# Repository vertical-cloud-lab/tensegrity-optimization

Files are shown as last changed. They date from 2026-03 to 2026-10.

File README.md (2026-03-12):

# BYU Mentored Research Grant Proposal: Multi-Material 3D-Printed Tensegrity Structures

**Bayesian Optimization of Multi-Material 3D-Printed Tensegrity Structures for Energy Absorption**

BYU Ira A. Fulton College of Engineering — Mentored Research Grant Proposal

## Overview

- **PI:** Jeffrey R. Hill, Mechanical Engineering
- **Co-PI:** Sterling G. Baird, Mechanical Engineering
- **Duration:** 2 years
- **Budget:** $25,000
- **Students:** 2–3 undergraduates + 1 graduate co-mentor
- **Focus:** Undergraduate mentored research

This proposal develops a multifidelity Bayesian optimization framework to design multi-material 3D-printed tensegrity structures (PLA struts + TPU tension elements) optimized for energy absorption. Undergraduate students fabricate and experimentally validate optimized designs through compaction tests, drop tests, and wave propagation measurements.

## Repository Structure

```
├── proposal.tex              # Main LaTeX document
├── references.bib            # BibTeX bibliography
├── sections/
│   ├── coverpage.tex         # MRG cover page (abstract, budget table, external funding)
│   ├── budget.tex            # Budget table and justification
│   └── biosketch.tex         # PI and Co-PI biographical sketches
├── Makefile                  # Build commands
├── .gitignore
└── README.md
```

## Building the Proposal

Requires a LaTeX distribution (e.g., TeX Live, MiKTeX) with `pdflatex` and `bibtex`.

```bash
# Using Make
make

# Or manually
pdflatex proposal
bibtex proposal
pdflatex proposal
pdflatex proposal
```

## Proposal Structure (≤5 pages + cover page, references, bio sketches)

- **Cover Page** — Title, PI/Co-PI, abstract, student counts, budget summary, relationship to external funding
- **Research Motivation & Overview** — Multi-material 3D-printed tensegrity + multifidelity BO
- **Background** — Tensegrity structures, Bayesian optimization, Mo et al. (2023) multifidelity framework
- **Student Research Project 1** — Simulation & Bayesian optimization
- **Student Research Project 2** — Fabrication, CAD, & experimental testing
- **Mentoring Environment** — Weekly meetings, graduate co-mentor, peer mentoring, progressive responsibility
- **Expected Research Outcomes** — UCUR, ASME IDETC, journal submission, NSF proposal
- **Potential Impact** — Protective equipment, packaging, aerospace applications
- **Timeline** — 4-semester project plan
- **Budget** — $25k (undergraduate wages, graduate wages, supplies, travel, other)
- **References** — (does not count toward page limit)
- **Bio Sketches** — Hill & Baird (does not count toward page limit)

## TODO

- [ ] Add figures (tensegrity schematic, BO loop diagram, test setup)
- [ ] Finalize PI/Co-PI bio sketch details (specific publications, appointments)
- [ ] Get feedback from co-PI / collaborators

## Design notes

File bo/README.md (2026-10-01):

# T-3_01 Sobol batch: print key, slicer files, and BO campaign script

This directory holds the key linking each printed T3-prism specimen ID to its
Sobol design parameters, for use when parsing drop data during the testing
campaign (issue [#98](https://github.com/vertical-cloud-lab/tensegrity-optimization/issues/98)),
plus the Bayesian-optimization script that ingests the campaign results and
suggests the next print batch.

## BO campaign files

- `t3_prism_bo_campaign.py`: Honegumi-templated Ax script (multi-objective,
  fully Bayesian SAASBO, batch, existing data, visualization). Ingests the
  measured drop results, attaches them as completed Ax trials, attaches
  printed-but-untested specs as pending trials, and records the next
  suggested batch. The rebound objective is the absolute energy returned to
  the payload per drop (`e_reb_mJ = e_rebound * m_printed * g * h`), computed
  from each article's own weighed mass, and its noise folds in the
  print-to-print mass scatter measured from the spec-08 triplicate. See the
  docstring for the objective rationale (why `t180` stays a ratio) and the
  seven documented deviations from the rendered template. From round 3 the
  search space also carries six print-process parameters, with the four
  filament-level ones taking one Sobol-drawn value for the whole batch; see
  the print-process section below. Run from the repo
  root: `python bo/t3_prism_bo_campaign.py --round 3`.
- `t3_prism_mass_model.py`: the as-printed mass model, and the
  constant-printed-mass projection built on it. **What round 1 actually held
  constant was solid mass, not volume and not printed grams**: PR #35's
  Route A uniformly re-scales each design until
  `rho_PLA * V_PLA + rho_TPU * V_TPU = 30.95 g` (the solid mass of the S0
  reference STLs), converged to 0.15 g on rendered STL volumes. All 9
  articles sit at that solid mass and still weigh 18.50 to 22.29 g, because
  PLA prints sparse while thin TPU cables print near solid and the PLA/TPU
  split swings from 20.0/10.9 g to 27.3/3.6 g across the batch. This module
  calibrates the gap in two stages (analytic volumes against the 9 rendered
  designs, then rendered solid grams against the 12 weighed articles using a
  wall-plus-infill term in the as-printed strut diameter) and inverts it, so
  a design can be projected onto a constant *printed* mass with a closed
  bisection and no slicer in the loop. Since 2026-08-26 the two infill
  percentages are inputs to that solve rather than fitted constants, because
  a sparser article has to be larger to weigh the same. Residual sd 0.378 g, at or below the
  0.457 g print-to-print scatter, versus 0.927 g for a flat pair of density
  factors. `python bo/t3_prism_mass_model.py` prints the calibration report
  and re-projects the 9 round-1 articles.

- `t3_prism_printed_mass_plate.py`: renders the actual print files (per-trial
  STL pairs, plate previews and the Bambu H2D multi-material project) for a
  solved constant-printed-mass suggestions CSV, at the CSV's own solved scale
  with no mass re-solve. See "Round-3 print files" below for what it produced
  and how the output was verified. `python bo/t3_prism_printed_mass_plate.py`
  (needs `openscad` and `xvfb`; about 25 minutes, mostly OpenSCAD).

- `t3_prism_slicer_settings.py`: reads the print-process settings back out of
  a Bambu Studio `.3mf` project (process profile, layer height, line width,
  sparse infill, wall loops, and per-filament nozzle temperature and max
  volumetric speed, plus any per-object or per-part overrides). It is what
  makes `AS_PRINTED_PROCESS` in the campaign script auditable rather than a
  hard-coded constant, and it is what round 4 should run on the round-3 plates
  to record what they were actually sliced at rather than what they were asked
  for. `python bo/t3_prism_slicer_settings.py bo/slices/*.3mf [--csv out.csv]
  [--raw]`.

- `t3-prism-bo-batch-drop-results.csv`: snapshot of the BO-ready
  `campaign_summary.csv` produced on PR #86 (branch
  `copilot/add-drop-test-protocol-again`, commit `642b8c0`, path
  `data/drop-tests/sobol-campaign/figures/campaign_summary.csv`): one row
  per tested specimen with objectives (mean and sd) and joined as-printed
  geometry. 8 of 9 specimens as of 2026-08-21; `amdjwm` has no known spec
  mapping and is skipped by the script until identified. The `ajhby6` row
  (spec 07, the specimen missing from the PR #86 snapshot) was appended on
  2026-08-24 from its Box upload, computed with the same PR #86 analysis
  script; see the round-2 section below for the fetch provenance.
- `t3-prism-bo-suggestions-round1.csv`: the recorded round-1 output of the
  script. Per suggested design: the base (shape) coordinates, the constant
  `mass_printed_g` target, posterior-mean predictions for both objectives,
  the implied rebound fraction at that mass (`pred_e_rebound_approx`, for
  comparison with the raw `e_rebound` column of the results CSV), and the
  as-printed geometry the constant-printed-mass projection produces
  (`scale`, `*_print_mm`, `solid_mass_g`) with PR #35's two printability
  checks evaluated on it (`envelope_ok` for the 250 cm^3 cylinder,
  `cable_bridge_ok` for the 3.0 mm TPU self-bridging floor). Violations are
  flagged, not dropped, exactly as in round 1.
- `t3-prism-bo-ax-client-round1.json`: full AxClient state (experiment,
  data, generation strategy) for reproducibility and warm-starting round 2.
- `figures/t3-prism-bo-round1-pareto.png`: objective-space view (tested
  articles labeled by print ID, the Pareto front through the non-dominated
  articles, and the suggested round-2 candidates at their predicted means),
  styled for slides. The parameter-space parallel-coordinates panel that the
  Honegumi template pairs with it was dropped on review (PR #102). The front
  drawn is the non-dominated set of the observed points, which for round 1 is
  the same three articles (`6lhxfy`, `6nheas`, `bpx68c`) that Ax's
  model-predicted Pareto set picks out. Redraw it without refitting the model
  (pandas + matplotlib only, no Ax install needed) with
  `python bo/t3_prism_bo_campaign.py --plot-only`. Styling follows the
  hand-made reference on PR #102: no legend box (series are named by
  leader-line callouts in the plot area), detached left and bottom spines,
  no gridlines, gray print IDs, horizontal y-axis label above the axis. Both
  axis labels mark the good direction with a down-arrow glyph rather than the
  words "lower is better" (PR #102 review); it is set as `ARROW_DOWN` in the
  script, and matplotlib falls through the sans-serif list per character if a
  machine's chosen face lacks U+2193. **Every figure written by either script
  is 300 dpi** (`FIGURE_DPI` in `t3_prism_bo_campaign.py`, imported by the
  diagnostics), so they hold up on a projector and in a printed deck. Print
  IDs are placed by a search that dodges the markers, the other IDs, the
  callout text, the callout leaders and the front line, weighted so that a
  label would rather cross a hairline than sit on top of words; nothing here
  is hand-positioned, because the point cloud moves every round.
- **Prototype, synthetic data.** Four stills and an animation showing the
  layout the campaign will want once round 2 comes back, written by one run of
  `python bo/t3_prism_bo_campaign.py --prototype-next-round`. No round-2
  article has been printed or dropped, so the outcomes are drawn from the
  model's own predictive distribution at 0.3 sd (a full draw scatters the
  batch off the panel) and recorded to
  `t3-prism-bo-round2-outcomes-PROTOTYPE-dummy.csv`. Replace
  `synthesize_round2_outcomes` with the measured campaign summary to turn this
  into the real figure.

  The four stills are the four points at which the figure is at rest, in
  slide order:

  1. `figures/t3-prism-bo-round2-start-PROTOTYPE.png`: the round-1 figure. Its
     front, its print IDs, and the orange suggested points.
  2. `figures/t3-prism-bo-round2-uncertainty-PROTOTYPE.png`: the predicted
     uncertainties at the suggested points, frozen before anything moves
     (PR #102 review): a horizontal and a vertical bar spanning plus or minus
     1 sd per objective, and a shaded oval through the same contour, both in
     faded shades of the suggestion orange. The sd is **1 posterior standard
     deviation of the model's noise-free objective prediction** (the square
     root of the diagonal of the covariance `TorchModelBridge.predict`
     returned when the batch was generated, averaged over the SAAS MCMC
     draws). It is epistemic model uncertainty, not a standard error of any
     sample of drops. Only the per-objective marginals were recorded to the
     suggestions CSV, so the oval is axis-aligned; the cross-objective
     covariance `predict` also returns was not saved. Several rebound-energy
     sds are taller than the panel and simply crop at the axes, which is the
     honest picture: the LOOCV diagnostic found no out-of-sample skill on
     that objective, and these ovals are the same fact drawn in objective
     space.
  3. `figures/t3-prism-bo-round2-predicted-vs-actual-PROTOTYPE.png`: each
     orange diamond (predicted) joined by a straight path to the open black
     circle where that article actually landed. No front and no print IDs. The
     round-1 front has been retired and the round-2 front has not been computed
     yet; the IDs are retired with it, because seventeen of them over the
     travel paths is the crowding the beat list exists to avoid (PR #102
     review). The uncertainty layer stays anchored at the predictions at ghost
     opacity, so predicted-band-versus-landing is readable. Identity comes
     back on still 4.
  4. `figures/t3-prism-bo-round2-front-final-PROTOTYPE.png`: the prediction
     layer gone, the print IDs back, and the front recomputed over both rounds.
     The frame to use when the point is the new front rather than how the model
     did.

  All four are **frames of one figure** rather than four separate drawings,
  exported at 300 dpi (3300 x 2100 px, with that dpi written into the PNG so
  PowerPoint places them at 11 x 7 in) and with no tight bounding box. That
  makes them the same pixel size and puts every element that survives a beat
  (the axes, the ticks, the axis labels, and each print ID) at the same pixel
  in all four, so
  they can go on four consecutive slides and be cross-faded or morphed without
  anything sliding. Drawing them independently could not guarantee that, since
  each panel would solve its own label placement; labels are laid out once,
  against the final frame, for the whole set.
- `figures/t3-prism-bo-round2-predicted-vs-actual-PROTOTYPE.gif` and
  `.mp4`: the same four stills played out in time, which is how it is meant to
  be shown. Choreographed one idea per beat, after the PR #102 review found
  the first cut had too much moving and too much text on screen at once:
  hold on the round-1 figure (1.3 s, still 1), retire the round-1 front, its
  callouts and every print ID with nothing else moving (0.9 s), grow the
  plus-or-minus-1-sd bars and ovals in and freeze so they can be read
  (0.7 s + 1.4 s, still 2), travel the
  diamonds to their measurements while the uncertainty layer fades to ghost
  opacity at the predictions (2.6 s), hold on
  predicted versus measured (1.7 s, still 3), clear the prediction layer and
  its uncertainties
  (0.9 s), redraw the new front as its own step, wiping in along the polyline
  and filling each article as it reaches it (1.3 s), bring every ID back at
  once now that nothing is moving, and rest (2.4 s, still 4). About 13 s. At
  most one callout is ever lit while anything is in motion, and nothing is
  labeled while anything is moving (eight IDs is fine on the round-1 slide,
  but carrying them through the travel while nine more arrive is not). The
  MP4 is 3300 x 2100 at 25 fps (h.264, yuv420p, so it plays in PowerPoint and
  Keynote as well as a browser), pixel-for-pixel the same canvas as the
  stills. Add `--no-animation` to write only the stills. The MP4 needs
  `ffmpeg` on PATH (`apt-get install ffmpeg`); without it the script falls
  back to a Pillow-written GIF and skips the MP4. The GIF is built from the
  MP4 with an ffmpeg palette pass (12 fps, 1280 px wide) and is for threads
  and this README, not for slides; use the MP4 there.

### Constant printed mass, and the `fit_out_of_design` kwarg it needs

The search space is 6-dimensional. The first five are PR #35's base Sobol
coordinates with the joint diameter frozen at 7 mm; since the projection
re-scales every dimension including the joint, those five fix the article's
*shape*. The sixth, `mass_printed_g`, fixes its *size*: the projection solves
for the uniform scale that hits that printed mass. Shape and mass together
determine the article exactly, which is what makes "hold the mass constant"
expressible at all.

That splits the space in two. The **fit space** carries `mass_printed_g` over
18.0 to 23.0 g, covering every weighed round-1 article. The **generation
space** pins it to the target (default 20.23 g, the weighed mass of the S0
reference `bpx68c`; `--target-mass-g` overrides). Round-1 data therefore sits
outside the generation space along the mass axis, so:

- the experiment is created on the fit space and the trials attached there,
  because `attach_trial` validates search-space membership and would raise
  long before any model exists;
- the search space is then narrowed, which needs
  `immutable_search_space_and_opt_config=False`;
- the SAASBO step gets
  `model_kwargs={"fit_out_of_design": True, "expand_model_space": True}`, so
  those out-of-design observations are still used to fit while `gen` stays
  inside the narrowed space (facebook/Ax#768). `fit_out_of_design` is
  deprecated after Ax 1.1.2, where `expand_model_space` alone is the live
  mechanism, so this pairing is correct for the pinned 0.5.0 and needs
  revisiting if the pin moves.

The generation slab is +/- 0.01 g rather than a `FixedParameter` or the
+/- 0.457 g print tolerance, for two separate reasons. A `FixedParameter`
would be stripped by Ax's `RemoveFixed` transform, taking the mass dimension
out of the model entirely, and the model needs it: attributing part of the
round-1 objective spread to mass rather than to shape is the whole point. And
a slab as wide as the print tolerance has an exploitable gradient, since
rebound energy scales with mass; with +/- 0.457 g, qNEHVI put all 9
suggestions on the light edge, choosing shapes at 19.77 g and then reporting
them at 20.23 g. The printer's tolerance is not a design variable.

One limitation this does not fix. Round-1 articles were built under the old
projection, so the same coordinates map to slightly different physical
articles now (re-projected scales move by up to 3.5 percent). Carrying
measured mass as the sixth parameter lets the model account for that instead
of silently averaging over it, but it is not the same as re-fitting on
as-printed geometry (facebook/Ax#3577, planned-vs-executed parameters, still
unimplemented upstream).

Resolved 2026-08-31: `bo/t3_prism_printed_mass_plate.py` takes exactly that
shorter path (this paragraph used to be the standing "re-point Route A at
printed grams" blocker). It renders each design's SCAD at its own base
coordinates and the CSV's solved `scale`, so the constant-printed-mass
projection the campaign computed is honored as-is and nothing re-solves onto
solid mass at render time. From round 3 the scale also depends on the
article's strut infill, which is why the CSV's solved value, not the shape,
is the input of record. See "Round-3 print files" below.

### Print-process parameters, and why the filament settings are one value per batch

Six slicer settings became design variables on 2026-08-26 (PR #102). They had
been stock defaults nobody chose: both tested plates were sliced from Bambu's
`0.30mm Standard @BBL H2D 0.6 nozzle` process at 15 percent grid sparse infill,
2 wall loops, 0.30 mm layers and 0.62 mm line width, with PLA Basic at 220 C
and 30 mm^3/s and TPU 85A at 240 C and 2.5 mm^3/s. Those numbers are read
straight out of `Metadata/project_settings.config` in the two committed slicer
projects, and they are identical in both, so **all 17 tested articles sit at
one point of this six-dimensional space** and the round-3 batch is its
initialization rather than an optimization of it.

The bounds were tightened on 2026-08-31 (PR #102 review): the first draw of
the batch-wide filament settings landed at 247 C TPU at the high-flow
hotend's full 4.8 mm^3/s rating, which risked the #96 carbonization failure
and the untested flow ceiling in the same print. Every range now brackets
the proven operating point instead of reaching for the preset or hardware
limits. The original ranges (infill 10 to 60 %, PLA 200 to 235 C and 15 to
30 mm^3/s, TPU 230 to 250 C and 2.0 to 4.8 mm^3/s) are recorded here and in
the `PROCESS_SPECS` block so a later round can widen deliberately once one
round of process data exists.

| Parameter | Bounds | Set at | Slicer field | Why these bounds |
|---|---|---|---|---|
| `strut_infill_pct` | 12 to 35 % | 15 | sparse infill density, `-struts` part | brackets the stock 15; 35 keeps the printed-mass model near its one calibration point (its infill term is unvalidated differential physics) and keeps the constant-mass projection from shrinking dense articles onto the fixed-size sensor housings |
| `tpu_infill_pct` | 12 to 35 % | 15 | sparse infill density, `-cables` part | same range; still spans a soft to a firm captive core (the hollow lock ball photographed on issue #85) without leaving the mass model's comfort zone |
| `pla_nozzle_temp_C` | 212 to 228 C | 220 | PLA filament nozzle temperature | plus or minus 8 around the proven 220 (Bambu PLA Basic's own preset window is 190 to 240); cold plus fast risks underextrusion through the 0.6 nozzle, hot strings across the tendons, and neither failure needs to be found in a batch of test articles |
| `pla_flow_mm3_s` | 20 to 30 mm^3/s | 30 | PLA filament max volumetric speed | 30 is the vendor value both plates ran at and stays the ceiling; the floor is two thirds of it rather than the old half, so the batch cannot pair its coldest nozzle with a flow far from anything ever printed here |
| `tpu_nozzle_temp_C` | 235 to 245 C | 240 | TPU filament nozzle temperature | plus or minus 5 around the 240 both plates ran at (the generic Bambu TPU 85A @BBL H2D preset allows 200 to 250); the old 250 top was backed off because of the #96 hotend-carbonization history |
| `tpu_flow_mm3_s` | 2.2 to 3.6 mm^3/s | 2.5 | TPU filament max volumetric speed | 2.2 sits just below the 2.5 both plates ran at; 3.6 is 75 percent of the high-flow hotend's 4.8 mm^3/s rating (issue #96), so the round probes the new hotend's headroom without spending all of it in one go at an untested temperature |

Where those "set at" numbers come from, so they can be checked rather than
believed: `python bo/t3_prism_slicer_settings.py bo/slices/*.3mf` reads them
back out of the two committed slicer projects and writes
`t3-prism-slicer-process-settings.csv`. Both projects report the same process
profile and the same values on the two slots any object prints with (PLA on
extruder 1 at 220 C and 30 mm^3/s, TPU on extruder 2 at 240 C and
2.5 mm^3/s), and neither carries a single per-object or per-part override.
`slices/t3-prism-bo-round1.H2D-MM-PLAstruts-TPUcables_manual-supports.3mf` is
the r2d2c plate, posted to issue #98 on 2026-08-24 and byte-identical
(sha256 `4a7bc1a0…`) to the copy committed at `8809b25` on the
`copilot/get-bambu-sliced-print-t3-prism` branch; it is copied here so this
branch can be checked without fetching that one.

Two things the extractor turns up that are worth acting on independently of
the BO. The TPU slot still uses the `Bambu TPU 85A @BBL H2D 0.4 nozzle`
preset, left over from before the high-flow hotend went in on 2026-08-17, and
that preset caps the temperature window at 240 C; the generic
`@BBL H2D` preset allows 200 to 250, so the round-3 batch, which asks for
244 C, needs the preset swapped, not just the number typed. And the TPU had
been running at 2.5 mm^3/s on a hotend rated for 4.8, the headroom
@me-madsen noted on 2026-08-18; the round-3 draw lands on 3.6, so this batch
spends most of that headroom (75 percent of the rating) while holding some
back for a round that has seen 3.6 work.

Watch the top of the TPU temperature range in particular. Issue #96 traced a
multi-week printer outage to processing lubricant carbonizing in the hotend on
long hot TPU prints; that history is why the range now tops out at 245 C
rather than the preset's 250, and a plate near that top is still the one to
check mid-print for a flow taper.

**Speed is parameterized as max volumetric speed, not mm/s, because that is
the setting that binds.** The process profile asks for 200 mm/s on the outer
wall and 350 mm/s on sparse infill, which at 0.62 x 0.30 mm of extrusion is 37
and 65 mm^3/s: both materials already run flow-capped everywhere, so the mm/s
fields do nothing. Bambu Studio also has no per-material mm/s at all (speeds
belong to the process and are shared by both filaments), while the volumetric
cap is per filament. Every table reports the equivalent mm/s next to it
(`pla_speed_mm_s`, `tpu_speed_mm_s`), which is `flow / (0.62 * 0.30)`.

#### One filament setting for the whole batch

Two of the six can vary between articles on one plate and four cannot.

- **Article-level.** Sparse infill density is a per-object and per-part
  setting. Each specimen is one Bambu object holding a `<spec>-struts.stl`
  part on extruder 1 and a `<spec>-cables.stl` part on extruder 2 (confirmed
  in `Metadata/model_settings.config` of the committed project), so a per-part
  override addresses PLA and TPU separately. Without the override both parts
  inherit one global value, which is why neither had ever been chosen.
- **Filament-level.** Nozzle temperature and max volumetric speed are filament
  settings, and every object on a plate is built layer by layer through the
  same two nozzles. One print job carries one value of each.

The first version of this batch (commit `265bfe5`) bought within-round
variation on the four filament axes by splitting the batch across three
plates sliced at three different settings. On review (PR #102, 2026-08-31)
that split plot was replaced with the simpler design the batch now uses:
**one value of each filament setting for the whole batch.** Formally they are
the optimal predicted print parameters of the batch's best-predicted
specimen, applied everywhere; because all 17 tested articles sit at a single
point of the process space, an "optimal predicted" setting does not exist yet
and the values are drawn by Sobol sampling within the bounds instead (next
section). The best-predicted specimen is the candidate whose predicted means
add the most dominated hypervolume to the measured front at the reference
point (1.35, 15 mJ) used for the round-2 front-expansion numbers; when no
candidate's predicted means improve the front, which is the humble-model
case, the tie-break is the lowest predicted `t180`, the campaign's primary
endpoint per the Edison round-2 review. The `best_predicted` column in the
suggestions CSV and the recipe name it.

What this trades away, knowingly: the round learns nothing about the four
filament axes (one level of each), where the split-plot version bought three
confounded-with-plate levels. What it buys: one print job instead of three,
no plate-level confound inside the round, and a batch whose nine articles are
strictly comparable on shape and infill. Variation on the filament axes now
accrues across rounds instead of within one, which is why the draw comes from
a sequence (below) rather than an independent random point each time.

Plates are now nothing but floor space. Articles go onto as few plates as
they pack onto, chunked largest-first (with identical settings everywhere
there is no confound left for the deal to protect); the nine round-3 articles
fit one plate at about 218 x 218 mm of the usable 290 x 310 mm, so the batch
is one print job. A plate that does not fit is called out to be split rather
than quietly repacked. `--freeze-process` still pins all six parameters at
the as-printed point and gives back the shape-plus-mass batch of rounds 1
and 2.

#### Why Sobol and a Latin hypercube instead of the acquisition function

qNEHVI also returns values for these six parameters, and they are worth
nothing. With every observation at one process point the posterior is flat
along those axes, so the acquisition surface is flat too and whatever the
optimizer returns there is an artifact of its starting points. The run prints
the spread it produced before replacing it.

The replacement differs by level. The four filament settings are one point
drawn from a seeded scrambled Sobol sequence over their bounds: for a single
point that is a uniform random draw with a reproducible seed, which is all
"chosen" can honestly mean with no data to prefer one setting over another,
and Sobol rather than a plain RNG so that a later batch still lacking process
data continues the same sequence (batch N takes point N minus 3), keeping the
accumulated batch-level points spread out instead of clumping the way
independent draws can. The two infill densities are a centered Latin
hypercube across the nine articles, stratifying each axis into nine bins.
Every coordinate is rounded onto the slicer field's own resolution (1 C, 1
percent, 0.1 mm^3/s) so the number in the table is the number typed into
Bambu Studio, with no planned-versus-executed gap.

The run then re-queries the model at the delivered points and prints how much
the substitution moved its predictions, against the model's own posterior sd,
so the cost is measured rather than assumed. A GP cannot learn a response
from an input that never varied, so what is left along those six axes is the
SAAS prior's residual sensitivity, not evidence, and the substitution trades
a fraction of one posterior sd of prior noise for process coordinates the lab
can actually type. If a later round prints this number and it has grown a
lot, that is the signal that the model has begun to learn the process axes
from data, and the substitution should be dropped in favor of letting the
acquisition choose.

#### Infill feeds back into the printed-mass projection

Strut infill is not only a material property, it is a size lever. At a fixed
printed mass a sparser article has to be larger, so the projection in
`t3_prism_mass_model.py` now solves the scale given the infill: over the
tightened round-3 bounds (12 to 35 percent) the strut density moves the
solved scale by about -5 to +1 percent and the TPU density by under
1 percent (run `python bo/t3_prism_mass_model.py` for the sweep). Both terms
are differentials around
the 15 percent nominal, so at that setting the calibrated model is reproduced
exactly and every number it produced before is unchanged. Neither term has
been validated: no article has ever been printed at any other infill. **The
round-3 weighings are the first data that can check them, and they should be
fed back into the calibration before round 4.**

### Round-3 batch (the first with print-process parameters)

This is run 3 of the script, and it supersedes run 2. Both ingest exactly the
same 17 tested articles; run 2 produced a candidate batch on the six-parameter
space that was never printed, and run 3 produces the batch that is, on the
twelve-parameter space. That is why the physical batch number and the run
number are the same here and `--batch-number` exists: it names the batch in
the figure callout and the recipe title, and defaults to `--round` plus one,
which is only right when every previous run's batch went to a printer.

```bash
python bo/t3_prism_bo_campaign.py --round 3 --batch-number 3
python bo/t3_prism_bo_campaign.py --round 3 --batch-number 3 --plot-only \
    # redraws the Pareto panel, the process-space panel and the recipe from
    # the recorded CSV, no Ax install and no refit
```

The one option worth knowing about: `--freeze-process` gives back the
shape-plus-mass batch of rounds 1 and 2. The earlier `--plates` and
`--control-plate` options went away with the split plot (they set how many
filament levels the round bought, and there is now exactly one). One thing
that leaves uncovered, worth saying out loud: with a single filament level, a
round-level batch effect and the filament-setting effect are fully confounded
in this round's data. The control that remains is the one the Edison round-2
review recommended anyway, bracketing the drop sessions with a re-tested
reference article, which is independent of how the batch is sliced.

- `t3-prism-bo-suggestions-round3.csv`: the batch to print. One row per
  article: plate (floor space only), a `best_predicted` flag naming the
  specimen the batch-wide filament settings formally belong to, base shape
  coordinates, the constant `mass_printed_g` target, the six process
  coordinates (four of them identical on every row by construction) plus the
  two derived mm/s speeds, posterior-mean predictions for both objectives,
  and the as-printed geometry the constant-printed-mass projection produces
  at that article's own infill (`scale`, `*_print_mm`, `footprint_d_mm`,
  `solid_mass_g`) with PR #35's two printability checks evaluated on it.
  Violations are flagged, not dropped, the same as in rounds 1 and 2.
- `t3-prism-bo-round3-plate-recipe.md`: the same batch written as a print
  recipe. The filament settings stated once for the whole batch, per-part
  infill overrides and as-printed geometry per article, and a packing check
  per plate. This is the file to work from at the slicer.
- `t3-prism-bo-ax-client-round3.json`: full AxClient state. The nine delivered
  articles are attached as pending trials, so round 4 warm-starts from the
  batch that is actually going to the printer rather than from the raw
  acquisition output.
- `figures/t3-prism-bo-round3-pareto.png`: the objective-space view in the
  usual grammar, 17 tested articles and the 9 suggestions at their predicted
  means.
- `figures/t3-prism-bo-round3-process-space.png`: one strip per process
  parameter, showing the single black circle where all 17 tested articles
  sit, nine orange diamonds on each infill axis, and a single orange diamond
  on each filament axis (one value for the batch).

### Round-3 print files (STLs and the H2D project)

Generated 2026-08-31 by `t3_prism_printed_mass_plate.py` from
`t3-prism-bo-suggestions-round3.csv`. The script renders each article from
the canonical `cad/t3-prism/t3-prism.scad` at its base coordinates and the
CSV's solved constant-printed-mass scale, so these files are the suggestions
CSV made physical: no Route A re-solve onto solid mass happens anywhere,
which is the mechanism that made round 2's printed masses spread 17.3 to
22.5 g predicted while the model thought mass was held. The SCAD is a
byte-identical copy of `copilot/get-bambu-sliced-print-t3-prism` commit
`dbb5011`, verified unchanged since the commit that rendered the printed
round-1 BO plate, so the geometry conventions match both tested plates and
the mass calibration. The STL helpers, plate layout and 3mf assembly are
adapted from PR #35's `t3_prism_sobol_batch.py` on that branch;
`cad/t3-prism/flatten_bambu_profile.py` and `patch_mm_extruder.py` are
byte-identical copies of its helpers.

The files:

- `per-specimen-stls/t3-prism-bo-round3-tNN-{struts,cables}.stl`: 18
  plate-positioned STLs, one PLA/TPU pair per article, named by Ax trial
  number (t28 to t36) rather than plate position so no raster-order
  inference is ever needed to map an article back to its design (the
  round-2 print key needed a photo shoot to settle exactly that).
- `slices/t3-prism-bo-round3.H2D-MM-PLAstruts-TPUcables.3mf`: the Bambu
  Studio project, one object per trial (named "Trial 28" ... "Trial 36" in
  the object list), struts part on extruder 1 and cables part on extruder 2.
  Profiles are the ones the lab actually prints with (H2D 0.6 nozzle
  machine, `0.30mm Standard @BBL H2D 0.6 nozzle` process, PLA Basic 0.6
  nozzle filament), and the TPU filament is already the recipe's required
  `Bambu TPU 85A @BBL H2D` preset (not the 0.4 nozzle variant), so no
  preset swap is needed when opening this file. The batch filament settings
  are baked into the project (PLA 217 C at 20.5 mm^3/s, TPU 244 C at
  3.6 mm^3/s, initial-layer temperatures set to the same values) and every
  part carries its article's sparse infill density as a per-part override.
  Two things still to do in Bambu Studio: **verify the overrides survived
  the import** (select a part; its settings list should show "Sparse infill
  density" with the per-article value; if not, set the 18 values by hand
  per the plate recipe) and **paint the supports on manually** (supports
  are off in the project, as in every round).
- `t3-prism-bo-round3-designs.csv`: the manifest. One row per article with
  the design coordinates, solved scale, as-printed geometry, rendered solid
  grams per material, the printed-mass verification below, measured
  footprint and plate position, and the STL file names.
- `t3-prism-bo-round3-plate.json`, `t3-prism-bo-round3.scad`,
  `t3-prism-bo-round3-{plate,iso}.png`: layout metadata, the preview
  wrapper, and the two preview renders.

Verification, from rendered STL volumes pushed back through the calibrated
printed-mass model at each article's own infill: predicted printed mass runs
19.89 to 20.50 g against the 20.23 g target, worst deviation 0.34 g, inside
the model's own 0.38 g calibration residual and the 0.457 g print-to-print
scatter. That is the accuracy limit of the mass model, not of the render.
The rendered-volume check also cross-checks stage 1 of the calibration:
rendered solid masses agree with the analytic model to within 0.5 g on all
nine articles. The infill terms of the model remain unvalidated until this
batch is weighed; feed the weighings back into the calibration before round
4 (the manifest's `printed_g_est` column is the prediction to score them
against). Measured footprints (69 to 88 mm, key-seat overhang included) pack
as a 3x3 grid of 254.5 x 263.5 mm inside the 290 x 310 mm usable area, so
the plate is one print job as intended.

## Round-3 drop data (the drran prints, sessions 2026-09-02/03)

The round-3 plate was printed twice by Jinkwan (ctrhjk): print 1 is the
nine `drran1`-`drran9` articles (print log with masses, RH and photos on
issue #98, 2026-09-02), print 2 is `2dran1`-`2dran9` (same log format,
2026-09-05). The drop sessions for print 1 are on Box under
`Drop Test Data/9-03-2026 - drran` (20 drops per article, 60 in,
arrangement B); print 2 has no sessions yet. The per-drop numbers here are
a snapshot of the PR #86 branch's `data/drop-tests/drran-checkin/` output
(commit `308554e`, the standing campaign pipeline: validity filter, 2-drop
warm-up discard, T-drift watch), not a re-analysis.

Files:

- `t3-prism-bo-round3-drop-results.csv`: campaign summary, one row per
  drran article, plus as-printed geometry, weighed mass, specimen index and
  trial. Same schema as the round-2 results file with a trailing `trial`
  column.
- `t3-prism-bo-round3-per-drop-metrics.csv`: stabilized per-drop t180 and
  e_rebound (18 rows per article: 20 valid captures minus the 2-drop
  warm-up).
- `t3-prism-bo-round3-print-key.csv`: all three prints, 27 articles, with
  masses, plate positions, defects and the trial mapping. The third print
  is `dran31`-`dran39` (print log with masses and photos on issue #98,
  2026-09-29; no drop sessions yet). Its print files first named those
  articles `3dran1`-`3dran9`, which is not what the lab put on them, so
  `3dranN` in anything written before 2026-10-01 means `dran3N`.
- `t3-prism-bo-round3-predictions.csv`: byte copy of the suggestions CSV
  the plate was rendered from (commit `d119a54`), so predicted-vs-measured
  is always drawn against what the model claimed at generation time.
- `t3-prism-bo-round3-reprint-drop-results.csv` and
  `t3-prism-bo-round3-reprint-per-drop-metrics.csv`: the same two files
  for the 2dran reprint sessions (next subsection).
- `t3-prism-bo-round3-repeatability.csv`: the nine drran/2dran design
  pairs side by side (masses, t180, rebound energy, input dv, health and
  drift flags per print).

The ID-to-trial mapping is photo-confirmed. The plate's designs are
visually distinct (trial 35 is the only high-twist article, 29 the
tallest, 32 the widest, 31 narrow-tall, 34 short with thick cables, 36
thin-cabled, and 28/30/33 a deliberately identical thin-strut/fat-cable
trio differing only in infill), and the #98 print-log photos match every
cell under the same back-left-to-front-right raster the r2d2c batch used.
The trio's internal order rests on the raster plus the trial-28 mass match
(19.88 g weighed vs 19.89 predicted); their shapes are identical, so a
within-trio swap would only relabel infill values.

What the weighings say about the mass model (its first data at non-15%
infill and off-nominal filament settings): the constant-printed-mass
projection collapsed the batch's mass spread to CV 1.7 percent (19.24 to
20.06 g), against 5.9 percent in round 1 and 8.6 percent predicted for the
round-2 plate, with a systematic -0.52 g bias against the 20.23 g target
(print 2 ran +0.27 g heavier, mean 19.86 g, same 1.8 percent CV). The
residual sd around the bias is 0.25 g, inside the model's 0.38 g
calibration residual, so the shape of the model held and the offset is a
flow-rate effect of the new filament point (PLA 217 C at 20.5 mm3/s vs the
220 C / 30 mm3/s calibration plates) plus infill-term error.

Splitting those two candidates with both prints' weighings (2026-09-07,
round-4 run): regressing the print-averaged residual on the two slicer
infill settings gives slopes of -2.1 +/- 1.6 g (struts) and -1.5 +/- 1.6 g
(TPU) per 100 percentage points, |t| < 1.4, so over the actual 13 to 34
percent spread there is no detectable residual-vs-infill trend and the
model's differential infill terms pass their first test. The level offset
is therefore a print-session effect, and it wobbles between sessions:
-0.52 g (drran) vs -0.25 g (2dran) at byte-identical settings, a 0.27 g
swing between two prints of the same plate. The round-4 projection keeps
the round-1/2 calibration unchanged (its job is within-batch consistency,
which held at CV 1.7 to 1.8 percent); a recalibration that absorbs the
level needs a per-session or per-filament-point term, not a re-fit of the
infill/wall parameters the new data just validated, and is carried to
before batch 5.

Two measurement caveats carried from the drran check-in (PR #86 comment,
2026-09-05): `drran8` is T-drift flagged (+0.092 percent per drop, a mat
warm-up signature, not the r2d2c2 mount signature; its 0.980 mean is
provisional and its e_rebound mixes a double bounce at +39 and +70 ms),
and `drran7` shows no clear ballistic landing, so its e_rebound is an
envelope reading rather than hop physics. Both enter the ingestion as
recorded, with the inflated sds; the loader prints the drift warning.

Figure set (same registered four-still grammar as the round-2 delivery,
plus GIF/MP4; predictions from the frozen table, landings from the
measured summary, existing layer = all 17 round-1/2 articles):

```bash
python bo/t3_prism_bo_campaign.py --measured-round3             # absolute mJ
python bo/t3_prism_bo_campaign.py --measured-round3 --per-gram  # mJ/g display
```

Front over all 26 tested articles: `6lhxfy`, `r2d2c7`, `drran8`,
`r2d2c1`, `drran5`, `drran3`, `r2d2c6` (per gram, `bpx68c` and `ajhby6`
rejoin and `drran3` displaces `r2d2c6`). Round 3 added three front
members and knocked the drift-contaminated `r2d2c2` off. Note that
`--plot-only --round 3` now draws the round-3 measured articles among the
observed points as well as the batch's orange diamonds, so the committed
pre-measurement `t3-prism-bo-round3-pareto.png` is a generation-time
artifact; the measured story is this figure set.

### Round-3 reprint drop data (the 2dran prints, sessions 2026-09-05/09)

The round-3 plate was printed twice. The second print's nine articles
(`2dran1`-`2dran9`, print log 2026-09-05 on issue #98) were drop-tested
on 2026-09-05/08/09, 20 drops each, same rig and protocol, so `2dranN`
is a second physical article of `drranN`'s design (same plate cell,
same trial, its own weighed mass; the round-3 print key covers both
prints). Snapshot from the PR #86 branch's `2dran-checkin` record
(commit a10d890): `t3-prism-bo-round3-reprint-drop-results.csv` (batch
summary with T-drift columns; `2dran6` is drift-flagged) and
`t3-prism-bo-round3-reprint-per-drop-metrics.csv` (162 stabilized rows
after the standard validity filter and 2-drop warmup discard).

These are the campaign's first design-level replicates, and they are
ingested as nine separate Ax trials rather than pooled with `drran`:
feeding the raw repeats is what lets the model infer the noise floor
that the per-drop SEM understates (repeated inputs are the standard Ax
mechanism for that). Pair statistics, tabulated in
`t3-prism-bo-round3-repeatability.csv`:

- **t180**: reprints read +0.028 +/- 0.019 higher than the first print
  (eight of nine pairs; the 2dran sessions ran on a settled mat at
  lower input dv, so session state and print variation are
  confounded). After that shift the per-article between-print sd is
  roughly 0.013, against a within-session SEM of about 0.001, so the
  SEM the fit used to carry understated the repeat noise by an order
  of magnitude. Neither round-3 extreme replicates: `drran7`'s 1.251
  amplification reads 1.029 on the reprint and `drran8`'s 0.980
  attenuation reads 1.011, matching the seat-artifact reading in the
  PR #86 record.
- **Rebound energy**: pair ratios span 0.38x to 2.9x (between-print sd
  roughly 4.5 mJ), and the within-batch rebound ranking does not
  survive the reprint (rank correlation -0.18 across the nine pairs).
  At this batch's design spread, rebound is dominated by
  print/seat/session noise.

Display convention on the Pareto panels: a repeated design plots once,
at the mean of its prints, labeled `drranN x2` with a figure footnote,
and the measured front used to rank suggestions is taken over those
design-level means. The fit, the committed CSVs and the measured-round
figure sets stay per-session.

## Round-4 batch (first refit on all 26 articles, 2026-09-07)

Generated with `python bo/t3_prism_bo_campaign.py --round 4
--batch-number 4`: SAASBO refit on all 26 tested articles (8 round-1 +
9 r2d2c + 9 drran; `amdjwm` still unmapped, specs 03/06 attached as
pending), qNEHVI batch of 9, every article projected onto 20.23 g
printed. Files: `t3-prism-bo-suggestions-round4.csv` (the batch),
`t3-prism-bo-round4-plate-recipe.md` (slicer walkthrough),
`t3-prism-bo-ax-client-round4.json` (snapshot carrying the delivered
batch as pending trials), figures
`t3-prism-bo-round4-{pareto,process-space}.png`. The print files
(18 per-trial STLs and the H2D project) were rendered 2026-09-08 the
same way round 3's were; see "Round-4 print files" below.

Two process-handling changes relative to round 3, both in the campaign
script:

- **Infill is now acquisition-chosen per article** (rounded to the
  slicer's 1 percent grid), because round 3 gave the model its first
  real variation on both infill axes (13 to 34 percent, including the
  t28/t30/t33 clone trio). The Latin-hypercube fallback remains for any
  future axis with no training variation.
- **The filament point is Sobol point 1 of the same seeded sequence**
  (batch N takes point N-3): PLA 226 C at 29.5 mm3/s, TPU 236 C at
  2.6 mm3/s. Roughly the opposite corner from round 3 (PLA hotter and
  near the proven flow, TPU cooler and slower), which is what a
  low-discrepancy sequence is for. The two batch-level filament points
  measured so far moved together and with everything else that changed
  between rounds, so they stay confounded and the model is still not
  asked to rank them; replacing the acquisition's filament coordinates
  moved its predictions by at most 21 percent (t180) and 9 percent
  (rebound) of one posterior sd, printed by the run.

The batch itself splits into two families. Trials 37, 39, 41, 43 are
wide, high-twist, thin-cable attackers (R 40, twist 79 to 80 degrees,
base cable 3.0 mm, predicted t180 0.93 to 0.95): the model chasing the
`6lhxfy` corner, now backed by `drran8` (the round-3 twist article and
its only attenuator). Trials 38, 40, 42, 44, 45 are tall, low-twist,
thick-cable rebound designs (R 25, H 110, cable 5.5 mm, predicted
rebound 6.4 to 7.6 mJ). Trials 40 and 44 differ by one percentage point
of strut infill and are otherwise the same article, i.e. the
acquisition spent a slot on a deliberate replicate, and 38/42 differ
mainly in strut diameter. Best-predicted is trial 37, and for the first
time in the campaign the best candidate's predicted means improve the
measured front (predicted hypervolume gain +0.232 at the (1.35, 15 mJ)
reference); every earlier round's batch was generated under a model
that predicted no front improvement at all.

Printability flags, carried not dropped as always: 4 of 9 under the
3.0 mm cable self-bridging floor (37, 39, 41, 43, printed cables 2.51
to 2.78 mm; round 1's two sub-floor articles both showed tendon string
defects, so expect the same), 2 over the 250 cm3 envelope (39, 43), and
3 end caps below the 20.1 mm smallest-printed floor (38, 42, 45; check
the sensor housings fit in the slicer). The whole batch packs one plate
(263 x 263 mm of 290 x 310 usable).

One number worth keeping: across all 26 tested articles corr(mass,
t180) is now 0.07, against 0.83 over round 1 alone. The constant-mass
rounds did their job; printed mass no longer explains transmissibility,
shape and process do.

### Round-4 print files (STLs and the H2D project)

Generated 2026-09-08 by `t3_prism_printed_mass_plate.py --designs-csv
t3-prism-bo-suggestions-round4.csv --out-prefix t3-prism-bo-round4`,
the same path that produced the round-3 print files (see that section
for the provenance of the SCAD, the projection, and the 3mf assembly;
nothing about the mechanism changed). The files:

- `per-specimen-stls/t3-prism-bo-round4-tNN-{struts,cables}.stl`: 18
  plate-positioned STLs, one PLA/TPU pair per article, named by Ax
  trial (t37 to t45).
- `slices/t3-prism-bo-round4.H2D-MM-PLAstruts-TPUcables.3mf`: the
  Bambu Studio project, one object per trial ("Trial 37" ...
  "Trial 45"), struts on extruder 1 and cables on extruder 2, with the
  round-4 filament settings baked in (PLA 226 C at 29.5 mm^3/s, TPU
  236 C at 2.6 mm^3/s, initial layers the same) and all 18 per-part
  sparse-infill overrides (verified by unzipping the committed file).
  This batch's TPU temperature is inside the old 0.4-nozzle preset's
  window, so no preset swap is strictly needed, but the project
  carries `Bambu TPU 85A @BBL H2D` anyway for consistency with round
  3. Same two manual steps as always: verify the overrides survived
  the import, and paint the supports on (supports are off in the
  project).
- `t3-prism-bo-round4-designs.csv` (manifest),
  `t3-prism-bo-round4-plate.json`, `t3-prism-bo-round4.scad`, and the
  `-{plate,iso}.png` previews.

Verification, rendered STL volumes pushed back through the calibrated
printed-mass model at each article's own infill: printed_g_est runs
19.92 to 20.64 g against the 20.23 g target, worst deviation +0.41 g
(trial 45), marginally above the model's 0.38 g calibration residual
and below the 0.457 g print-to-print scatter. Note the calibration is
still the round-1 weighings by construction (`calibrate()` reads the
round-1 print key only), which is the same model that solved the
suggestions CSV; the drran/2dran session offsets (-0.52 and -0.25 g
per article at byte-identical settings) sit on top of these estimates,
so expect the actual weighings to come in a few tenths of a gram below
printed_g_est if that flow effect persists at the round-4 filament
point. Feeding all three rounds' weighings into a session-aware
recalibration is still the standing to-do before round 5.

The plate packs by measured per-axis mesh extents (a change made this
round; square bounding-circle cells wasted ~20 mm of x): a 3x3 grid of
255.4 x 275.9 mm inside the 290 x 310 mm usable area, the whole grid
kept inside both nozzles' reach (the H2D's right/TPU nozzle cannot
print left of x = 25 and the left/PLA nozzle cannot print right of
x = 325, per the machine profile's `extruder_printable_area`), and the
wipe tower pinned at (287, 110), width 10 mm, in the strip right of
the grid. The printability warnings from the batch section stand: end
caps below 20.1 mm on trials 38/42/45, cables below the 3.0 mm TPU
bridging floor on 37/39/41/43.

New verification this round: the committed project slices headlessly
to completion with the lab's own slicer version (Bambu Studio
v02.07.01.62 CLI, the setup validated on the issue #108 batching
branch): exit 0, one plate, estimated 16 h 57 m, 168.9 g PLA + 73.6 g
TPU including tower, purge and brims
(`t3-prism-bo-round4-slice-check.json` is the record). That is the
gcode-level check flagged as "worth doing" since round 3, and it
caught four real problems on the way in, each now fixed in the
generator: the assembler's auto-arrange had rotated the whole plate
~90 degrees so every article sat outside the frame the layout was
computed in (fixed by forcing the identity build-item transform); 1.4
mm of the leftmost article's TPU was beyond the right nozzle's reach
(fixed by the measured reach shift); the wipe tower defaulted to
x = 15, deep inside the TPU-unreachable zone (fixed by the explicit
tower placement, sized so the ~19 mm toolchange wipe pad right of the
tower body also stays inside the left nozzle's reach); and the
assembled project carried single-extruder flush metadata plus a
Manual filament-to-nozzle map that the H2D CLI rejects (fixed by
`_patch_h2d_state`, which writes the dual-nozzle machine state and the
`Auto For Flush` grouping every file the lab has actually printed
uses). Two caveats: the lab's production gcode will differ because
supports still get painted on (re-slicing in the GUI as always), and
the committed round-3 project predates these fixes, so it would fail
the same headless check even though it printed fine twice through the
GUI; it stays byte-stable as the record of what was printed.

## Round-4 drop data (the corny prints, sessions 2026-09-12/14)

The round-4 plate (trials 37-45, printed as `corny1`-`corny9`) was drop
tested by @ctrhjk on 2026-09-12 (corny1-3) and 2026-09-14 (corny4-9): 20
valid captures per session, 60 in onto the 0.5 in mat, all 180 captures
clean. Raw data lives in the Box `Drop Test Data` folder; the per-drop
numbers here are snapshotted from the PR #86 branch's corny check-in
analysis (`data/drop-tests/corny-checkin/` at commit `741d3c3`), which
runs the standing campaign pipeline (validity filter, 2-drop warmup
discard, T-drift watch) unchanged. Files, same schema as rounds 2-3:

- `t3-prism-bo-round4-drop-results.csv`: the nine-session campaign
  summary joined to the as-printed geometry and weighed masses,
  ingestion-ready (the loader computes `e_reb_mJ` from each article's
  own weighed mass).
- `t3-prism-bo-round4-per-drop-metrics.csv`: stabilized per-drop t180
  and e_rebound, 162 rows (18 per specimen: drops 3-20).
- `t3-prism-bo-round4-print-key.csv`: the corny -> trial mapping with
  masses, RH, defects and the full mapping basis per row.
- `t3-prism-bo-round4-predictions.csv`: the suggestions CSV frozen at
  the state the plate was generated from (commit `535e7f3`; the printed
  STL geometry is `f2d82c8`, repositioned at `9fba359`), so
  predicted-vs-measured is drawn against what the model actually
  claimed.

The mapping is CONFIRMED by the lab's own key: me-madsen posted the
round-4 plate preview with each article's corny number handwritten on
it (PR #86 comment 5673269973, 2026-09-15). Read against the committed
plate coordinates: right plate column top-to-bottom = corny1/2/3,
center column = corny4/5/6, left column = corny7/8/9, i.e. raster 1..9
with the plate viewed right-edge-up, and it is the unique raster
orientation consistent with the physical evidence. Every independent
check agrees: the weighed masses split 20.15-20.58 g (corny1-5) vs
19.45-19.64 g (corny6-9) exactly along the manifest's per-family
printed_g_est clusters, all four attenuating sessions are corny6-9
(the wide high-twist family), and the ctrhjk print-log photos show the
same family split. Note for the git history: the first ingestion
commit (`c3aa44f`, made before this key existed) had the identical
family split but broke the within-family ties by plate raster in the
wrong orientation; the key corrects five of the nine assignments, and
every file from this commit on carries the confirmed mapping.

Results, sorted by t180 (predictions are the frozen `535e7f3` columns).
The headline pairing the key settles: the program-record attenuator
corny7 is **trial 37, the batch's best-predicted specimen**, the first
candidate in the campaign whose predicted means improved the measured
front when it was generated.

| ID | Trial | Mass g | t180 meas | t180 pred | e_reb meas mJ | e_reb pred | Note |
|---|---|---|---|---|---|---|---|
| corny7 | 37 | 19.62 | 0.803 | 0.93 +/- 0.13 | 9.37 | 8.5 +/- 5.9 | program record; best-predicted trial of the batch |
| corny9 | 43 | 19.46 | 0.877 | 0.94 +/- 0.15 | 18.10 | 9.6 +/- 5.7 | hop near detector cap |
| corny6 | 41 | 19.45 | 0.911 | 0.94 +/- 0.13 | 5.73 | 9.0 +/- 6.2 | erratic (CV 1.99 pct), low-confidence but attenuates under any reading |
| corny8 | 39 | 19.64 | 0.954 | 0.95 +/- 0.15 | 17.55 | 8.4 +/- 6.0 | rings at 764 Hz (all prior articles 300-420); e_rebound is a lower bound (hop at cap) |
| corny1 | 42 | 20.20 | 1.046 | 1.01 +/- 0.15 | 8.67 | 6.7 +/- 5.7 | seat gauge 1.24 advisory |
| corny4 | 44 | 20.56 | 1.047 | 1.01 +/- 0.14 | 4.31 | 6.5 +/- 5.7 | small-hop censored (<= 15 ms) |
| corny3 | 45 | 20.15 | 1.070 | 1.00 +/- 0.15 | 8.76 | 7.6 +/- 5.8 | seat gauge 1.17 advisory |
| corny2 | 38 | 20.21 | 1.085 | 1.01 +/- 0.15 | 9.24 | 6.5 +/- 5.6 | |
| corny5 | 40 | 20.58 | 1.088 | 1.01 +/- 0.14 | 8.48 | 6.4 +/- 5.5 | T-DRIFT flagged (output-side decline, -1.9 pct end to end); mean provisional |

Calibration read: unlike round 2's nine-of-nine optimism, the t180
misses are modest and structured. The wide family landed at -0.13 to
+0.00 of prediction (corny7 beat its band by 1.0 sd in the good
direction), the tall family at +0.04 to +0.08 (0.3 to 0.6 sd). The
posterior-mean regression the round-4 LOOCV warned about is visible
(every prediction sat near 1.0; the batch spread 0.80 to 1.09), but the
wide bands covered every outcome. Rebound: the two long-hop wide
articles (corny8/9, 17.6 and 18.1 mJ) landed 1.5 sd above prediction;
the rest inside 1 sd.

Masses: batch range 19.45-20.58 g measured (CV 2.1 percent), offset
-0.26 g +/- 0.24 vs the manifest's per-article `printed_g_est`, milder
than drran's -0.52 g at the round-3 filament point (round 4 ran PLA
226 C / 29.5 mm3/s, closer to the calibration's 220 C / 30). The
largest single residual is corny3/t45 at -0.49 g. The session-aware
mass-model recalibration remains the standing to-do before batch 6
solves its projection.

Standing caveats carried from the PR #86 check-in: every corny number is
single-seating (the between-seat rule wants a re-seat confirmation
before an attenuation record is treated as settled; corny7 first, then
corny9), corny5's mean is drift-provisional, and corny6 is erratic
without tripping the watch. corny8's e_rebound (and corny9's, at 66 ms
mean hop against the ~70 ms cap) are lower-bound-flavored: both enter
the fit as recorded, same convention as r2d2c8 in round 2.

Figure sets, same registered grammar as rounds 2-3 (four stills at
3300 x 2100 / 300 dpi plus GIF + MP4, absolute and per-gram):

```bash
python bo/t3_prism_bo_campaign.py --measured-round4              # absolute
python bo/t3_prism_bo_campaign.py --measured-round4 --per-gram   # intensive
```

writes `figures/t3-prism-bo-round4-{start,uncertainty,predicted-vs-actual,front-final}[-per-gram].png`
plus the matching `.gif`/`.mp4`. The measured front over all 35
articles is `corny7, corny6, drran5, drran3, r2d2c6` (per-gram:
`corny4` replaces `r2d2c6` at the low end); `corny7` dominates
`6lhxfy`, the best attenuator since round 1, on both objectives, and
`6lhxfy`, `r2d2c1`, `r2d2c7` and the drift-flagged `drran8` all leave
the front.

## Pareto-front evolution per batch

`t3_prism_front_evolution.py` recomputes the cumulative front and its
dominated hypervolume (reference t180 = 1.35, rebound = 15 mJ, the
reference every HV number on PR #102 uses) after each measured batch,
from the committed CSVs only:

| after batch | n | HV | gain | best t180 | min rebound | entered / left |
|---|---|---|---|---|---|---|
| 1 Sobol | 8 | 3.155 | baseline | 0.893 | 6.10 mJ | 6lhxfy 6nheas bpx68c ajhby6 |
| 2 r2d2c | 17 | 3.969 | +25.8 pct | 0.893 | 4.07 mJ | + r2d2c1/2/6/7, - 6nheas bpx68c ajhby6 |
| 3 drran | 26 | 4.007 | +0.9 pct | 0.893 | 4.07 mJ | + drran3/5/8, - r2d2c2 |
| 4 corny | 35 | 5.195 | +29.7 pct | 0.803 | 4.07 mJ | + corny6/7, - 6lhxfy r2d2c1 r2d2c7 drran8 |

Outputs `t3-prism-bo-front-evolution.csv` and
`figures/t3-prism-bo-front-evolution.png` (all 35 articles in gray, the
four cumulative fronts in deepening blue). The read: batch 2 grew the
front almost entirely on the rebound axis (r2d2c6's 4.07 mJ record,
still unbeaten), batch 3 only filled the knee (+0.9 percent; best t180
stuck at 6lhxfy's 0.893 for three batches), and batch 4 finally cracked
the t180 axis, the wide high-twist thin-cable family the acquisition
had been pushing toward since round 2. Every current front member is a
BO-chosen article: the last round-1 Sobol article left the front when
batch 4 landed.

Caveat added with the 2dran ingestion: this table predates the repeat
data and the design-mean display convention, so it scores batch 3 by
its first prints. Under design-level means the drran3/5/8 front claims
do not survive their reprints (see the repeatability section), so read
batch 3's "+0.9 percent" as an upper bound on a gain that was partly
print luck; the current front is the design-mean one quoted in the
round-5 section.

## Round-5 batch (refit on all 44 articles incl. the 2dran repeats, 2026-09-15)

Generated by `python bo/t3_prism_bo_campaign.py --round 5 --batch-number 5`
after the 2dran reprint ingestion: 44 completed trials (rounds 1-4 plus
the nine 2dran repeat sessions) + 2 pending, constant 20.23 g printed,
one plate (249 x 249 mm of the usable area). Files:
`t3-prism-bo-suggestions-round5.csv` (trials 55-63),
`t3-prism-bo-round5-plate-recipe.md`, `t3-prism-bo-ax-client-round5.json`,
`figures/t3-prism-bo-round5-{pareto,process-space}.png`.

**This batch supersedes the same-day 35-article batch (trials 46-54,
commit 829cf0a) generated before the reprint data was in the fit**; that
batch's print files (STLs, 3mf, slice check, commits 7ab85d9/e25ebf5)
were retired from the branch head so nobody prints them by accident,
and remain readable at their pinned commits. Nothing from trials 46-54
was ever printed. The trial numbering gap (46-54 abandoned in the Ax
ledger) is deliberate.

What the repeat data did to the acquisition is the story of the batch.
The nine drran/2dran pairs taught the model a between-print/session
noise far above the per-drop SEMs it had been fed (see the repeatability
section above), and the posterior flattened accordingly: predicted t180
spans just 1.018-1.030 +/- 0.11 across the nine candidates and predicted
rebound collapses to 8.73 +/- 4.10 mJ for every one of them (the rebound
model now claims nothing beyond the pooled mean, which is exactly what
pair ratios of 0.38x-2.9x support). Instead of going all-in on the
corny7 corner as the superseded batch did, the acquisition split:

- **Six tall low-twist thick-cable designs** (t55, t57, t58, t60, t61,
  t62: R 25, H 103-110 mm, twist 40-44 deg, strut 6.0 mm, cable
  5.3-5.5 mm), near-clones of one another and of corny4's corner (the
  measured low-rebound front anchor at 4.3 mJ), separated mainly by
  their infill pairs (strut 22-32, TPU 13-24 percent). With a noise
  floor this high, buying near-replicates in the best low-rebound
  region is rational acquisition behavior, and it doubles as the
  design-level replication Edison kept asking for.
- **Three wide high-twist thin-cable attenuators** (t56, t59, t63:
  R 39-40, twist 78-80 deg, strut 10.1-10.8 mm, base cable at the
  3.0 mm bound), keeping a foot in the corny6/7 record corner. These
  three project to 2.52-2.67 mm cables as printed (below the 3.0 mm
  TPU self-bridging floor, flagged not dropped, the same trade the
  corny attenuators made); the tall family is entirely clean, so the
  batch has 3 sub-floor articles instead of the superseded batch's 9,
  and zero envelope violations.

Best-predicted specimen: trial 55 (predicted t180 1.018 +/- 0.111), by
lowest predicted t180; no candidate's predicted means improve the
measured design-mean front, and the humility is the point: after the
repeats, the model no longer promises sub-0.95 t180 anywhere. Filament
settings are unchanged from the superseded batch (point 2 of the seeded
Sobol sequence, PLA 223 C / 24.7 mm3/s, TPU 240 C / 3.0 mm3/s, no
preset swap needed); the prediction shift from overriding the
acquisition's filament coordinates fell from 86 to 31 percent of one
posterior t180 sd, consistent with a flatter posterior leaning less on
the unidentified filament axes.

The measured front quoted by this run is the design-mean front (repeat
pairs collapse to their means): corny7 (0.803, 9.4 mJ), corny6 (0.911,
5.7), r2d2c2 (1.041, 5.6), corny4 (1.047, 4.3), r2d2c6 (1.055, 4.1).
The reprint means pushed drran3/drran5/drran8 off the front that their
first prints had claimed, and that re-admits r2d2c2, which still
carries its round-2 T-drift flag: treat its membership as provisional,
same as always.

Print files for trials 55-63 rendered 2026-09-16 (OpenSCAD 2021.01,
same toolchain as rounds 3-4):
`per-specimen-stls/t3-prism-bo-round5-tNN-{struts,cables}.stl` (18
plate-positioned solids named by trial),
`slices/t3-prism-bo-round5.H2D-MM-PLAstruts-TPUcables.3mf` (objects
"Trial 55" to "Trial 63", struts on extruder 1 / cables on extruder 2,
the batch filament settings and all 18 per-part sparse-infill overrides
baked in and verified by unzip), `t3-prism-bo-round5-designs.csv` (the
manifest), plus plate/iso preview PNGs. Rendered-mass verification:
`printed_g_est` 19.90 to 20.50 g against the 20.23 g target, worst
deviation 0.33 g, inside the mass model's 0.38 g analytic-to-rendered
residual. Unlike the one-sided rounds 3-4 pattern, the deltas split
cleanly by family (the six tall thick-cable articles estimate +0.18 to
+0.27 g, the three wide thin-cable ones -0.30 to -0.33 g), so the
residual is geometry-correlated rather than a level offset; worth
scoring against the weighings before round 6. Layout is comfortable
this round: no reach shift needed (all TPU already right of x = 30),
and grid PLA ends at 267.0 mm against the wipe tower at (287, 110),
20 mm of clearance where the superseded wide batch had under 5. The
headless slice check on the exact committed bytes (BambuStudio
v02.07.01.62 CLI, the lab's version, same recipe as round 4) is
recorded in `t3-prism-bo-round5-slice-check.json`: exit 0, one plate,
all 9 objects sliced, 376 layers, zero conflict/outside/nozzle lines,
model time 17h 7m, 159.9 g PLA + 83.6 g TPU including tower, purge and
brims (supports still get painted in the GUI, so production gcode runs
longer). Against the superseded batch's check that is +3.7 h and +33 g
of TPU: the six thick near-solid TPU cables print at the 3.0 mm3/s
flow ceiling and are the slow feature of the batch. Regenerate with:

```bash
python3 bo/t3_prism_printed_mass_plate.py \
    --designs-csv bo/t3-prism-bo-suggestions-round5.csv \
    --out-prefix t3-prism-bo-round5
```

(needs `openscad xvfb libfuse2` plus `numpy scipy pandas`, ~20 min;
writes the 18 per-trial STLs, the manifest with the rendered-mass
verification, and the H2D MM 3mf with the filament settings and all 18
per-part infill overrides baked; follow with the headless BambuStudio
slice check per the round-4 section).

## Replicate study (3 designs x 9 articles, proposed 2026-09-23, print files 2026-09-28)

The lab plans a repeatability study (PR #102, 2026-09-23): three
characteristic designs, one on the Pareto front, one further away, one
furthest away, three copies per plate, three identical plates, 27
articles. Plan, proposed picks (corny7 / corny8 / corny2, all round 4 so
one filament point reproduces the originals), pre-registered reference
values for the rank check, power analysis from the drran/2dran pair
noise, protocol, and the campaign decision rules live in
`t3-prism-replicate-study-plan.md`. Supporting script:
`t3_prism_replicate_study_power.py` (deterministic, reads only committed
data), outputs `t3-prism-replicate-study-{picks,power}.csv` and
`figures/t3-prism-replicate-study-power.png`. The lab accepted the
picks on 2026-09-28 (PR #102, @me-madsen).

Print files (2026-09-28): [`replicate-study/`](replicate-study/), with its
own [README](replicate-study/README.md) written as the print sheet. Three
plate projects, one per print job, each holding three copies of corny7
(trial 37), corny8 (trial 39) and corny2 (trial 38) with objects named
`[plate]sne[design digit][copy]` (for example `2sne73` = plate 2, corny7,
copy 3); the copy digit is the row (1 = back), and each plate is a Latin
square cycled across the plates, so every design sits in every one of the
nine positions exactly once over the study. Also there: the `dran3`
project for the third print of the round-3 plate (the committed round-3
project with only its object names changed, `dran3N` = the design of
`drranN` and `2dranN`; first committed as `3dranN` and renamed on
2026-10-01 to the labels the lab put on the printed articles), labeled
plate maps, the print key CSV for all 36
articles, byte copies of the STLs named by article, and a rebound-energy
vs t180 figure of the three picks alone. Built by
`t3_prism_replicate_plates.py` straight from the committed round-4 and
round-3 projects (no re-render, no mass re-solve; the script checks the
project meshes against the committed STLs and manifests first), at the
round-4 filament point (PLA 226 C / 29.5 mm3/s, TPU 236 C / 2.6 mm3/s).
Headless slice check with BambuStudio v02.07.01.62: all three plates exit
0 with all nine named objects sliced and only the usual pre-support
cantilever warning, about 14 h 55 min and 175 g PLA + 60 g TPU per plate
including tower, flushing and brims; a control slice with the per-part
infill overrides deleted used 6.7 g less PLA, so the overrides are live.
The dran3 project, like the round-3 original, stops at the CLI's nozzle
check (it predates `_patch_h2d_state`) and is left unpatched on purpose.
Record: `replicate-study/t3-prism-replicate-slice-check.json`.

## Model interpretability (diagnostics)

- `t3_prism_bo_diagnostics.py`: refits the round-1 SAASBO model from the
  committed AxClient snapshot and writes three interpretability figures plus
  the tables behind them. Nothing here comes from the Honegumi template
  (its `visualize=True` block is the Pareto scatter and nothing else); the
  first two are Ax 0.5.0's own diagnostic API and the third is built on top
  of the model's posterior. Run from the repo root:
  `python bo/t3_prism_bo_diagnostics.py` (about 6 min: one full NUTS fit for
  the importances and effects, a second reduced fit plus 7 refits for the
  leave-one-out folds). `--skip-cv` drops the expensive part, and
  `--plot-only` redraws all three figures from the recorded CSVs in about a
  second with only pandas and matplotlib.
- `figures/t3-prism-bo-round1-feature-importance.png` (+
  `t3-prism-bo-round1-feature-importance.csv`): SAAS inverse lengthscales
  per metric, via `TorchModelBridge.feature_importances`, which takes the
  median lengthscale over the MCMC draws, inverts it, and normalizes the
  six parameters to sum to 1. Ax's `MBM_X_trans` maps the search space onto
  the unit cube before fitting, so those numbers are comparable across
  parameters and read as "share of the model's sensitivity". The whiskers
  are the interquartile range across the individual MCMC draws, which the
  single-number Ax API discards; they are what tells you how firmly the
  ranking is held.
- `figures/t3-prism-bo-round1-loocv.png` (+ `t3-prism-bo-round1-loocv.csv`,
  `t3-prism-bo-round1-loocv-diagnostics.json`): leave-one-out via
  `ax.modelbridge.cross_validation.cross_validate(model, folds=-1)`, scored
  by `compute_diagnostics`. One gotcha worth knowing: `BoTorchModel` takes
  `refit_on_cv=False` by default in Ax 0.5.0, so an out-of-the-box
  cross-validation reconditions on the held-out training set while keeping
  hyperparameters fitted on all of the data, which leaks the held-out point
  and flatters the result. The diagnostics fit passes `refit_on_cv=True` and
  pays for the NUTS rerun per fold; that is the whole of the runtime.
- `figures/t3-prism-bo-round1-parameter-effects.png` and
  `figures/t3-prism-bo-round1-parameter-net-effects.png` (+
  `t3-prism-bo-round1-partial-dependence.csv`,
  `t3-prism-bo-round1-parameter-net-effects.csv`): the signed
  "does raising this parameter raise or lower this metric" view. Ax 0.5.0
  has no plot for this on a continuous space (`ax.plot.marginal_effects` is
  for factorial designs, and `plot_slice` fixes the other five parameters at
  one arbitrary point), so the script computes model-based partial
  dependence: sweep one parameter across its range while averaging the
  posterior mean over quasi-random draws of the other five. The first figure
  is the swept curves with a +/- 1 posterior sd band, the second is the net
  change from the low bound to the high bound as a signed tornado. Read them
  together: the tornado compresses each curve to one number, so a parameter
  that turns mid-range is marked with an asterisk and only the curve shows
  what it does. Partial dependence assumes the swept parameter is roughly
  independent of the others (true here, the search space is a plain box) and
  it does not show interactions.

`mass_printed_g` appears on the parameter axis of all three figures rather
than as a metric: under a constant-printed-mass projection the mass is chosen,
not observed, so predicting it would be predicting an input. It is worth
looking at, since it carries 20 percent of the model's t180 sensitivity and
16 percent of its rebound sensitivity, more than either strut or cable
diameter.

Two cautions that apply to all three, since n = 7 tested articles in a 6-D
space is a small sample: the importances sit close to the 1/6 equal-share
line with overlapping MCMC bands, and most of the partial-dependence curves
move by less than their own posterior sd. Read the direction and the
ranking, not the decimals. The mass curves need one more caution of their
own: printed mass and geometry are confounded by construction in round 1
(the light articles *are* the PLA-heavy thick-strut corner), so the sign of
the mass effect is the least trustworthy number on either figure.

### Round-4 LOOCV (all 26 articles, the 12-parameter model)

```bash
python bo/t3_prism_bo_diagnostics.py --snapshot bo/t3-prism-bo-ax-client-round4.json \
    --round 4 --cv-only          # ~25 min: 26 held-out NUTS refits
python bo/t3_prism_bo_diagnostics.py --round 4 --cv-only --plot-only  # redraw
```

Files: `figures/t3-prism-bo-round4-loocv.png` (two parity panels, one per
objective, +/-1 sd bars), `t3-prism-bo-round4-loocv.csv`,
`t3-prism-bo-round4-loocv-diagnostics.json`. `--cv-only` exists because
the importance/PDP renderers still assume the six-parameter shape+mass
space; the LOOCV machinery itself is generic, and the script now widens
a 12-parameter snapshot to the matching fit space and labels round-3
arms.

Held-out skill across the campaign's three states (each state is the
model the campaign actually used then, so the first two are 6-parameter
fits and this one is 12-parameter; a controlled same-space comparison
would re-run the earlier pools in the 12-parameter space):

| state | n | t180 MAPE / rank corr | rebound MAPE / rank corr |
|---|--:|---|---|
| initialization only | 8 | 2.9 % / +0.76 | 29.3 % / +0.24 |
| + round 2 | 17 | 5.4 % / +0.60 | 23.6 % / +0.70 |
| + round 3, process axes in | 26 | 6.2 % / +0.19 | 32.2 % / +0.30 |

The drop is real and worth stating plainly: with six process axes added
(four of them carrying only two batch-confounded values) and round 3
contributing the campaign's extremes (`drran7` at t180 1.251, `drran1`
at 18.1 mJ), the held-out posterior shrinks toward the pooled mean and
misses exactly the articles that define the front and its failures.
Fisher's exact test keeps rebound marginal (p = 0.058) and t180 at
chance (p = 0.5). Consistent with that humility, the round-4 batch is
best read as exploration with a defensible best guess (trial 37), not
as a model that can call its shots; the round-3 within-batch
calibration told the same story from the other side (8 of 9 t180
misses within 0.3 sd because the bands were wide, not because the
means were sharp).

The same diagnostics re-run on the 17-article two-round fit (the
`t3-prism-bo-ax-client-round2.json` snapshot; `amdjwm` is still unmapped and
stays out):

    python bo/t3_prism_bo_diagnostics.py \
        --snapshot bo/t3-prism-bo-ax-client-round2.json --round 2 --cv-animation

writes the `*-round2-*` versions of every figure and table above, plus a
LOOCV figure set and animation in the same registered-still grammar as the
measured round-2 predicted-vs-actual set (`--cv-animation`; add
`--no-animation` for the stills alone, or re-render from the committed CSV
with `--plot-only --cv-animation --round 2`):

- `figures/t3-prism-bo-round2-loocv-start.png`,
  `-uncertainty.png`, `-predicted-vs-actual.png`, `-front-final.png`: four
  3300 x 2100 stills at 300 dpi, frames of one figure, so they register
  pixel-for-pixel on consecutive slides. Each article's held-out prediction
  (a model refit without that article) opens as an orange diamond, grows its
  +/- 1 sd bars and axis-aligned oval, freezes, then travels to the measured
  outcome and lands as the standard open black circle; the measured Pareto
  front then wipes in and the print IDs return. There is no prior-round
  layer (the predictions are the tested articles themselves), so the
  round-2 set's retire beat drops out.
- `figures/t3-prism-bo-round2-loocv-predicted-vs-actual.mp4` (+ `.gif`): the
  animated version, same beats. The uncertainty here is the same quantity as
  in the measured set (1 posterior sd of the noise-free objective), but from
  the held-out refit, so it is an honest out-of-sample bar rather than a
  training-point one.

Headline movement against the round-1 diagnostics: with 17 articles the
LOOCV rank correlation on rebound energy went from -0.14 (no skill) to 0.70,
and t180 sits at 0.60 with MAPE 5.4 percent, so the model now has genuine
out-of-sample ordering skill on both objectives. The round-2 batch that
landed systematically right of its t180 predictions is in the fit now, and
it shows: r2d2c3, which the pre-round-2 model missed by 5.8 sd, is a 2.7-sd
held-out miss for a refit that has seen the other round-2 articles, still
the worst t180 residual but no longer in a class of its own (the two
largest, r2d2c3 high and r2d2c6 low, are the two stiffest short-prism
designs, so that corner of the space is where the surrogate remains
weakest).

### Round-5 LOGO-CV (leave-one-design-out, all 44 articles)

`python bo/t3_prism_bo_diagnostics.py --snapshot
bo/t3-prism-bo-ax-client-round5.json --round 5 --cv-only --group-cv`
writes `t3-prism-bo-round5-logocv.{csv,png}` +
`-logocv-diagnostics.json`. With the 2dran repeats in the fit, plain
LOO would leak: hold out 2dran3 and its twin drran3 stays in training
at nearly the same coordinates, so the fold tests interpolation, not
prediction. `--group-cv` holds a reprint pair out together (35 design
folds over 44 articles; every unrepeated article is its own fold),
NUTS refit per fold like the LOO path. This run used 64 NUTS samples /
128 warmup to fit the session; re-run without the two `--cv-*` flags
for the 128/256 settings the earlier LOOCVs used (about twice as
long); the numbers below are direction-stable against that choice.

| metric | MAPE | r | rank corr | round-4 LOOCV (26 articles, naive LOO) |
|---|---|---|---|---|
| t180 | 5.0 % | +0.22 | +0.08 | 6.2 % / +0.19 |
| e_reb_mJ | 39.4 % | -0.38 | -0.38 | 32.2 % / +0.30 |

The read: held-out design-level skill on t180 is essentially gone
(the surrogate predicts near the pooled mean; only the corny7/corny6
corner and the r2d2c3/drran7 amplifiers stretch the axis), and the
rebound ordering is now anti-correlated: what looked like weak
positive rebound skill in the round-4 LOOCV was partly the model
predicting print luck, which the repeats expose (the repeatability
section's pair ratios of 0.38x-2.9x are the same fact seen from the
data side). Comparison caveats: the two rows differ in n (44 vs 26
articles), in folds (design vs article) and in the repeat data itself,
so this is the campaign's honest current state, not a controlled
ablation of the grouping alone.

### Parity evolution (predictions before vs after the round-2 data)

The corrected form of the cross-validation figure request on PR #102: two
parity panels, one per objective, predicted on the vertical axis against
measured on the horizontal, showing where every tested article's prediction
stood before the round-2 sessions and where the refit trained on all
collected data puts it. Measured values never move, so all motion in the
animation is the model changing its mind.

    python bo/t3_prism_bo_diagnostics.py --parity-evolution              # ~4 min, 2 refits
    python bo/t3_prism_bo_diagnostics.py --parity-evolution --plot-only  # redraw from the CSV

Provenance of the two prediction sets, per article:

- **Before** is the model state that actually chose the printed plate:
  commit `7a048ee`'s AxClient (5 shape parameters, 7 articles in the fit),
  restored from git history as `t3-prism-bo-ax-client-plate-7a048ee.json`
  (`git show 7a048ee:bo/t3-prism-bo-ax-client-round1.json`). For the nine
  r2d2c articles the before values are `t3-prism-bo-round1-predictions.csv`
  verbatim, the frozen numbers the plate was generated from and the numbers
  every table on the PR #102 thread quotes. For the round-1 articles they
  come from a seeded refit of that snapshot, in sample for the seven
  articles that model had seen and out of sample for `ajhby6` (spec 07 was
  still a pending trial then). A fidelity check predicts the nine plate
  designs with the refit and compares against the frozen CSV; the run that
  produced the committed table agreed to within 0.024 on t180 and 1.4 mJ on
  rebound energy, 0.3 of the frozen sd on both, so the reconstructed and
  frozen numbers describe the same model.
- **After** is the round-2 snapshot's refit (6 parameters, 17 articles)
  predicting in sample at each article's own coordinates and weighed mass.
  In-sample parity is the point of this figure (the request was the refit
  trained on all collected data); the honest out-of-sample companion is the
  LOOCV set above, which shares the grammar.

Uncertainties, stated on the figure: vertical bars are 1 posterior sd of
the noise-free objective from whichever model owns the frame (before or
after), horizontal gray bars are the measured value's 1 SEM as ingested
(for rebound energy that includes the 0.457 g print-to-print mass scatter
in quadrature, which is why those are visible while the t180 SEMs are not).

Files, same registered-still grammar as every other figure set here (all
3300 x 2100 at 300 dpi, frames of one figure, no tight bounding box):

- `figures/t3-prism-bo-round2-parity-start.png`: the before state. Round-1
  articles are open black circles hugging the diagonal (in sample); the
  nine forecasts are orange diamonds, all below the diagonal on t180
  (measured landed 0.04 to 0.42 above forecast, the systematic optimism)
  and all above it on rebound energy (measured landed 0.9 to 5.8 mJ below).
- `figures/t3-prism-bo-round2-parity-shift.png`: every prediction has
  traveled vertically to the refit's value, ghost diamonds and dashed
  risers marking where each forecast stood; one before/after pair is named.
- `figures/t3-prism-bo-round2-parity-final.png`: the ghosts cleaned up,
  print IDs in. The refit describes all 17 articles to within 0.0002 on
  t180 and 0.03 mJ on rebound (in sample, as expected for a GP with
  per-drop SEMs this small; r2d2c3's forecast 0.910 +/- 0.073 now sits at
  1.333 against its measured 1.334).
- `figures/t3-prism-bo-round2-parity.mp4` (+ `.gif`): the animated version.
  Beats: hold on the before state, staggered vertical travel with the
  diamonds handing off to open circles, a named before/after hold, clean,
  rest with IDs.
- `t3-prism-bo-round2-parity-evolution.csv`: the full table (measured,
  before, after, 1 sd each, provenance flags per article and objective).

### LOOCV evolution (held-out skill, initialization data vs all data)

The corrected form of the parity-evolution request (sgbaird, PR #102): both
states are leave-one-out predictions, so the pair of plots is an
out-of-sample report card before and after the round-2 data rather than an
in-sample refit. The start state runs LOOCV over the initialization dataset
alone: the eight tested round-1 articles (seven mapped Sobol specs plus the
S0 reference `bpx68c`; `amdjwm` stays out, unmapped), each predicted by a
model refit without it on the other seven. The end state is LOOCV over all
collected data: 17 articles, each predicted by a model refit on the other
16. The model class, 6-parameter space, per-fold NUTS refit
(`refit_on_cv=True`) and MCMC settings are identical in the two states, so
a change in held-out skill is attributable to the added data.

    python bo/t3_prism_bo_diagnostics.py --loocv-evolution              # 8 init folds, ~5 min
    python bo/t3_prism_bo_diagnostics.py --loocv-evolution --plot-only  # redraw from the CSV

Two provenance rules keep the comparison clean:

- The end state is reused verbatim from the committed 17-fold LOOCV
  (`t3-prism-bo-round2-loocv.csv`, commit `83e137a`), so this figure and
  the LOOCV animation set quote identical numbers. Re-run
  `t3_prism_bo_diagnostics.py --round 2` first if the ingested data ever
  changes; the compute step raises if the two states' observed values
  disagree.
- The start state is not the old committed round-1 LOOCV
  (`t3-prism-bo-round1-loocv.csv`): that run predates `ajhby6` and used
  the 5-D space with mass as a tracking metric. Holding the model class
  fixed matters more here than matching the historical artifact, so the
  start state refits the current 6-D formulation on the eight round-1
  articles.

What the committed run says, per objective (LOOCV rank correlation and
MAPE; the left side of each arrow is the initialization state, n = 8, the
right side is all data, n = 17):

- **Rebound energy: the model learned.** Rank corr +0.24 to +0.70, MAPE
  29.3% to 23.6%. The improvement is not just the wider round-2 spread
  being easier to rank: restricted to the same eight round-1 articles, the
  all-data folds cut the median held-out residual from 2.37 to 1.78 mJ and
  raise the within-round-1 rank corr from +0.24 to +0.55.
- **t180: the added batch did not transfer.** Rank corr +0.76 to +0.60
  over the growing pool, and on the same eight round-1 articles the
  held-out median residual worsens from 0.015 to 0.036 while their
  internal ranking collapses (+0.76 to -0.10; seven of the eight measured
  values sit within 0.07 of one another, so that ordering is fragile).
  This is the base-coordinate representation shift the Edison round-2
  review flagged: the r2d2c batch measured systematically stiffer at
  comparable coordinates, so folds that include it pull the round-1
  backfits upward. Rank correlations at n = 8 swing by several tenths
  between NUTS realizations, so read directions, not decimals.

Files (registered stills, 3300 x 2100 at 300 dpi, frames of one figure, no
tight bounding box):

- `figures/t3-prism-bo-loocv-evolution-start.png`: the initialization-only
  LOOCV parity, the eight articles as orange diamonds with +/- 1 sd bars.
- `figures/t3-prism-bo-loocv-evolution-shift.png`: the same eight articles
  re-predicted under the all-data folds, ghost diamonds and dashed risers
  marking the initialization values; the round-2 articles are not on the
  panel yet.
- `figures/t3-prism-bo-loocv-evolution-final.png`: the all-data LOOCV
  parity, all 17 articles as open circles, print IDs in.
- `figures/t3-prism-bo-loocv-evolution.mp4` (+ `.gif`): the animated
  version. Beats: hold on the initialization LOOCV, staggered vertical
  travel with diamond-to-circle handoff, the nine round-2 articles fading
  in as their own beat, hold, clean, rest with IDs.
- `t3-prism-bo-loocv-evolution.csv`: the merged table (measured +/- SEM,
  initialization prediction +/- 1 sd where that state exists, all-data
  prediction +/- 1 sd, per article and objective).
- `t3-prism-bo-loocv-evolution-init.csv` + `-diagnostics.json`: the raw
  initialization-only folds, and both states' Ax cross-validation
  diagnostics.

Per-gram companion (`--per-gram`, display only, use with `--plot-only`):
the same set with every rebound-energy quantity (measured value and SEM,
both states' held-out prediction means and sds) divided by the article's
weighed mass, written as `-per-gram` tagged files next to the absolute
ones. As with the campaign figures, the measured quotient is exactly
e_rebound * g * h, the intensive form from the PR #33 notes, so no article
scores well by printing light; predictions divide by the same weighed mass
they were conditioned on. MAPE is invariant under the per-article division
(each article's relative error is unchanged), but the ranking is not, so
the rebound skill numbers on the panels are recomputed from the
transformed values with the same definitions as the committed absolute
diagnostics (verified to reproduce them exactly before transforming):
rank corr +0.02 (initialization only) to +0.68 (all data), against +0.24
to +0.70 in absolute mJ. The learning verdict is the same in both forms;
the initialization state merely starts even closer to no skill once the
printed-mass dividend is stripped out. The committed CSVs stay in absolute
mJ; the transform lives in `loocv_evolution_per_gram` and runs at render
time.

    python bo/t3_prism_bo_diagnostics.py --loocv-evolution --plot-only --per-gram

## Drop-count sensitivity (shorter round-2 sessions)

Round 1 ran ~101 drops per specimen. When session time is short, fewer drops
per specimen is an option, and this analysis quantifies the cost by replaying
round 1 as if each session had stopped after the first N drops.

- `t3-prism-per-drop-metrics.csv`: per-drop t180 and e_rebound for all 893
  valid round-1 drops (9 specimens). The first 8 specimens are extracted from
  `campaign_metrics.json` on the PR #86 branch
  `copilot/add-drop-test-protocol-again` (commit-level provenance in that
  branch's `data/drop-tests/sobol-campaign/`); the `ajhby6` rows (99 drops,
  tested 2026-08-21, uploaded to Box 2026-08-24) were computed on 2026-08-24
  by running that branch's `drop_test_campaign_analysis.py` unchanged on the
  Box upload. The 2 warmup drops per specimen are discarded in both cases.
- `t3_prism_drop_count_sensitivity.py`: builds the table and figure below,
  and `--emit-truncated N` writes
  `t3-prism-bo-batch-drop-results-firstN.csv`, a campaign summary with
  round-1 statistics recomputed over the first N drops in the exact schema
  `t3_prism_bo_campaign.py --results` expects.
- `t3-prism-drop-count-sensitivity.csv` and
  `figures/t3-prism-drop-count-sensitivity.png`: the replay results.

Where the "2 warmup drops" come from, since the phrase has caused confusion:
it is an analysis-time convention, not a step performed at the drop tower.
`scripts/analysis/drop_test_campaign_analysis.py` on the PR #86 branch sets
`WARMUP_DROPS = 2` and computes every stabilized statistic over
`valid[2:]`, so the first two trigger-valid captures of each session are
recorded but excluded from the means (which is why `n_valid` reads 101
while this per-drop file holds 99 rows per specimen). The number 2 comes
from the burn-in section of `docs/drop-test-sample-size-analysis.md` on
that branch: hot-glue mounts drift for 5 to 10 drops, the wax key-seat
mount settles within about 2. The lab-floor practice (one test drop at the
start of a specimen, kept unless anomalous, per Marcus Madsen on PR #102,
2026-08-24) is a separate check and is unaffected: if that test drop is
captured and healthy it simply becomes the first of the two
analysis-discarded drops. For a short round-2 session, record 2 extra
drops (22 for a 20-drop target) so the stabilized window matches round 1,
or pass a matching `--warmup` to the analysis.

What the replay shows. The t180 ranking of all 8 tested specimens is
identical at N = 20, N = 50 and the full session; the worst first-20 t180
deviation is +0.008 (bag26v, which softens over its session) against
design-to-design gaps of 0.007 to 0.087, and the per-drop SEM at N = 20 is
still an order of magnitude below those gaps. The e_rebound fraction is the
fragile one: 7 of 8 specimens sit within 2.5 percent of their full-session
value at N = 20, but amdjwm lands 21 percent low because a burst of harder
rebounds arrives around drops 26 to 40, and the mid-pack e_rebound ordering
(four specimens within 0.003 of each other) shuffles under truncation.

How a short round 2 is accounted for in the pipeline. The BO ingestion
already computes noise as sd/sqrt(n_valid) from the results CSV, so a
20-drop session simply enters the model with about 2.2x the standard error
and the GP downweights it accordingly; nothing needs changing there. The one
thing that should change: because most specimens drift slightly over a
session, ingest round 1 through the matching `-firstN` truncated summary so
both rounds average the same early-session window and estimate the same
quantity:

```bash
python bo/t3_prism_drop_count_sensitivity.py --emit-truncated 20
python bo/t3_prism_bo_campaign.py --results bo/t3-prism-bo-batch-drop-results-first20.csv ...
```

### Window extrapolation (round 2 projected to a full session)

The replay above asks what round 1 would have looked like short; this
analysis asks the reverse as well: what the round-2 short sessions (19 to 20
scored drops) would likely read at round-1 length, and whether any headline
claim depends on the choice of window. `t3_prism_drop_window_extrapolation.py`
computes, from the committed per-drop files only:

- `t3-prism-drop-window-ratios.csv`: per round-1 specimen, the ratio of the
  full-session mean to the first-19 mean, per objective ingredient. Pooled:
  t180 ratio 0.9985 (sd 0.0033, range -0.7 to +0.4 percent), e_rebound
  ratio 1.041 (sd 0.086), where the rebound spread is dominated by amdjwm's
  late burst (+26.7 percent; without it, 1.013 with sd 0.015). The round-1
  t180 ranking at 19 drops is preserved (Spearman +0.98; the one swap is
  ajhby6 vs bpx68c, first-19 means 0.00003 apart).
- `t3-prism-drop-window-extrapolation.csv`: each round-2 article's measured
  window mean times the pooled ratio, with a 1 sd band (ratio spread
  combined with the article's own SEM) and a min/max envelope. This is an
  estimate that assumes round-2 articles drift like round-1 articles did;
  it is analysis, not measurement, so it is not an ingestion file.
- `t3-prism-drop-window-front-robustness.csv`: Pareto membership for the 17
  mapped articles under three conventions: mixed (as committed), matched
  first-19 in both rounds, and full-equivalent (round 2 extrapolated). The
  round-2 core of the front (6lhxfy, r2d2c7, r2d2c1, r2d2c2, r2d2c6) is
  identical under all three; the window choice only decides whether the
  low-rebound round-1 anchors also sit on it (ajhby6 joins under matched
  first-19; ajhby6 and bpx68c both join under full-equivalent).
- `t3-prism-bo-batch-drop-results-first19.csv`: the matched-window round-1
  summary in the ingestion schema (19 is the modal scored count of the
  round-2 sessions; the guidance above used 20 before the sessions ran).
  This, not the extrapolation, is the file to feed a refit.
- `figures/t3-prism-drop-window-extrapolation.png`: both halves on one
  canvas.

Two conclusions worth carrying. The round-2 calibration verdicts do not
depend on the window: extrapolated to a full session, all nine articles
stay above their frozen t180 predictions and below their frozen rebound
predictions (6 of 9 stay below even at the +27 percent worst-case burst
envelope). And one claim does need a qualifier: "r2d2c1 strictly dominates
bpx68c" holds as committed and under matched windows, but r2d2c1's
extrapolated full-session rebound (6.21 mJ, sd 0.51) edges 0.03 mJ above
bpx68c's measured 6.18, so state that dominance as a short-window result.

```bash
python bo/t3_prism_drop_window_extrapolation.py            # all outputs
python bo/t3_prism_drop_window_extrapolation.py --no-figure
```

## Round-2 drop data (the r2d2c prints, first sessions 2026-08-24)

Raw campaign data is uploaded manually to the shared Box folder
[`tensegrity-optimization`](https://byu.box.com/s/kkhmvnj9ni19b57dryk3gdroqrp5uf0b)
(public view/download link created by @sgbaird on PR #86, 2026-07-21),
subfolder `Drop Test Data`, one folder per session. Fetch a session with the
script copied from the PR #86 branch:

```bash
python scripts/fetch_box_shared_folder.py kkhmvnj9ni19b57dryk3gdroqrp5uf0b DEST
```

That downloads the entire share (videos included). To pull one session
folder, resolve its folder id from the share listing first; the ids used on
2026-08-24 were 411619211572 (`r2d2c1`), 411623696481 (`r2d2c2`),
411630638267 (`r2d2c3`), 411633263159 (`r2d2c4`), 411638730821 (`r2d2c5`),
411638799623 (`r2d2c6`), 411634427962 (`r2d2c7`), 411654362191 (`r2d2c8`),
411659610187 (`r2d2c9`), and 410920465434 (`ajhby6`).

Upload quirk worth knowing before re-analyzing: the `r2d2c8` session was
exported under a name ending in `_Signal9`, so on Box its TP4 series table
is `..._Signal9.csv` (which parses as a capture and crashes the pipeline)
and its 22 real captures are `..._Signal9_SignalN.csv` (which the pipeline
skips). Rename the table to something without `Signal` and strip the first
`_Signal9` from the capture names before running the analysis.

The BO round-1 plate (the second tested batch, designs `t3-prism-bo-round1.csv`
on the PR #35 branch) was removed and labeled `r2d2c1` through `r2d2c9` on
2026-08-24; masses with label were posted in issue #98 the same day. Files:

- `t3-prism-bo-round1-print-key.csv`: print ID to specimen/trial mapping for
  all nine articles, plus RH% and defect notes from the issue #98 print log
  as they are posted. The mapping is CONFIRMED as of 2026-08-24: @sgbaird
  posted photos of the removed prints on a numbered tabletop grid
  (positions 1 to 9 = `r2d2c1` to `r2d2c9`, laid out in the plate
  arrangement) together with a Bambu Studio screenshot anchoring the
  back-left plate object as Specimen 03, which pins the raster direction.
  That is the same back-left to front-right mapping the mass fit had
  inferred (residual sd about 0.5 g, uniform +0.3 g label offset, center
  cell `r2d2c5` = Specimen 08 unambiguous), so the photographic and
  mass-model evidence agree independently.
- `t3-prism-bo-round1-drop-results.csv`: campaign summary for all nine
  sessions (r2d2c1 to r2d2c9, uploaded 2026-08-24; 21 valid captures each,
  22 for r2d2c8; 19 to 20 scored after the 2-drop warmup discard), produced
  by the PR #86 branch `drop_test_campaign_analysis.py` unchanged. Same
  schema as `t3-prism-bo-batch-drop-results.csv` plus the three T-drift
  watch columns that script now emits (`t_drift_flag`,
  `t180_slope_pct_per_drop`, `t180_e2e_pct`). The `mass_g` column is the
  posted mass with label. The geometry columns (`R_mm`, `H_mm`,
  `twist_deg`, `strut_d_mm`, `cable_d_mm`) are **as-printed** dimensions,
  matching the `*_print_*` columns of `t3-prism-bo-round1-designs.csv` for
  the specimen's spec, not the Ax base coordinates. Reading them as base
  coordinates makes the spec mapping look wrong (one downstream analysis
  did exactly that); the print key is the authoritative specimen-to-spec
  map.
- `t3-prism-bo-round1-per-drop-metrics.csv`: the stabilized per-drop rows
  for those sessions (172 rows), same schema as
  `t3-prism-per-drop-metrics.csv`.
- `t3-prism-bo-round1-designs.csv`: the plate that was actually printed
  (`bo/t3-prism-bo-round1.csv` on the PR #35 branch, commit 8809b25).
  `R_mm`..`cable_d_mm` are the base coordinates of Ax trials 10 to 18; the
  `*_print_*` columns are the constant-solid-mass projection that went to
  the printer.
- `t3-prism-bo-round1-predictions.csv`: the suggestions CSV as it stood
  when that plate was generated (commit `7a048ee`), kept frozen so
  predicted-vs-measured is drawn against what the model actually claimed.

Session notes from the 2026-08-24 uploads: all captures in all nine
sessions are trigger-valid, no pauses, input Δv 5.29 to 5.41 m/s (healthy
band). One session, `r2d2c2`, breaks the historical within-session T-drift
envelope (+0.25 %/drop, +3.5 % end to end, output-side signature: mount or
coupling suspect); its t180 mean is drift-contaminated and its inflated sd
is what the BO ingestion sees. The `r2d2c1` folder name originally said
"23 drops" against 21 events in the TP4 series table and export; the folder
has since been renamed to "21 drops" on Box, so the name and contents now
agree. The session ID string inside every export still reads "101 drops"
(template reuse), which is cosmetic.

Print-log entries for all nine r2d2c articles were posted to issue #98 on
2026-08-24 (ronnie-guymon) and are folded into
`t3-prism-bo-round1-print-key.csv`: every article printed at ~11 % RH;
defects were limited to detached or "spaghetti" TPU tendon strings on
`r2d2c1` (two top tendons, plus an odd foot support), `r2d2c4` (one top
tendon, one piece about 1/4 detached), and `r2d2c8` (two bottom tendons,
full span); the other six printed clean.

### Round-2 outcomes and the round-3 batch

With all nine round-2 sessions in, the ingestion in
`t3_prism_bo_campaign.py` attaches both batches (18 tested articles: 9
round-1 including `bpx68c`, minus the unmapped `amdjwm`, plus 9 r2d2c) and
the two still-untested round-1 prints (specs 03 and 06) as pending. Run:

```bash
python bo/t3_prism_bo_campaign.py --round 2       # refit + round-3 batch
python bo/t3_prism_bo_campaign.py --measured-round2  # predicted-vs-measured
                                                     # figure set + animation
```

The first command writes `t3-prism-bo-suggestions-round2.csv` (the round-3
candidate batch at constant printed mass), the AxClient snapshot
`t3-prism-bo-ax-client-round2.json`, and
`figures/t3-prism-bo-round2-pareto.png`. The second renders the measured
predicted-vs-actual figure set (`figures/t3-prism-bo-round2-start.png`,
`-uncertainty.png`, `-predicted-vs-actual.png`, `-front-final.png`, plus
the MP4/GIF), the real-data version of the `-PROTOTYPE` set, which is kept
for provenance.
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

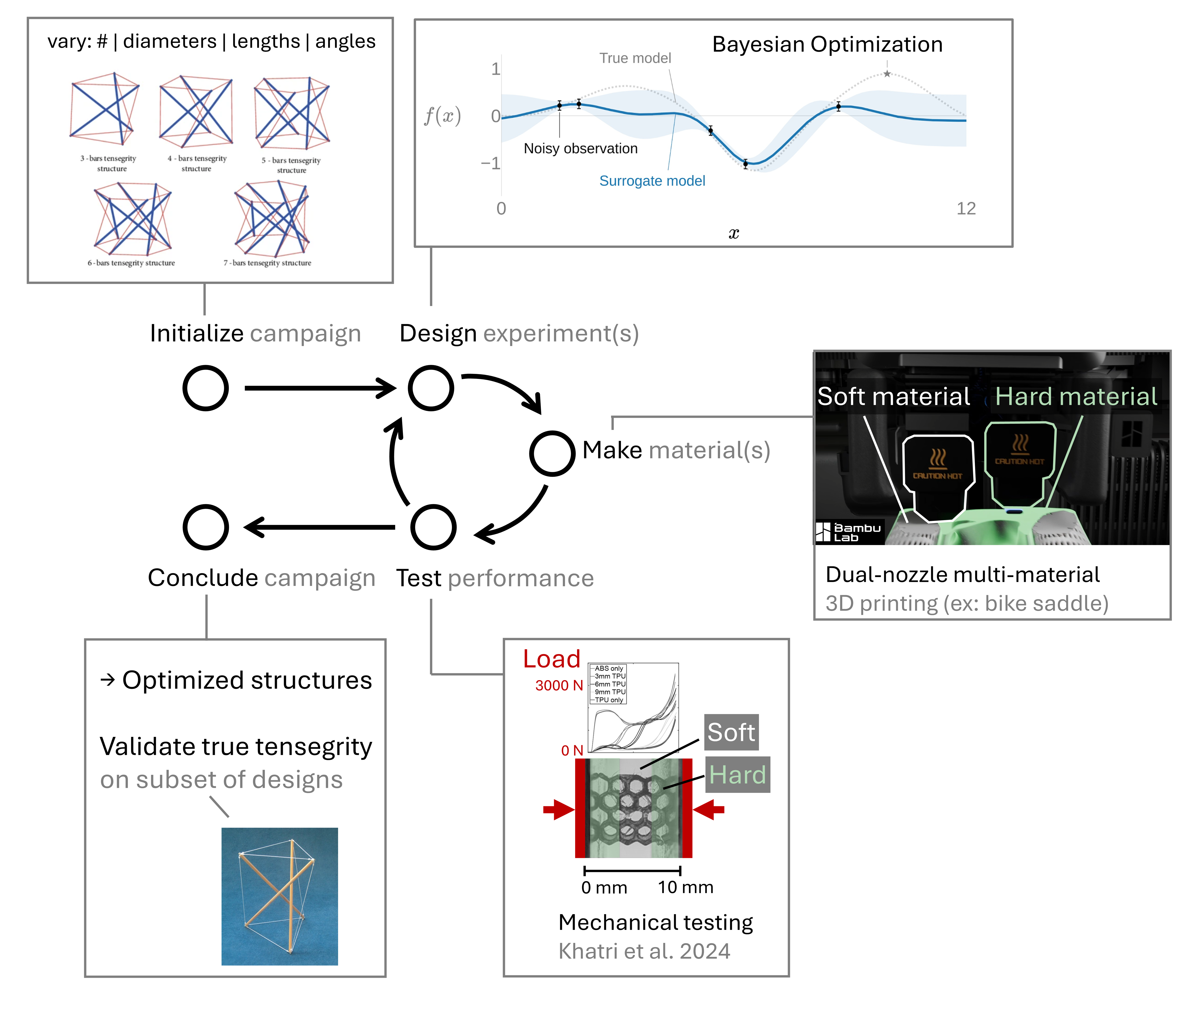
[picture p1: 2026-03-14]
figures/overview-updated.png

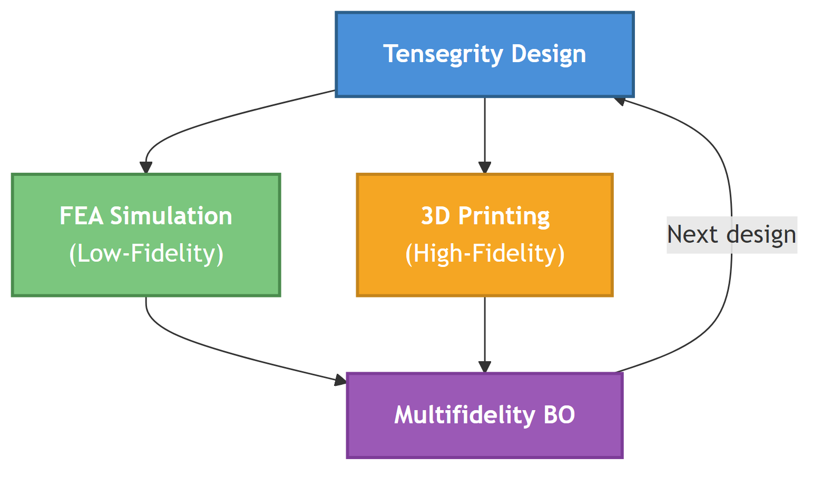
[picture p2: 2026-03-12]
figures/overview.png

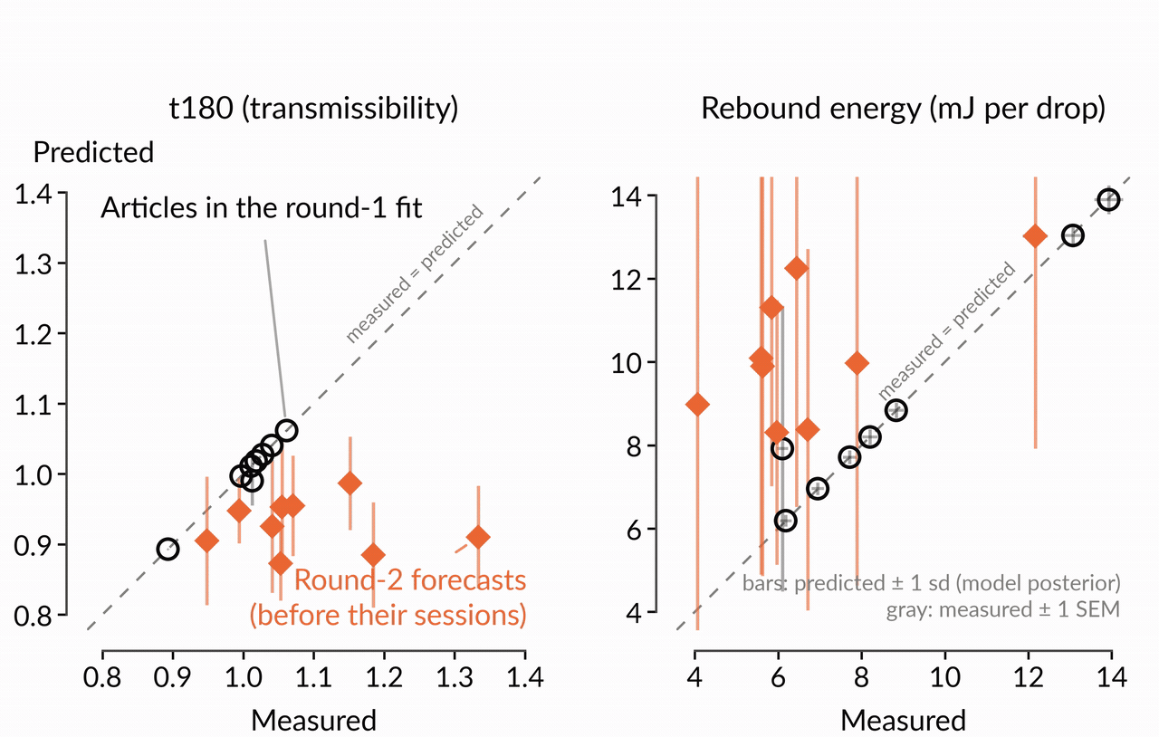
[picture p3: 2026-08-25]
bo/figures/t3-prism-bo-round2-parity.gif

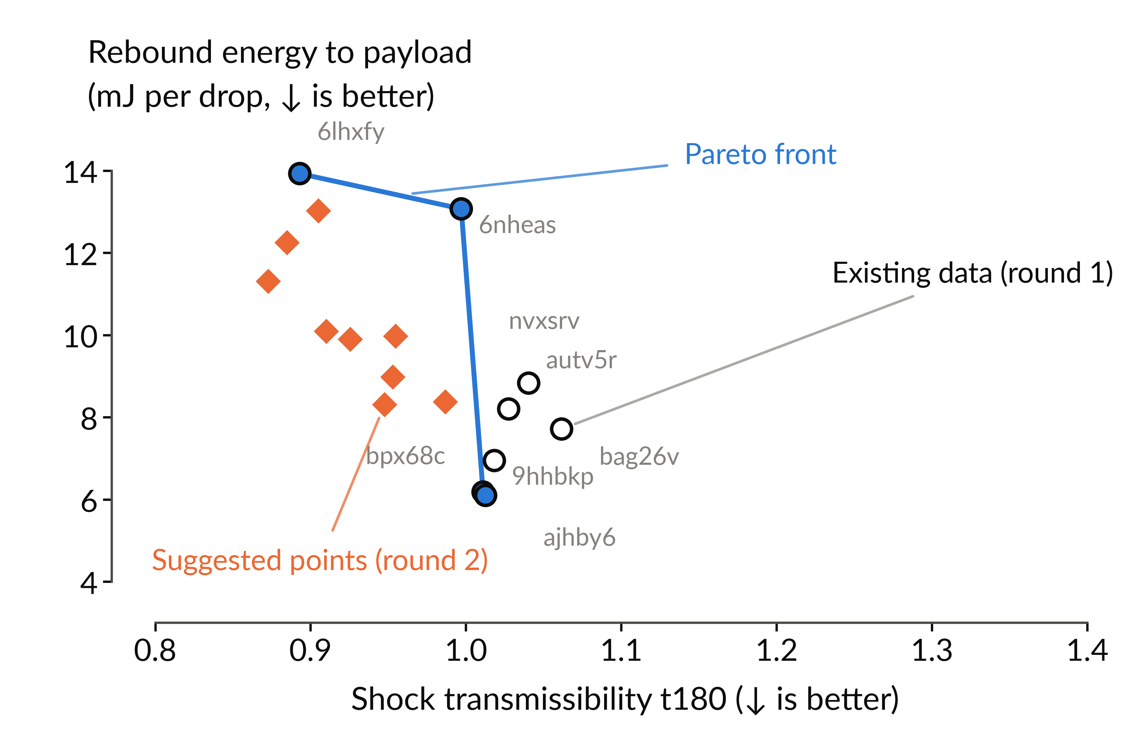
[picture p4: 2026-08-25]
bo/figures/t3-prism-bo-round2-start.png

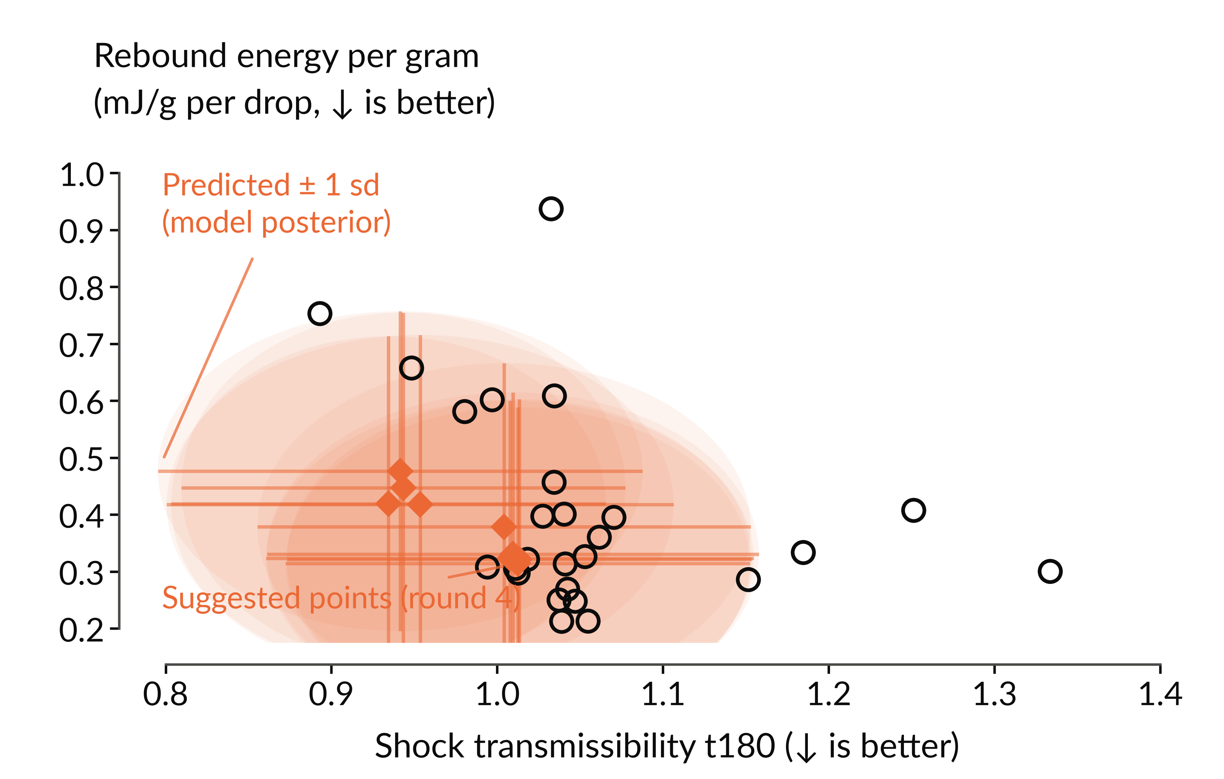
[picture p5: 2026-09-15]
bo/figures/t3-prism-bo-round4-uncertainty-per-gram.png

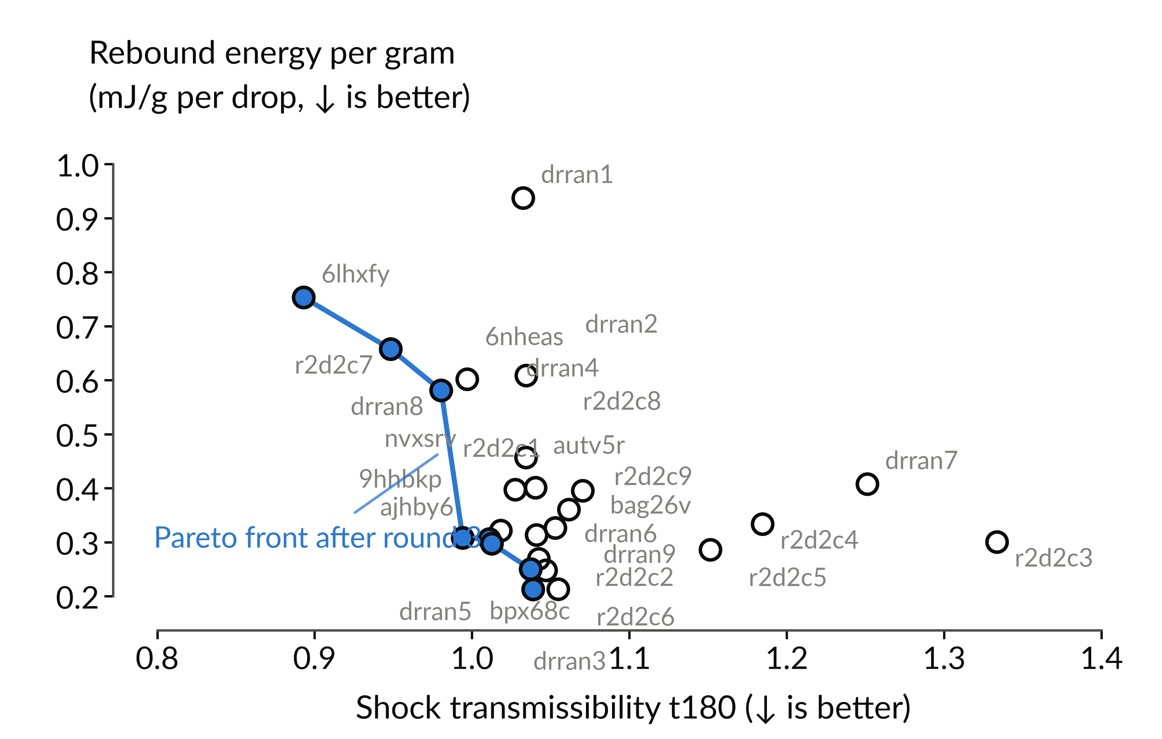
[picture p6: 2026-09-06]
bo/figures/t3-prism-bo-round3-front-final-per-gram.png

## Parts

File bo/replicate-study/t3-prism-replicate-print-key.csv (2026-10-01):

article_id | plate | design | trial | spec_digit | copy | plate_row | plate_slot | plate_x_mm | plate_y_mm | strut_infill_pct | tpu_infill_pct | pla_nozzle_temp_C | pla_flow_mm3_s | tpu_nozzle_temp_C | tpu_flow_mm3_s | printed_g_est | earlier_prints | earlier_masses_g | slicer_project | struts_stl | cables_stl
1sne71 | sne1 | corny7 | 37 | 7 | 1 | back | left | 66.9 | 254.5 | 22 | 21 | 226 | 29.5 | 236 | 2.6 | 19.92 | corny7 | 19.62 | t3-prism-replicate-sne-plate1.H2D-MM-PLAstruts-TPUcables.3mf | stls/corny7-t37-struts.stl | stls/corny7-t37-cables.stl
1sne81 | sne1 | corny8 | 39 | 8 | 1 | back | center | 162.3 | 254.5 | 21 | 34 | 226 | 29.5 | 236 | 2.6 | 19.95 | corny8 | 19.64 | t3-prism-replicate-sne-plate1.H2D-MM-PLAstruts-TPUcables.3mf | stls/corny8-t39-struts.stl | stls/corny8-t39-cables.stl
1sne21 | sne1 | corny2 | 38 | 2 | 1 | back | right | 244.1 | 254.5 | 18 | 34 | 226 | 29.5 | 236 | 2.6 | 20.52 | corny2 | 20.21 | t3-prism-replicate-sne-plate1.H2D-MM-PLAstruts-TPUcables.3mf | stls/corny2-t38-struts.stl | stls/corny2-t38-cables.stl
1sne82 | sne1 | corny8 | 39 | 8 | 2 | middle | left | 67.2 | 160.0 | 21 | 34 | 226 | 29.5 | 236 | 2.6 | 19.95 | corny8 | 19.64 | t3-prism-replicate-sne-plate1.H2D-MM-PLAstruts-TPUcables.3mf | stls/corny8-t39-struts.stl | stls/corny8-t39-cables.stl
1sne22 | sne1 | corny2 | 38 | 2 | 2 | middle | center | 149.0 | 160.0 | 18 | 34 | 226 | 29.5 | 236 | 2.6 | 20.52 | corny2 | 20.21 | t3-prism-replicate-sne-plate1.H2D-MM-PLAstruts-TPUcables.3mf | stls/corny2-t38-struts.stl | stls/corny2-t38-cables.stl
1sne72 | sne1 | corny7 | 37 | 7 | 2 | middle | right | 230.4 | 160.0 | 22 | 21 | 226 | 29.5 | 236 | 2.6 | 19.92 | corny7 | 19.62 | t3-prism-replicate-sne-plate1.H2D-MM-PLAstruts-TPUcables.3mf | stls/corny7-t37-struts.stl | stls/corny7-t37-cables.stl
1sne23 | sne1 | corny2 | 38 | 2 | 3 | front | left | 53.2 | 65.5 | 18 | 34 | 226 | 29.5 | 236 | 2.6 | 20.52 | corny2 | 20.21 | t3-prism-replicate-sne-plate1.H2D-MM-PLAstruts-TPUcables.3mf | stls/corny2-t38-struts.stl | stls/corny2-t38-cables.stl
1sne73 | sne1 | corny7 | 37 | 7 | 3 | front | center | 134.6 | 65.5 | 22 | 21 | 226 | 29.5 | 236 | 2.6 | 19.92 | corny7 | 19.62 | t3-prism-replicate-sne-plate1.H2D-MM-PLAstruts-TPUcables.3mf | stls/corny7-t37-struts.stl | stls/corny7-t37-cables.stl
1sne83 | sne1 | corny8 | 39 | 8 | 3 | front | right | 230.1 | 65.5 | 21 | 34 | 226 | 29.5 | 236 | 2.6 | 19.95 | corny8 | 19.64 | t3-prism-replicate-sne-plate1.H2D-MM-PLAstruts-TPUcables.3mf | stls/corny8-t39-struts.stl | stls/corny8-t39-cables.stl
2sne81 | sne2 | corny8 | 39 | 8 | 1 | back | left | 67.2 | 254.5 | 21 | 34 | 226 | 29.5 | 236 | 2.6 | 19.95 | corny8 | 19.64 | t3-prism-replicate-sne-plate2.H2D-MM-PLAstruts-TPUcables.3mf | stls/corny8-t39-struts.stl | stls/corny8-t39-cables.stl
2sne21 | sne2 | corny2 | 38 | 2 | 1 | back | center | 149.0 | 254.5 | 18 | 34 | 226 | 29.5 | 236 | 2.6 | 20.52 | corny2 | 20.21 | t3-prism-replicate-sne-plate2.H2D-MM-PLAstruts-TPUcables.3mf | stls/corny2-t38-struts.stl | stls/corny2-t38-cables.stl
2sne71 | sne2 | corny7 | 37 | 7 | 1 | back | right | 230.4 | 254.5 | 22 | 21 | 226 | 29.5 | 236 | 2.6 | 19.92 | corny7 | 19.62 | t3-prism-replicate-sne-plate2.H2D-MM-PLAstruts-TPUcables.3mf | stls/corny7-t37-struts.stl | stls/corny7-t37-cables.stl
2sne22 | sne2 | corny2 | 38 | 2 | 2 | middle | left | 53.2 | 160.0 | 18 | 34 | 226 | 29.5 | 236 | 2.6 | 20.52 | corny2 | 20.21 | t3-prism-replicate-sne-plate2.H2D-MM-PLAstruts-TPUcables.3mf | stls/corny2-t38-struts.stl | stls/corny2-t38-cables.stl
2sne72 | sne2 | corny7 | 37 | 7 | 2 | middle | center | 134.6 | 160.0 | 22 | 21 | 226 | 29.5 | 236 | 2.6 | 19.92 | corny7 | 19.62 | t3-prism-replicate-sne-plate2.H2D-MM-PLAstruts-TPUcables.3mf | stls/corny7-t37-struts.stl | stls/corny7-t37-cables.stl
2sne82 | sne2 | corny8 | 39 | 8 | 2 | middle | right | 230.1 | 160.0 | 21 | 34 | 226 | 29.5 | 236 | 2.6 | 19.95 | corny8 | 19.64 | t3-prism-replicate-sne-plate2.H2D-MM-PLAstruts-TPUcables.3mf | stls/corny8-t39-struts.stl | stls/corny8-t39-cables.stl
2sne73 | sne2 | corny7 | 37 | 7 | 3 | front | left | 66.9 | 65.5 | 22 | 21 | 226 | 29.5 | 236 | 2.6 | 19.92 | corny7 | 19.62 | t3-prism-replicate-sne-plate2.H2D-MM-PLAstruts-TPUcables.3mf | stls/corny7-t37-struts.stl | stls/corny7-t37-cables.stl
2sne83 | sne2 | corny8 | 39 | 8 | 3 | front | center | 162.3 | 65.5 | 21 | 34 | 226 | 29.5 | 236 | 2.6 | 19.95 | corny8 | 19.64 | t3-prism-replicate-sne-plate2.H2D-MM-PLAstruts-TPUcables.3mf | stls/corny8-t39-struts.stl | stls/corny8-t39-cables.stl
2sne23 | sne2 | corny2 | 38 | 2 | 3 | front | right | 244.1 | 65.5 | 18 | 34 | 226 | 29.5 | 236 | 2.6 | 20.52 | corny2 | 20.21 | t3-prism-replicate-sne-plate2.H2D-MM-PLAstruts-TPUcables.3mf | stls/corny2-t38-struts.stl | stls/corny2-t38-cables.stl
3sne21 | sne3 | corny2 | 38 | 2 | 1 | back | left | 53.2 | 254.5 | 18 | 34 | 226 | 29.5 | 236 | 2.6 | 20.52 | corny2 | 20.21 | t3-prism-replicate-sne-plate3.H2D-MM-PLAstruts-TPUcables.3mf | stls/corny2-t38-struts.stl | stls/corny2-t38-cables.stl
3sne71 | sne3 | corny7 | 37 | 7 | 1 | back | center | 134.6 | 254.5 | 22 | 21 | 226 | 29.5 | 236 | 2.6 | 19.92 | corny7 | 19.62 | t3-prism-replicate-sne-plate3.H2D-MM-PLAstruts-TPUcables.3mf | stls/corny7-t37-struts.stl | stls/corny7-t37-cables.stl
3sne81 | sne3 | corny8 | 39 | 8 | 1 | back | right | 230.1 | 254.5 | 21 | 34 | 226 | 29.5 | 236 | 2.6 | 19.95 | corny8 | 19.64 | t3-prism-replicate-sne-plate3.H2D-MM-PLAstruts-TPUcables.3mf | stls/corny8-t39-struts.stl | stls/corny8-t39-cables.stl
3sne72 | sne3 | corny7 | 37 | 7 | 2 | middle | left | 66.9 | 160.0 | 22 | 21 | 226 | 29.5 | 236 | 2.6 | 19.92 | corny7 | 19.62 | t3-prism-replicate-sne-plate3.H2D-MM-PLAstruts-TPUcables.3mf | stls/corny7-t37-struts.stl | stls/corny7-t37-cables.stl
3sne82 | sne3 | corny8 | 39 | 8 | 2 | middle | center | 162.3 | 160.0 | 21 | 34 | 226 | 29.5 | 236 | 2.6 | 19.95 | corny8 | 19.64 | t3-prism-replicate-sne-plate3.H2D-MM-PLAstruts-TPUcables.3mf | stls/corny8-t39-struts.stl | stls/corny8-t39-cables.stl
3sne22 | sne3 | corny2 | 38 | 2 | 2 | middle | right | 244.1 | 160.0 | 18 | 34 | 226 | 29.5 | 236 | 2.6 | 20.52 | corny2 | 20.21 | t3-prism-replicate-sne-plate3.H2D-MM-PLAstruts-TPUcables.3mf | stls/corny2-t38-struts.stl | stls/corny2-t38-cables.stl
3sne83 | sne3 | corny8 | 39 | 8 | 3 | front | left | 67.2 | 65.5 | 21 | 34 | 226 | 29.5 | 236 | 2.6 | 19.95 | corny8 | 19.64 | t3-prism-replicate-sne-plate3.H2D-MM-PLAstruts-TPUcables.3mf | stls/corny8-t39-struts.stl | stls/corny8-t39-cables.stl
3sne23 | sne3 | corny2 | 38 | 2 | 3 | front | center | 149.0 | 65.5 | 18 | 34 | 226 | 29.5 | 236 | 2.6 | 20.52 | corny2 | 20.21 | t3-prism-replicate-sne-plate3.H2D-MM-PLAstruts-TPUcables.3mf | stls/corny2-t38-struts.stl | stls/corny2-t38-cables.stl
3sne73 | sne3 | corny7 | 37 | 7 | 3 | front | right | 230.4 | 65.5 | 22 | 21 | 226 | 29.5 | 236 | 2.6 | 19.92 | corny7 | 19.62 | t3-prism-replicate-sne-plate3.H2D-MM-PLAstruts-TPUcables.3mf | stls/corny7-t37-struts.stl | stls/corny7-t37-cables.stl
dran31 | dran3 | round-3 trial 36 | 36 |  |  | back | left | 91.2 | 251.5 | 34 | 26 | 217 | 20.5 | 244 | 3.6 | 20.14 | drran1; 2dran1 | 19.31; 19.48 | t3-prism-dran3.H2D-MM-PLAstruts-TPUcables.3mf | stls/dran3/dran31-t36-struts.stl | stls/dran3/dran31-t36-cables.stl
dran32 | dran3 | round-3 trial 33 | 33 |  |  | back | center | 180.7 | 251.6 | 29 | 16 | 217 | 20.5 | 244 | 3.6 | 19.93 | drran2; 2dran2 | 19.33; 19.65 | t3-prism-dran3.H2D-MM-PLAstruts-TPUcables.3mf | stls/dran3/dran32-t33-struts.stl | stls/dran3/dran32-t33-cables.stl
dran33 | dran3 | round-3 trial 31 | 31 |  |  | back | right | 264.1 | 251.1 | 18 | 21 | 217 | 20.5 | 244 | 3.6 | 20.19 | drran3; 2dran3 | 19.92; 20.15 | t3-prism-dran3.H2D-MM-PLAstruts-TPUcables.3mf | stls/dran3/dran33-t31-struts.stl | stls/dran3/dran33-t31-cables.stl
dran34 | dran3 | round-3 trial 29 | 29 |  |  | middle | left | 91.2 | 163.3 | 13 | 31 | 217 | 20.5 | 244 | 3.6 | 20.50 | drran4; 2dran4 | 19.92; 20.19 | t3-prism-dran3.H2D-MM-PLAstruts-TPUcables.3mf | stls/dran3/dran34-t29-struts.stl | stls/dran3/dran34-t29-cables.stl
dran35 | dran3 | round-3 trial 28 | 28 |  |  | middle | center | 180.7 | 163.7 | 21 | 29 | 217 | 20.5 | 244 | 3.6 | 19.89 | drran5; 2dran5 | 19.88; 20.22 | t3-prism-dran3.H2D-MM-PLAstruts-TPUcables.3mf | stls/dran3/dran35-t28-struts.stl | stls/dran3/dran35-t28-cables.stl
dran36 | dran3 | round-3 trial 34 | 34 |  |  | middle | right | 264.1 | 163.5 | 16 | 34 | 217 | 20.5 | 244 | 3.6 | 19.98 | drran6; 2dran6 | 19.24; 19.54 | t3-prism-dran3.H2D-MM-PLAstruts-TPUcables.3mf | stls/dran3/dran36-t34-struts.stl | stls/dran3/dran36-t34-cables.stl
dran37 | dran3 | round-3 trial 32 | 32 |  |  | front | left | 91.2 | 72.1 | 24 | 13 | 217 | 20.5 | 244 | 3.6 | 20.48 | drran7; 2dran7 | 20.06; 20.32 | t3-prism-dran3.H2D-MM-PLAstruts-TPUcables.3mf | stls/dran3/dran37-t32-struts.stl | stls/dran3/dran37-t32-cables.stl
dran38 | dran3 | round-3 trial 35 | 35 |  |  | front | center | 180.7 | 71.6 | 26 | 24 | 217 | 20.5 | 244 | 3.6 | 19.93 | drran8; 2dran8 | 19.32; 19.51 | t3-prism-dran3.H2D-MM-PLAstruts-TPUcables.3mf | stls/dran3/dran38-t35-struts.stl | stls/dran3/dran38-t35-cables.stl
dran39 | dran3 | round-3 trial 30 | 30 |  |  | front | right | 264.1 | 72.3 | 31 | 18 | 217 | 20.5 | 244 | 3.6 | 19.94 | drran9; 2dran9 | 19.34; 19.65 | t3-prism-dran3.H2D-MM-PLAstruts-TPUcables.3mf | stls/dran3/dran39-t30-struts.stl | stls/dran3/dran39-t30-cables.stl

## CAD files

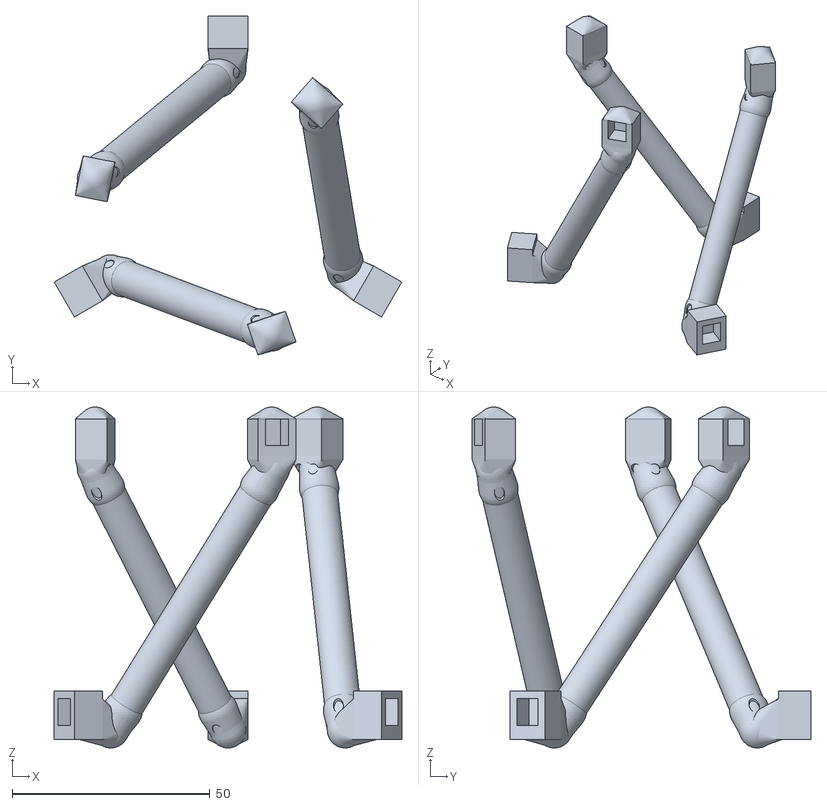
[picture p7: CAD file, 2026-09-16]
bo/per-specimen-stls/t3-prism-bo-round5-t56-struts.stl
87.9 x 85.8 x 86.3

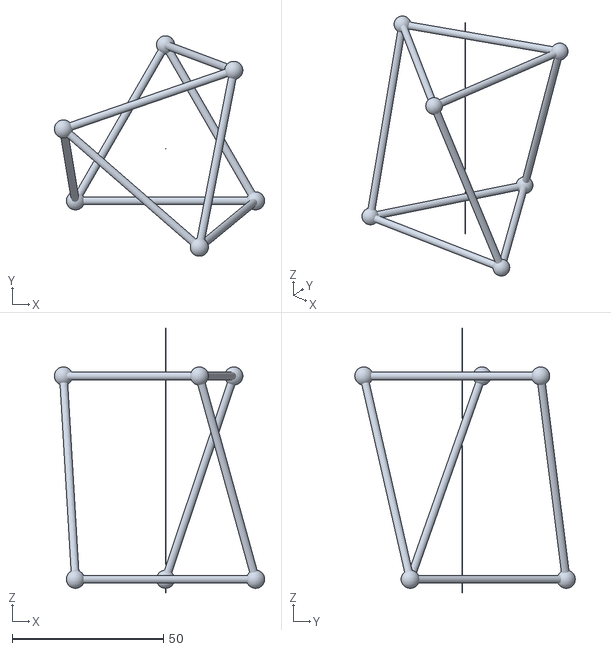
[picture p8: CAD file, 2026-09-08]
bo/replicate-study/stls/corny7-t37-cables.stl
69.4 x 72.8 x 87.2

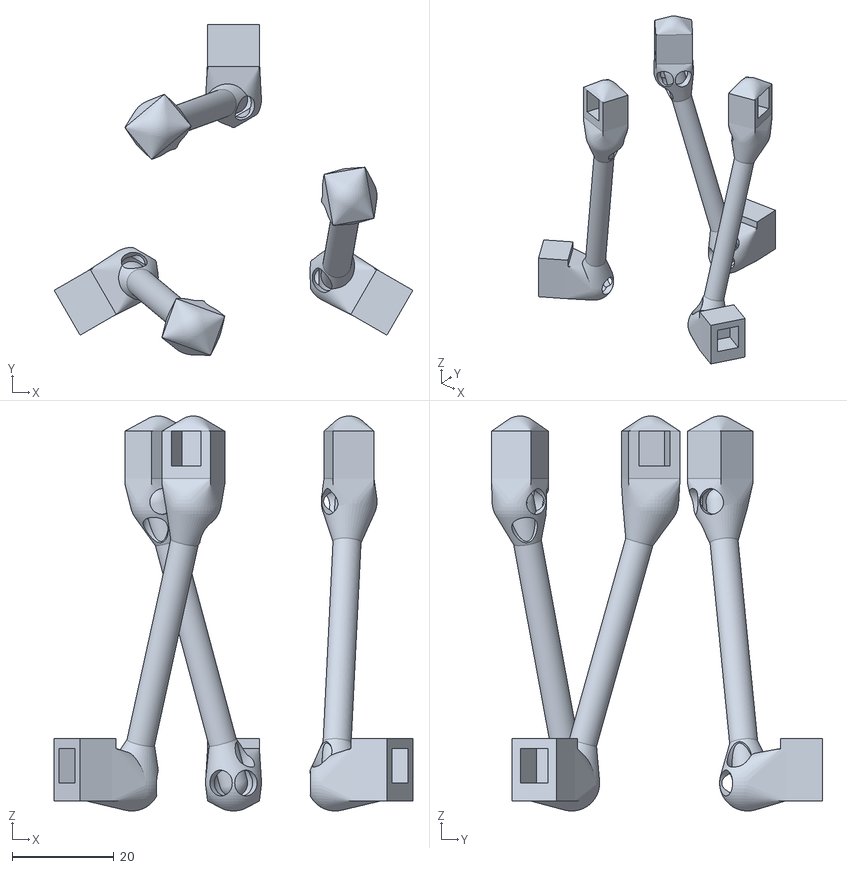
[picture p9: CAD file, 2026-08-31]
bo/replicate-study/stls/dran3/dran32-t33-struts.stl
70.5 x 65.1 x 77.7

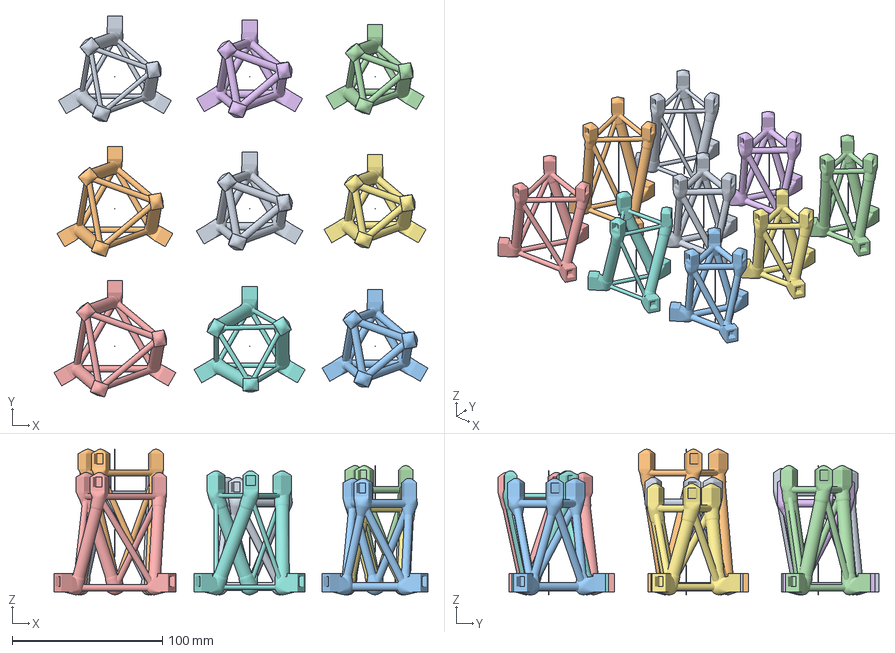
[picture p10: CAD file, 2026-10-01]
bo/replicate-study/t3-prism-dran3.H2D-MM-PLAstruts-TPUcables.3mf
248.7 x 253.3 x 96.9 mm
dran35
dran34
dran39
dran33
dran37
dran32
dran36
dran38
dran31

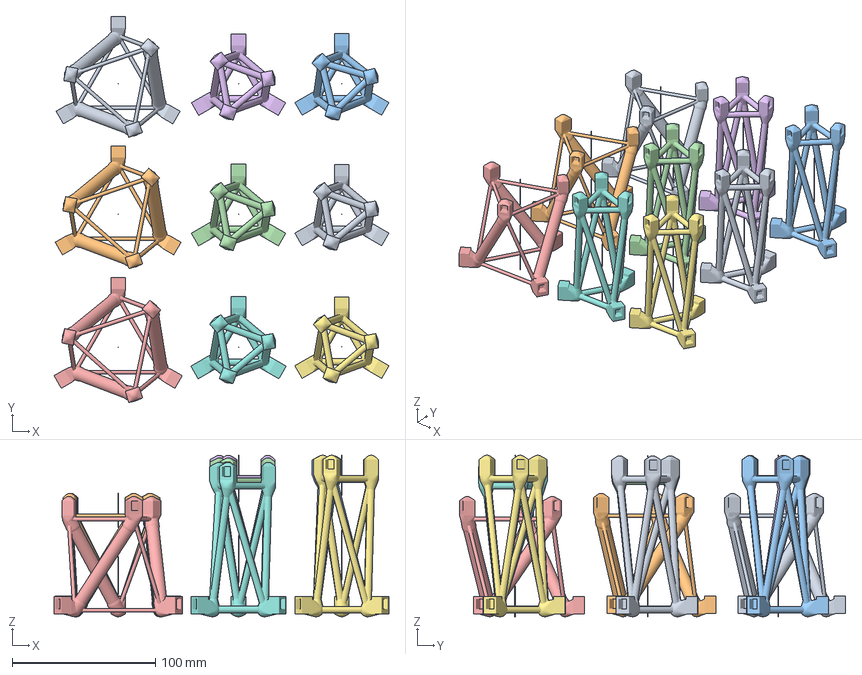
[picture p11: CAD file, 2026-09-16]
bo/slices/t3-prism-bo-round5.H2D-MM-PLAstruts-TPUcables.3mf
234.0 x 269.7 x 112.9 mm
Trial 55
Trial 56
Trial 57
Trial 58
Trial 59
Trial 60
Trial 61
Trial 62
Trial 63

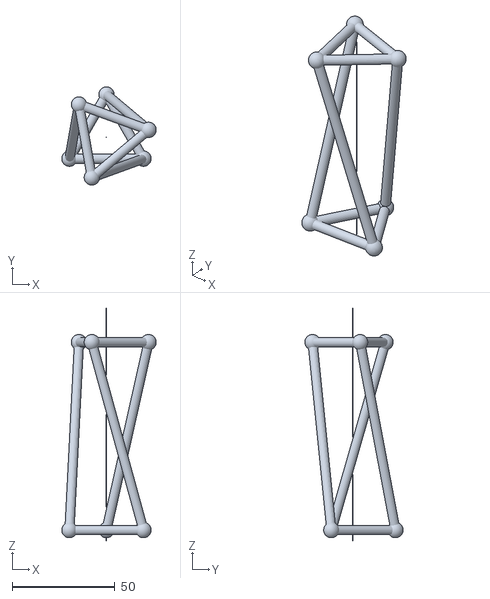
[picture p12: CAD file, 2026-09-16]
bo/per-specimen-stls/t3-prism-bo-round5-t60-cables.stl
45.9 x 47.8 x 112.8

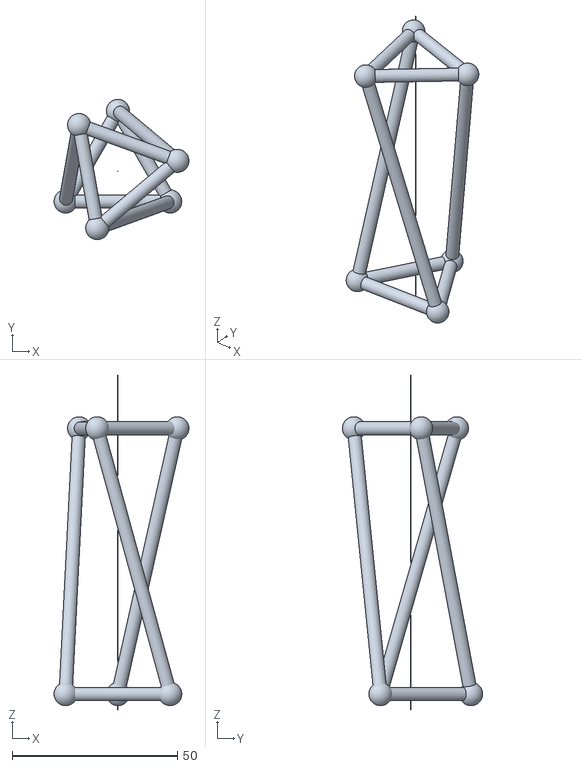
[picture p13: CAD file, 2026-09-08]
bo/replicate-study/stls/corny2-t38-cables.stl
40.8 x 42.4 x 101.0

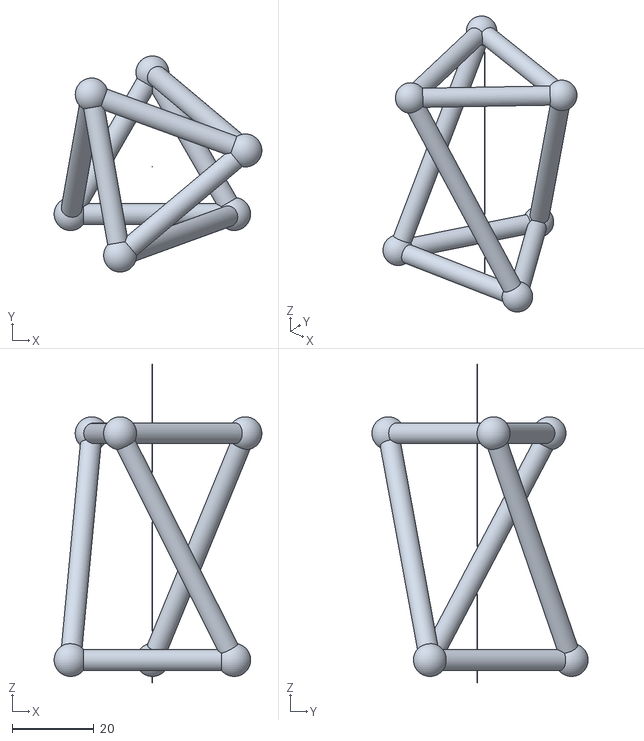
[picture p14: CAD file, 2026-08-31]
bo/replicate-study/stls/dran3/dran32-t33-cables.stl
50.8 x 52.8 x 77.7

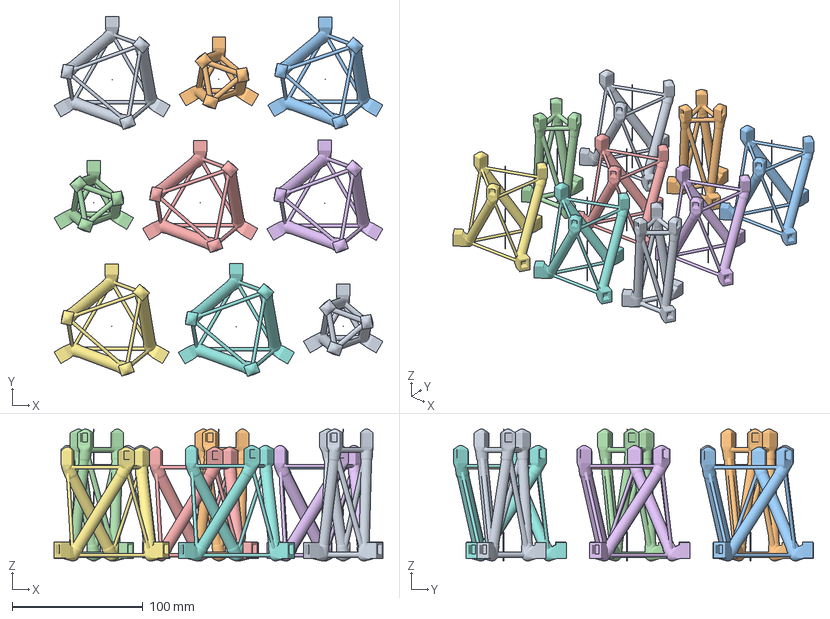
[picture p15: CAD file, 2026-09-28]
bo/replicate-study/t3-prism-replicate-sne-plate2.H2D-MM-PLAstruts-TPUcables.3mf
251.7 x 275.6 x 101.0 mm
2sne81
2sne21
2sne71
2sne22
2sne72
2sne82
2sne73
2sne83
2sne23

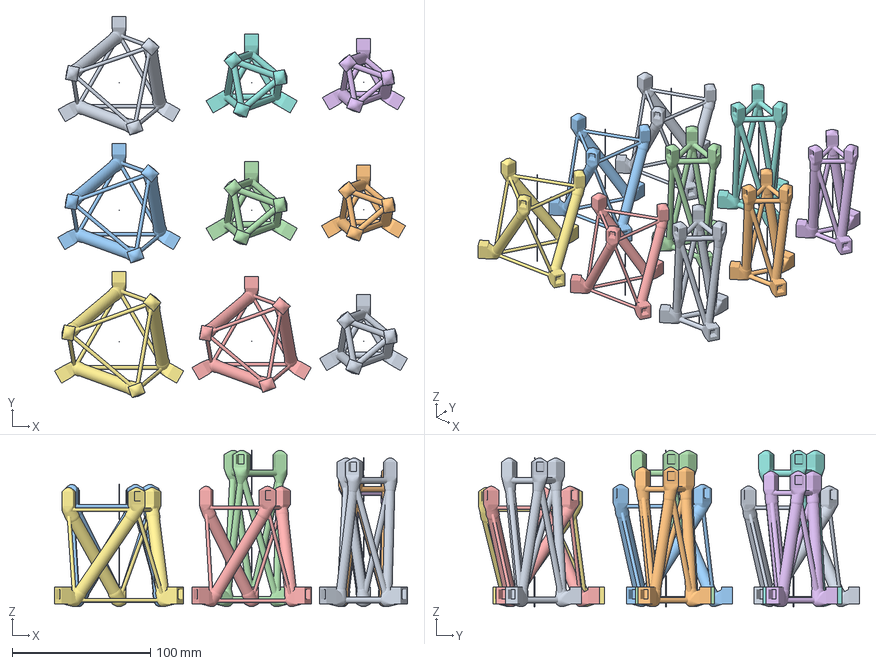
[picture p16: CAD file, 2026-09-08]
bo/slices/t3-prism-bo-round4.H2D-MM-PLAstruts-TPUcables.3mf
255.4 x 275.9 x 113.2 mm
Trial 37
Trial 38
Trial 39
Trial 40
Trial 41
Trial 42
Trial 43
Trial 44
Trial 45

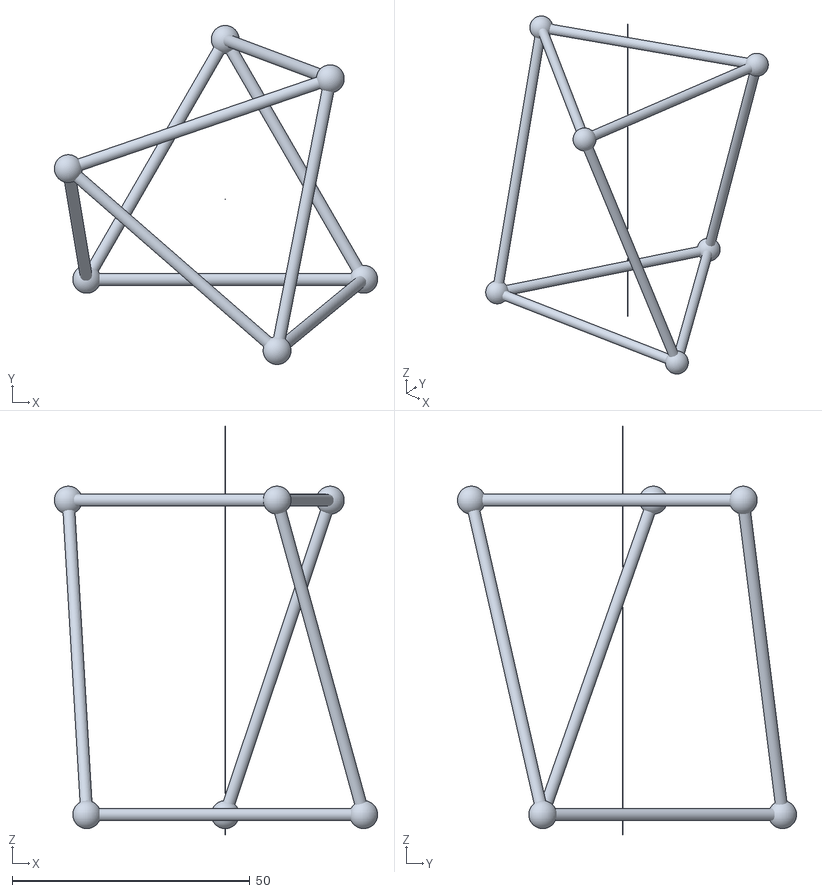
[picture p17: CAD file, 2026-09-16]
bo/per-specimen-stls/t3-prism-bo-round5-t63-cables.stl
68.0 x 71.3 x 86.0

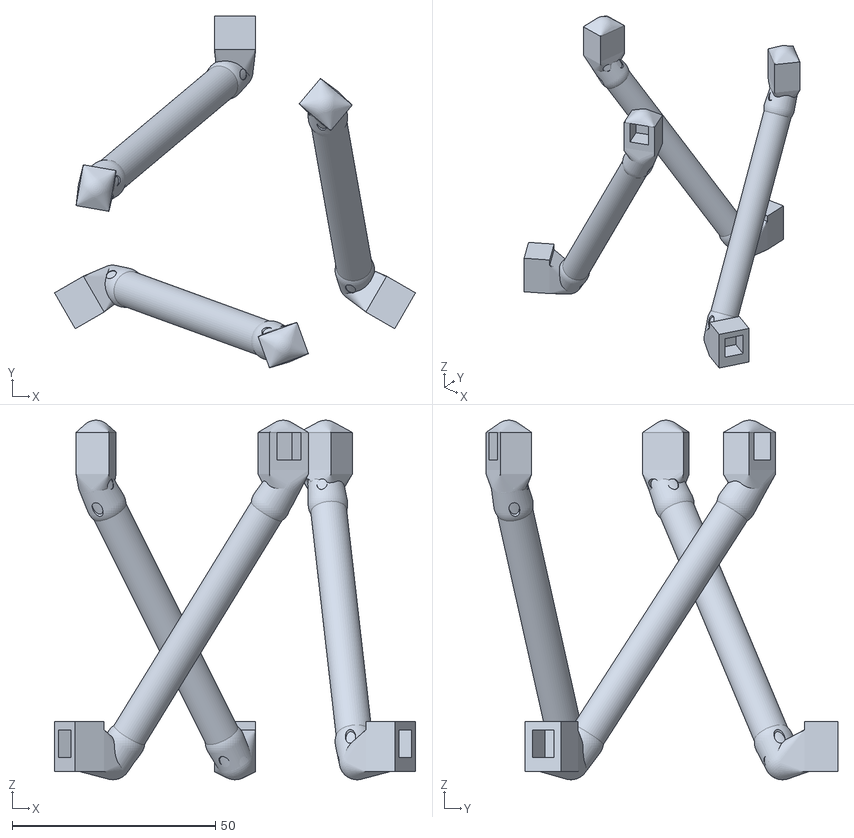
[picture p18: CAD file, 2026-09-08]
bo/replicate-study/stls/corny8-t39-struts.stl
88.8 x 86.5 x 88.4

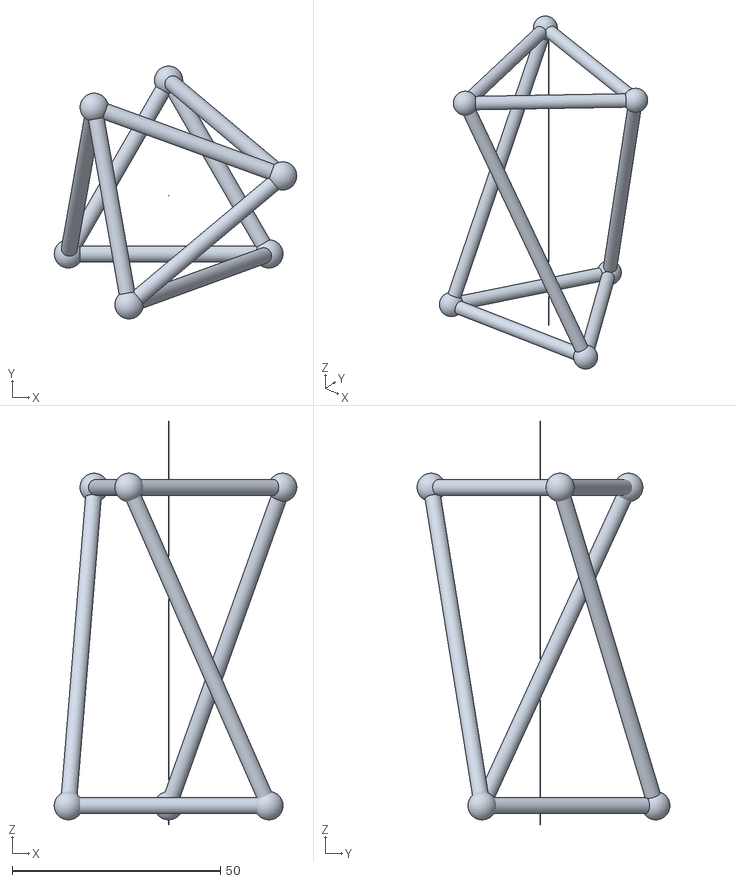
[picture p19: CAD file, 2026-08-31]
bo/replicate-study/stls/dran3/dran34-t29-cables.stl
58.3 x 60.8 x 96.9

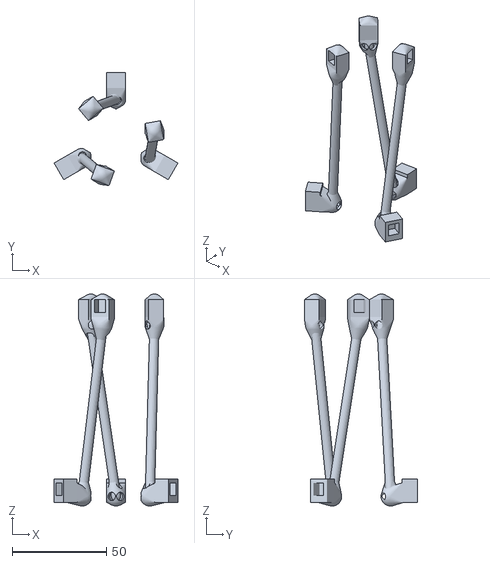
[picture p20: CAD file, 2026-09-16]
bo/per-specimen-stls/t3-prism-bo-round5-t55-struts.stl
65.7 x 60.1 x 112.5

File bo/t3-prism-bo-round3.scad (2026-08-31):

// AUTO-GENERATED by bo/t3_prism_printed_mass_plate.py. Do not hand-edit.
// Preview wrapper for a constant-printed-mass batch: imports the
// per-specimen STLs rendered from cad/t3-prism/t3-prism.scad at the
// scale solved by bo/t3_prism_bo_campaign.py (constant printed grams).
// Plate: 350 x 320 mm (Bambu Lab H2D). Grid: 3 x 3.
part = "all";  // "all" | "struts" | "cables"

if (part == "all" || part == "struts")
    import("per-specimen-stls/t3-prism-bo-round3-t28-struts.stl");
if (part == "all" || part == "cables")
    import("per-specimen-stls/t3-prism-bo-round3-t28-cables.stl");
if (part == "all" || part == "struts")
    import("per-specimen-stls/t3-prism-bo-round3-t29-struts.stl");
if (part == "all" || part == "cables")
    import("per-specimen-stls/t3-prism-bo-round3-t29-cables.stl");
if (part == "all" || part == "struts")
    import("per-specimen-stls/t3-prism-bo-round3-t30-struts.stl");
if (part == "all" || part == "cables")
    import("per-specimen-stls/t3-prism-bo-round3-t30-cables.stl");
if (part == "all" || part == "struts")
    import("per-specimen-stls/t3-prism-bo-round3-t31-struts.stl");
if (part == "all" || part == "cables")
    import("per-specimen-stls/t3-prism-bo-round3-t31-cables.stl");
if (part == "all" || part == "struts")
    import("per-specimen-stls/t3-prism-bo-round3-t32-struts.stl");
if (part == "all" || part == "cables")
    import("per-specimen-stls/t3-prism-bo-round3-t32-cables.stl");
if (part == "all" || part == "struts")
    import("per-specimen-stls/t3-prism-bo-round3-t33-struts.stl");
if (part == "all" || part == "cables")
    import("per-specimen-stls/t3-prism-bo-round3-t33-cables.stl");
if (part == "all" || part == "struts")
    import("per-specimen-stls/t3-prism-bo-round3-t34-struts.stl");
if (part == "all" || part == "cables")
    import("per-specimen-stls/t3-prism-bo-round3-t34-cables.stl");
if (part == "all" || part == "struts")
    import("per-specimen-stls/t3-prism-bo-round3-t35-struts.stl");
if (part == "all" || part == "cables")
    import("per-specimen-stls/t3-prism-bo-round3-t35-cables.stl");
if (part == "all" || part == "struts")
    import("per-specimen-stls/t3-prism-bo-round3-t36-struts.stl");
if (part == "all" || part == "cables")
    import("per-specimen-stls/t3-prism-bo-round3-t36-cables.stl");

// Visual marker for the IDEX prime/flush-tower reserve zone.
if (part == "all") {
  translate([305.00, 5.00, 0])
    cube([40.00, 310.00, 0.2]);
}

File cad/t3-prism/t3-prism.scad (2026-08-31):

// ============================================================================
// Tensegrity Optimization — T3-prism (3-strut tensegrity), single-piece.
// ============================================================================
//
// Geometry
// --------
// A T3-prism (https://en.wikipedia.org/wiki/Tensegrity) consists of:
//   * 3 isolated compression members ("struts"),
//   * 9 tension members ("cables"): 3 on the bottom triangle, 3 on the top
//     triangle, and 3 vertical/saddle cables connecting them.
//
// The two triangular end-caps are identical equilateral triangles inscribed
// in a circle of radius R. The top triangle is rotated by `twist` degrees
// relative to the bottom (per the issue: 60° -- matches the Wikipedia
// reference image cited on the issue).
//
//   B_i = (R*cos(90 + 120*i),               R*sin(90 + 120*i),               0)
//   T_i = (R*cos(90 + 120*i + twist),       R*sin(90 + 120*i + twist),       H)
//
// Connectivity (i in {0,1,2}, mod 3 implied):
//   strut i              :  B_i           --> T_i
//   bottom cable i       :  B_i           --> B_{i+1}
//   top cable i          :  T_i           --> T_{i+1}
//   vertical/saddle i    :  B_{i+1}       --> T_i
//
// Strut i and saddle i meet at T_i but originate at different bottom
// vertices, which is the defining "no two compression members touch each
// other" property of a tensegrity (the struts themselves are kept apart
// by the cables).
//
// Pure-PETG, single-piece print
// -----------------------------
// Per the issue: "Assume pure PETG for now, not multi-material." Both the
// struts and the (thinner) cables are unioned into one solid that prints in
// a single PETG extrusion. Cable diameter is intentionally well above any
// FDM minimum-feature limit so the model survives slicing without dropouts.
//
// Render:  paste into https://openscad.org/demo/  -> F6 (Render)
// Headless STL + PNG preview + Bambu slice (CI/local):
//   bash cad/t3-prism/render_print.sh
// ============================================================================

// ---- Parameters (mm / degrees) --------------------------------------------
// Base (unscaled) geometry. The actual printed dimensions are
// (R, H, strut_d, cable_d, joint_d) * scale_factor.
R_base       = 25;   // radius of the circumscribing circle of each end triangle
H_base       = 70;   // distance between bottom and top triangle planes
twist        = 60;   // rotation of the top triangle relative to the bottom
strut_d_base = 6;    // strut (compression member) diameter
// Cable diameter bumped 2.4 -> 3.0 mm after the first H2D PETG print spaghetti'd
// on layer ~362 of the top-cable bridge (PR #16 review). Edison ANALYSIS
// `25c1c897` recommended 3.0–4.0 mm and Marcus's follow-up print empirically
// confirmed the threshold: at scale 1.3x (cable_d ≈ 3.12 mm), Bambu Studio's
// auto-support logic finally tagged the top cables as needing supports; at the
// original 2.4 mm it skipped them and they sagged/waved. 3.0 mm sits inside
// Edison's window while keeping the tensegrity-cable feel.
cable_d_base = 3.0;  // cable (tension member) diameter -- >= 2*nozzle for FDM
joint_d_base = 7;    // small sphere diameter at each vertex for clean joints
$fn          = 48;

// Uniform scale factor applied to ALL linear dimensions (R, H, strut/cable/joint
// diameters). Bumped 1.0 -> 1.5 per PR #35 comment 4461996817 from @sgbaird:
// "not seeing any supports... the design itself is just too small, if it were
// bigger then we don't necessarily need supports on the TPU." At scale 1.0 the
// 3.0 mm top cables sat just below Bambu Studio's auto-support detection
// threshold, so when the team imported the MM project .3mf and sliced it, the
// slicer skipped supports on the TPU cables and the bridges sagged. At scale
// 1.5 the cables become 4.5 mm Ø — well above Bambu's threshold (verified at
// scale 1.3 ↔ cable_d ≈ 3.9 mm by @achris0520) — and large enough that TPU
// can self-bridge the top-triangle spans without needing supports at all.
// Bounding box at scale 1.5: ~75 × 75 × 115 mm (still fits 4-up on the H2D's
// 350 × 320 mm plate for batch printing — see PR #35 comment 4461855403).
//
// SIZING "S0" (PR #35 comment from @achris0520, 2026-07-01): drop the overall
// specimen to 76.92% of the recent 1.5× generations — i.e. scale_factor =
// 1.5 × 0.7692 ≈ 1.1538. (0.7692 ≈ 1/1.3, so S0 lands just above the scale-1.0
// baseline and a touch below the empirical auto-support threshold the team hit
// at scale 1.3.) Bounding box at S0: ~58 mm footprint, ~115 mm tall including
// the top igloo + bottom flat accelerometer housings. The accelerometer
// housings are PHYSICAL-part dimensions in absolute mm and do NOT scale with
// this factor, so shrinking the prism leaves the sensor pockets full-size.
S0_scale     = 1.5 * 0.7692;  // "S0" specimen sizing = 76.92% of the 1.5× generations
scale_factor = S0_scale;

R       = R_base       * scale_factor;
H       = H_base       * scale_factor;
strut_d = strut_d_base * scale_factor;
cable_d = cable_d_base * scale_factor;
joint_d = joint_d_base * scale_factor;

// `part` selects which subset of members to emit. Used by render_print.sh
// to export the single-material STL ("all") and the two halves of the
// multi-material H2D variant ("struts" -> rigid filament e.g. PLA on
// extruder 1, "cables" -> tougher filament e.g. PETG / eventually TPU on
// extruder 2). The two halves are rendered in the SAME world coordinates
// so the slicer assembles them into the original geometry without any
// per-part transform. The joint vertex spheres travel with the struts so
// the rigid skeleton owns the load-bearing nodes; the cables tie into the
// joints via their own end-cap spheres (`member` adds spheres at both
// ends), giving a multi-material interlock at every vertex.
part       = "all";  // "all" | "struts" | "cables" | "scaffold" | "struts_scaffold" | "all_scaffold"

// ---- Modeled-in PLA scaffold for the TPU cables ---------------------------
// The Bambu CLI's tree(auto) supports reliably scaffold horizontal overhangs
// (lower-triangle and the three top-triangle bridges at the new scale 1.5x)
// but they leave the *near-vertical* members untouched: each strut tilts only
// ~22 deg from vertical, the saddle cables are similar, and Bambu's overhang
// detector measures angle from vertical, so anything below the threshold is
// skipped — even when the slicer is told `support_critical_regions_only=0`
// and `support_threshold_angle=10`. The result on the production
// PLA-struts/TPU-cables print is exactly what @sgbaird-alt's photos show:
// supports under the bottom triangle, but the TPU saddle and top cables
// (and even the strut shafts) wave around mid-print because nothing is
// holding them upright.
//
// Per PR #35 comment 4464251671 ("We want to put PLA support points at 7
// points along the length of the TPU to keep it upright"), we now MODEL the
// scaffolding directly into the geometry as PLA pillars rising from the
// build plate up to evenly-spaced touch-points on each TPU cable. Because
// they are part of the model the slicer cannot omit them, and because they
// are routed to the PLA extruder in the multi-material variant they peel
// off the TPU cleanly post-print (the PLA-TPU bond is weak in shear, ~6.5
// MPa butt; see edison-trajectories/strut-material-selection-5bb5e5d3-*).
//
// `n_scaffolds` interior touch-points per cable, evenly spaced at
// fractions k/(n_scaffolds+1) along the cable's length. Pillars are
// truncated cones (wider at the bed for stability, narrower at the
// touch-point so they snap off without scarring the TPU).
n_scaffolds          = 7;            // touch-points along each TPU cable
scaffold_d_top_base  = 1.4;          // pillar Ø at the cable contact
scaffold_d_bot_base  = 3.0;          // pillar Ø at the bed (taper for stability)
scaffold_min_h_base  = 4.0;          // skip pillars shorter than this (mm, post-scale)

scaffold_d_top = scaffold_d_top_base * scale_factor;
scaffold_d_bot = scaffold_d_bot_base * scale_factor;
scaffold_min_h = scaffold_min_h_base * scale_factor;
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

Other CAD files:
bo/replicate-study/t3-prism-replicate-sne-plate1.H2D-MM-PLAstruts-TPUcables.3mf
bo/slices/t3-prism-bo-round3.H2D-MM-PLAstruts-TPUcables.3mf
bo/replicate-study/stls/corny2-t38-struts.stl
bo/replicate-study/stls/dran3/dran36-t34-struts.stl
bo/t3-prism-bo-round4.scad
bo/t3-prism-bo-round5.scad
bo/per-specimen-stls/t3-prism-bo-round4-t40-cables.stl
bo/per-specimen-stls/t3-prism-bo-round4-t40-struts.stl
bo/per-specimen-stls/t3-prism-bo-round4-t41-cables.stl
bo/per-specimen-stls/t3-prism-bo-round4-t41-struts.stl
bo/per-specimen-stls/t3-prism-bo-round4-t42-cables.stl
bo/per-specimen-stls/t3-prism-bo-round4-t42-struts.stl
bo/per-specimen-stls/t3-prism-bo-round4-t43-cables.stl
bo/per-specimen-stls/t3-prism-bo-round4-t43-struts.stl
bo/per-specimen-stls/t3-prism-bo-round4-t44-cables.stl
bo/per-specimen-stls/t3-prism-bo-round4-t44-struts.stl
bo/per-specimen-stls/t3-prism-bo-round4-t45-cables.stl
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

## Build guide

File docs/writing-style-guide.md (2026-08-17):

# Writing and slide style guide

Every rule here comes from review feedback on real slides.

---

## 1. Never use en dashes or em dashes

**This is the single most repeated piece of feedback on this course's content, and
it is not a matter of taste.** Do not use `—` (em dash) or `–` (en dash) in any
student-facing text. Not in slide titles, not in bullets, not in Canvas
descriptions, not in quiz stems, not in tutorial prose.

They are the clearest single tell that text was machine-written, and this course
asks students not to hand in machine-written work. The material has to hold itself
to that standard first.

Rewrite instead. An em dash is almost always one of four things, and each has a
plain replacement:

| The dash was doing this | Use instead |
| --- | --- |
| Joining two independent clauses | A period. Two sentences. |
| Introducing an explanation or list | A colon |
| Setting off an aside | Commas, parentheses, or delete the aside |
| Separating a label from its value | A colon |

Before and after, from L1:

> **Before:** Once you can see a stress concentration, you can't unsee it — this course rewires how you look at objects.
>
> **After:** Once you can see a stress concentration, you can't unsee it. This course rewires how you look at objects.

> **Before:** The first engaged thread of a bolt — where the crack starts.
>
> **After:** The first engaged thread of a bolt is where the crack starts.

> **Before:** Slides are PowerPoint decks on OneDrive — open a deck and click Present before reading it.
>
> **After:** Slides are PowerPoint decks on OneDrive. Open a deck and click Present before reading it.

**Ranges** are the one place a dash is tempting for a real reason. Use "to" in
prose ("weeks 2 to 3", "1.25 to 2") and a plain hyphen where the range is a label
in a table cell or a short axis annotation ("1-5", "Ch. 3-4"). Do not reach for an
en dash to make a range look typeset.

**Hyphens are fine.** `well-characterized`, `free-body diagram`, `pre-class` are
all correct and unaffected by this rule. The rule is about `—` and `–` only.

**Checking your work.** `python scripts/check_style.py` flags every en dash and em
dash in student-facing paths and exits non-zero if it finds any. Run it before you
commit. It also flags the phrases in section 2.

---

## 2. Do not sound pretentious, and do not sound like AI slop

The reviewer's instruction, verbatim: *"run through every single one of your
sentences as to whether or not it sounds pretentious for people who already know
what they're doing."* And: *"Talk like you're just explaining something, not like
you're trying to give them a talk about why I should invest in your
cryptocurrency."*

Writing that oversells is worse than writing that is plain, because
they can tell.

### The specific patterns to avoid

**a) The grandiose claim about the material's own value.** If a sentence is
selling the content rather than delivering it, cut the sentence.

> **Before:** Seven steps turn a messy real-world problem into a defensible answer, and they earn points on every assignment.
>
> **After:** This is how we want you to solve problems in this class. You get points for each step.

> **Before:** Every phase hands the next one a physical artifact. That is what makes the project hard to fake.
>
> **After:** Each phase builds on the one before it.

**b) The dramatic rhetorical title.** A slide title should state the message of
the slide as a plain sentence. It should not be a slogan.

> **Before:** Why steel survives what chalk can't: ductility.
>
> **After:** Steel yields before it separates, so it fails on the shear plane instead of the tension plane.

> **Before:** Predict before you twist: at what angle will the chalk snap?
>
> **After:** Chalk is brittle, so it breaks on the plane of maximum tension.

**c) "Predict first" framing used as a slogan.** Asking students to predict is
good teaching. Announcing that you are asking them to predict is filler. Ask the
question and stop.

> **Before:** Predict first: tens of MPa, or hundreds?
>
> **After:** (delete, and let the question slide stand on its own)

**d) Invented jargon for ordinary things.** Call it what it is.

> **Before:** The stress element is the bookkeeping device: same point, same state, different numbers at every angle.
>
> **After:** A stress element is a way to draw the stresses at one point so you can see how they change with angle.

**e) Faux-profound one-liners bolted onto the end of a slide.** "Two frames, one
state." "It's everywhere." "The 6.7 is carrying all of it." If the line does not
add information, delete it.

**f) Padding that tells students what they already know.**

> **Before:** Five minutes of recall: every analysis this semester still opens with a free body and ΣF = ΣM = 0.
>
> **After:** Every analysis this semester starts with a free-body diagram.

The reviewer on that one: *"they know that."*

### A test you can actually apply

Read the sentence out loud as if you were standing in front of the class saying it
to a room of seniors. If you would not say it that way out loud, do not write it
that way on the slide. Most pretentious sentences are ones nobody would ever say.

---

## 3. Never write as if students intend to cheat

Cut any sentence whose purpose is to explain why the assignment is
cheat-resistant. It insults the honest majority, and it does not stop anyone.

## 4. Show, do not tell

The reviewer's rule, verbatim: *"If every slide does not have a picture on it, you
failed in some way or another."* And on a slide that listed places stress
concentrations appear: *"We're not seeing it, we're reading it. And that's not how
people visualize."* This might be a bit extreme, but take the principle in mind. There should never be a visual for the sake of a visual. It needs to be an effective redundancy to help get the message across to the audience.

Prose describing a physical thing is nearly always worse than an image of that
thing. This is the Jean-luc Doumont point the deck builders already cite, applied
consistently:

- A bulleted list of stress-concentration locations should be **photographs** of a
  bolt thread, a keyway corner, a weld toe, and a diving-board taper.
- A worked example about a 6 mm eyebolt holding a 150 kg engine should carry a
  **drawing of the eyebolt with the engine hanging off it**, generated with
  matplotlib into `scripts/ppt/figures-shared/` like every other figure.
- A question slide that names a physical setup ("an 800 N rider stands on a
  170 mm crank") needs a **sketch of the crank and spindle**. The reviewer, on
  that exact slide: *"I need pictures."*

**An occasional xkcd comic or similar is allowed and encouraged** where they land, specifically on the safety
factor slide and the A0 onboarding slide. Keep them appropriate for BYU.

---

## 5. Set equations with an equation editor, never as typed text

Equations rendered as ordinary run-on text are the most common formatting
complaint in the review. Two separate instances were called out by name.

> **Before (L1 slide 6, as plain text):** `A = πd²/4 = 28.3 mm² · P = 150 × 9.81 = 1.47 kN`
>
> **Before (L2 slide 8, as plain text):** `C = (σx+σy)/2 · R = √[((σx−σy)/2)² + τxy²] · σ1,2 = C ± R · τmax = R`

Both are unreadable, and both run several distinct equations together on one line
separated by middle dots.

**In PowerPoint:** use the equation editor, which stores OMML
(`<m:oMathPara>`). `scripts/ppt/omml.py` builds OMML from a LaTeX-like string so
deck specs can declare equations as data. Use `{"equation": "..."}` in a spec body
rather than typing a Unicode approximation into a text run.

**In markdown**: use LaTeX in `$...$`
or `$$...$$`.

**One equation per line.** Never join equations with `·`.

**Every equation gets a name and a purpose.** The reviewer: *"on these slides it
should be readily apparent what equations are used for and where they come from,
and in this one it's not readily apparent."*

**Each deck ends with an equation summary slide** listing the equations introduced
in that lecture, what each is for, and when it applies. Students come back to the
decks looking for the equation they need for homework, and that is the slide they
are looking for.

---

## 6. Define a term before you require it

The reviewer hit this three separate times on one phrase, "three distinct machine
elements", which the project brief required before anything defined it.

> *"I need that to be strictly defined before you say 'buy one product that holds
> more than three machine elements'. You've got to be more specific."*

The definition existed. It was 400 words further down the page.

**Rule:** the first time a term appears in a document or a deck, its definition is
already visible, on the same screen or an earlier one. If you are about to write a
requirement that uses a term of art, either define it inline or move the
definition above the requirement. This applies to slide order as much as to page
order.

---

## 7. Use "appear" transitions to help with gradual presentation of content that helps enhance the flow of the delivery of the slide's message (and if you struggle with this, break up into multiple slides to mimic "appear" PPT animation transitions)

> *"If you're mentioning that it's a brittle failure, and you're asking it as a
> question, the answer should not be on the same slide as that question."*

The chalk slide asked "at what angle will the chalk snap?" and then answered it in
the closing line of the same slide. Ensure there is an "appear" animation so that it requires a click to show the answer.

Corollary: do not hand students the equation they are supposed to retrieve. The
crank-spindle question slide printed `τmax = 16T/(πd³)` in the prompt. That
belongs on the solution slide that follows.

---

## 8. No unexplained acronyms

`MoM` shipped on an L1 slide meaning "mechanics of materials". The reviewer, who
teaches this material: *"I don't know what MoM is. Don't use acronyms in slides
like this."*

Write it out. If an acronym is genuinely worth introducing (FBD, FEA, LO), expand
it on first use and then use it consistently.

---

## 12. Put the important thing first

> *"They don't really care about this. This maybe goes at the very end. ... This is
> very important, you should have this be briefed [early]."*

Order sections by what the reader needs, not by what is logically prior.

**Sections that exist for repo bookkeeping should not render to students at all.**

---

## 13. Render images and videos at an appropriate size

On SLIDES, there's a tendency to make images and videos too small. In some cases, it's best to make the image or video fill the entire slide (complete bounds)
and then have the "message title" be in white font text with a black 0% or 50% transparent background *on top* of the image or video that fills the full screen.

**Always credit the source of an image.** The reviewer called this out
approvingly: *"I'm really happy that you put in where it came from. That's really
good."* Keep doing it.

This should **always** be in the speaker notes. **Sometimes** in the slides, especially if the source is more than just some generic Google image. Keep the
citation/caption very short (which means you don't need to make the font size ridiculously small), and always de-emphasize it from the content by making it a 50%-ish (compared to black) gray font. These text boxes 
should be placed close to the item itself.

---

## 14. PowerPoint sections: leave `slide-graveyard` alone

The decks often carry a section named `slide-graveyard`. It holds backup and
retired slides, it is managed by hand by the instructor, and **automation must not
write into it**.

Three rules:

1. Build new content into the default section, never into `slide-graveyard`.
2. Anything placed in `slide-graveyard` must be **hidden** (`show="0"` on the
   `<p:sld>` element), so it cannot appear in presentation mode.
3. **Every slide a script adds must be listed in the section map**, not just in
   the slide list. Those are two independent lists in a `.pptx`, and PowerPoint
   draws a slide no section claims under the section that *precedes* it. Because
   the graveyard is last, an unlisted slide is a slide in the bin.

---

## 15. Get the engineering right

Style never outranks correctness, and two genuine technical errors surfaced in one
50-minute review. Both were in figures, which is where they hide.

- **Stress-element shear arrows must satisfy moment equilibrium.** The L2 element
  drew all four shear arrows producing a clockwise couple, which cannot be in
  equilibrium. With the top arrow pointing in `+x` and the bottom in `-x`, the
  right face must point `+y` and the left face `-y`.
- **Mohr's circle is drawn on axes through the origin, showing all four
  quadrants.** Plot σ on the horizontal axis and τ on the vertical, draw both axis
  lines through the origin, and choose limits that show negative σ. The L2 figure
  showed only the two right-hand quadrants.

When a figure encodes a sign convention or an axis convention, have someone who
teaches the topic look at the rendered image, not the code that generated it.

---

## 16. Fix the pattern, not the instance

Every phrasing tic flagged once in review turned out to be in several other
places. The review called out "Predict before you twist" on one L2 slide. In this context, that
construction was in **20 places across 6 deck specs**

So the last step of any style fix is `grep -rn` for the phrase across the repo,
and fixing every hit. Fixing only the instance you were shown leaves the editor
to find the same thing again next week, which is the most expensive way to run a
review.

The same applies in reverse when you are asked to apply a general principle: a
note about one slide ("this slide needs a picture") can be a note about all slides

---

## 17. What not to over-correct

Plain does not mean flat, and this guide is not a licence to strip the course of
voice. The same review that produced every rule above was unprompted-positive
about the project phase timeline, the machine-element photographs with their
sources recorded, the torsion-failure video, and the concrete tables. The
objection to the Week 1 check-in was the absence of visuals, not the writing.

Keep: concrete numbers, real objects, worked examples, a specific everyday hook,
humour that actually lands, and a stated point of view about engineering
practice. Cut only the sentence that tells the reader how meaningful that point
of view is.

---

## Quick checklist

Before committing student-facing material:

- [ ] No `—` and no `–` anywhere
- [ ] Every sentence survives being read aloud to a room of seniors
- [ ] No sentence explains why the work is hard to fake or to outsource
- [ ] Slides typically have visuals that contribute to the message getting across
- [ ] Every equation is set with the equation editor or LaTeX, one per line, named
- [ ] Every term is defined before it is required
- [ ] No answer shares a slide with its question
- [ ] No unexplained acronyms

- [ ] The phrasing you just fixed was grepped for across the whole repo

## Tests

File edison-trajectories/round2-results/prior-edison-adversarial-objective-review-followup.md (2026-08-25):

# Follow-up adversarial review of round-2 results

**Review date:** 2026-08-25  
**Decision for the 8/25 presentation:** Show that round 2 produced an empirical extension of the measured two-metric set, especially `r2d2c6` at 4.07 mJ, but do not call this a replicated or validated engineering Pareto improvement. The frozen model failed calibration in opposite directions on both outputs. The data establish model misspecification; they do not identify reprojection stiffness as its cause.  
**Decision for round 3:** Do not print the nine proposed articles as a Bayesian-optimization batch. Refit on as-printed geometry, use `t180` as the sole objective with article-level noise, and spend nine print slots on three independently printed articles at each of three geometries: `6lhxfy`, `r2d2c6`, and one newly regenerated design. Re-seat and re-test `r2d2c3` before it enters the fit.

## What changes what you present and print

1. **Correct “8 of 9 rebound values were at or below prediction” to “9 of 9.”** All nine `t180` residuals were positive and all nine rebound-energy residuals were negative. Both sign tests give exact two-sided $p=0.0039$. This is not calibrated uncertainty centered on reality.
2. **Do not present reprojection stiffness as the explanation.** It is a plausible hypothesis, not an identified mechanism. The premise that all articles were 20–30% smaller is not reproduced: seven of nine were shrunk, two were expanded, and only one had scale 0.70–0.80. Round-2 mean scale was 0.865 versus 0.897 in round 1, an unremarkable 3.1 percentage-point difference (exact permutation $p=0.557$). More shrink did not significantly predict larger `t180` error ($r=0.382$, $p=0.310$).
3. **Replace “the uncertainty bands did their job” with an objective-specific calibration statement.** Rebound had 9/9 coverage at nominal 95%, but all observations were on the same side and the bands were very wide. `t180` had only 5/9 coverage at 95% and 1/9 at 68%. Posterior standard deviations of a noise-free mean are not full predictive intervals for a newly printed article.
4. **Keep `e_rebound` as a diagnostic, not a BO objective.** Round 2 materially improves detector-stability evidence, but not event identity or payload relevance. The delayed-event metric may become a constraint after synchronized video and a response-amplitude criterion validate what is being constrained.
5. **Do not use the present round-3 suggestions as evidence for a low-twist optimum.** Eight of nine are at 40° twist and seven of nine at 5.5 mm cables; two also fail stated print constraints. This is another boundary-heavy batch from the same bad likelihood and an altered representation.

# A. Calibration audit

## A1. Recomputed prediction errors

I joined `round2-frozen-predictions.csv` to `round2-print-key.csv` by trial and then to `round2-measured-drop-results.csv` by print ID. I independently reconstructed energy as

$$E_{reb}=e_{rebound}mgh,$$

using $g=9.80665\ \mathrm{m/s^2}$ and $h=1.524\ \mathrm{m}$. The largest discrepancy from `objectives-mass-normalized.csv` was 0.0049 mJ, attributable to rounding. Standardized residuals below use the requested frozen posterior standard deviation of the latent, noise-free mean:

$$z_i=\frac{y_i-\hat\mu_i}{\hat\sigma_i}.$$

| Article | `t180` measured | predicted ± SD | residual | z | rebound measured (mJ) | predicted ± SD (mJ) | residual (mJ) | z |
|---|---:|---:|---:|---:|---:|---:|---:|---:|
| `r2d2c1` | 0.994 | 0.948 ± 0.046 | +0.046 | +1.00 | 5.97 | 8.31 ± 3.18 | −2.34 | −0.74 |
| `r2d2c2` | 1.041 | 0.926 ± 0.095 | +0.115 | +1.22 | 5.62 | 9.90 ± 5.03 | −4.27 | −0.85 |
| `r2d2c3` | 1.334 | 0.910 ± 0.073 | +0.423 | +5.82 | 5.59 | 10.09 ± 5.20 | −4.50 | −0.87 |
| `r2d2c4` | 1.185 | 0.885 ± 0.075 | +0.300 | +4.00 | 6.44 | 12.25 ± 5.73 | −5.80 | −1.01 |
| `r2d2c5` | 1.152 | 0.987 ± 0.066 | +0.165 | +2.48 | 6.71 | 8.37 ± 4.34 | −1.67 | −0.38 |
| `r2d2c6` | 1.055 | 0.953 ± 0.094 | +0.102 | +1.08 | 4.07 | 8.98 ± 5.58 | −4.91 | −0.88 |
| `r2d2c7` | 0.948 | 0.905 ± 0.091 | +0.043 | +0.47 | 12.17 | 13.02 ± 5.11 | −0.86 | −0.17 |
| `r2d2c8` | 1.070 | 0.955 ± 0.071 | +0.116 | +1.63 | 7.89 | 9.97 ± 5.34 | −2.08 | −0.39 |
| `r2d2c9` | 1.053 | 0.873 ± 0.053 | +0.180 | +3.43 | 5.84 | 11.31 ± 4.29 | −5.47 | −1.27 |

### Batch diagnostics

| Diagnostic | `t180` | rebound energy |
|---|---:|---:|
| Mean residual | +0.166 | −3.54 mJ |
| Mean standardized residual | +2.35 | −0.729 |
| SD of standardized residuals | 1.76 | 0.351 |
| Nominal 68% coverage | 1/9 (11%) | 7/9 (78%) |
| Nominal 95% coverage | 5/9 (56%) | 9/9 (100%) |
| Residual signs | 9 positive, 0 negative | 0 positive, 9 negative |
| Exact two-sided sign-test $p$ | 0.0039 | 0.0039 |
| Frozen prediction versus outcome, Pearson $r$ | −0.078 ($p=0.842$) | +0.617 ($p=0.077$) |
| Frozen prediction versus outcome, Spearman $\rho$ | +0.117 ($p=0.765$) | +0.300 ($p=0.433$) |

For context, exact binomial 95% confidence intervals around the empirical 95% coverage rates are 0.212–0.863 for `t180` and 0.664–1.000 for rebound. Nine points cannot estimate a smooth calibration curve. They can expose gross directional bias, which is what happened here.

## A2. Attribution: established misspecification, unresolved mechanism

**Ruling: both noise misspecification and representation shift remain plausible, but the data identify neither as the unique cause. The only firm attribution is model misspecification under deployment covariates.**

What the results establish:

- The frozen model was systematically optimistic for `t180` and systematically high for rebound. Mean residual 95% t intervals across the nine designs were +0.070 to +0.261 for `t180` and −4.94 to −2.15 mJ for rebound.
- It had no ranking skill for `t180` in this batch. That is stronger evidence than simple undercoverage.
- Per-drop SEM was the wrong variance for predicting a new article. It can cause short length scales, excessive confidence, and aggressive acquisition, but **an understated zero-mean noise variance does not by itself predict that every residual will have the same sign**. It explains overconfidence better than directional bias.
- A deployment shift can create directional bias, but the supplied geometry does not isolate it. Round 1 was also projected before printing, no base design was printed at two controlled scales, and scale is confounded with all five design coordinates.

Evidence against presenting shrink as the identified cause:

- Round-2 scales ranged from 0.673 to 1.092. Seven articles shrank and two expanded. The claimed universal 20–30% shrink is false for these files.
- Scale distributions overlap strongly between rounds. Mean scale changed from 0.897 in round 1 to 0.865 in round 2.
- Within round 2, shrink percentage versus `t180` residual gave Pearson $r=0.382$ ($p=0.310$) and Spearman $\rho=0.400$ ($p=0.286$). The corresponding correlations with rebound residual were −0.326 ($p=0.391$) and −0.300 ($p=0.433$).
- The two residuals were negatively associated, as the stiffness story predicts, but weakly: Pearson $r=-0.555$ ($p=0.121$). This is suggestive, not discriminating.

Other plausible contributors are the unmodeled projection mapping itself, extrapolation from only eight mapped round-1 articles, print/mount realization, detector definition, defects in three round-2 articles, and using base coordinates when the tested objects occupy different absolute dimensions. The data do not apportion these causes.

**Round-3 implication:** fix both failures. Use article-level noise and train/generate in the same as-printed representation. Do not choose one remedy based on this batch.

## A3. Scorecard against the 8/21 review

| Prior prediction or conclusion | Result |
|---|---|
| Per-drop SEM would make the optimizer overconfident for new articles. | **Supported for `t180`.** Only 5/9 fell inside nominal 95% latent-mean bands, and three exceeded 3 SD. Rebound bands were wide rather than overconfident. |
| Boundary collapse was not evidence of an optimum. | **Supported.** No round-2 article beat `6lhxfy` on `t180`; the frozen `t180` means had no within-batch ranking skill. |
| qNEHVI was extending a fragile inferred front. | **Partly supported.** The observed empirical front did extend, especially on the low-rebound channel, but not with a validated second objective or article replication. The prior review was too dismissive about the possibility of useful rebound discrimination. |
| `e_rebound` detector was fragile across new geometry. | **Refuted for this batch.** All nine yielded stable values, with within-session rebound CV 0.43–3.82% (median 1.26%) and second-event-time CV 0.36–3.39%. This is meaningful detector evidence. It does not validate event identity. |
| `e_rebound` should not be an objective without physical validation. | **Still supported.** Stable detection answers repeatability within these sessions, not what moved, whether the event is harmful, or whether minimizing flight-time-derived velocity is the correct direction. |
| A batch of one article per design cannot estimate design repeatability. | **Supported and now directly limiting.** No print-to-print variance is available for any new front point. |
| Article-level noise alone explained the collapse. | **The prior review did not claim uniqueness and was right not to.** The new data elevate representation shift as a competing explanation that the prior review did not analyze. |

# B. The rebound channel after round 2

## B1. Status of the metric

Round 2 supplies two real advances:

1. The detector returned stable delayed-event values across nine new geometries, including a 3-fold range in article means from 0.0142 to 0.0440.
2. `r2d2c6` produced a channel value of 4.07 mJ versus the previous absolute-energy floor of 6.10–6.18 mJ, a 33–34% decrease.

That moves `e_rebound` from “fragile diagnostic” to **stable diagnostic in this batch**. It does not make it a valid engineering objective. The formula still estimates a velocity ratio under ballistic assumptions and is then multiplied by $mgh$ without squaring the velocity ratio. It is not measured rebound energy. No synchronized video, relative-motion record, or second-impact amplitude establishes event identity or damage relevance.

Promotion path:

- **To a constraint:** synchronized high-speed video must show that the same detected interval consistently brackets separation and re-contact across at least a high-hop and low-hop geometry, restrained/unrestrained intervention must alter the event as predicted, and the constraint must be stated on a payload-relevant second-impact peak or shock-response-spectrum ordinate. Independently printed articles must reproduce it.
- **To an objective:** all constraint requirements plus an engineering utility showing why lower is monotonically better. The present data do not supply that utility.

## B2. Correlation and whether a front is established

There are 17 mapped articles in `objectives-mass-normalized.csv`, not 18. The eighteenth tested article is unmapped `amdjwm` and correctly cannot enter a design-space or Pareto analysis.

Across the 17 mapped articles:

- `t180` versus absolute rebound energy: Pearson $r=-0.537$, $p=0.026$; Spearman $\rho=-0.456$, $p=0.066$; Kendall $\tau=-0.338$, $p=0.063$.
- Excluding `6lhxfy`: Pearson $r=-0.401$, $p=0.124$; Spearman $\rho=-0.347$, $p=0.188$.
- Round 2 alone: Pearson $r=-0.399$, $p=0.287$; Spearman $\rho=-0.217$, $p=0.576$.
- A 200,000-resample article bootstrap gave a descriptive Pearson 95% interval of −0.785 to −0.166. This interval does not correct measurement error or establish a mechanism.

The anti-association is less dependent on one point than at $n=7$, but rank evidence remains marginal and round 2 by itself does not show a monotonic trade-off. An **empirical nondominated set exists by definition**. A stable physical Pareto front does not yet exist as an evidence-backed claim. A one-dimensional compliance mechanism remains compatible with the data.

## B3. Absolute versus per-gram framing

The recomputed fronts exactly match the flags:

- Absolute mJ: `{6lhxfy, r2d2c7, r2d2c1, r2d2c2, r2d2c6}`.
- Per gram: `{6lhxfy, r2d2c7, r2d2c1, ajhby6, bpx68c, r2d2c6}`.
- Common set: `{6lhxfy, r2d2c7, r2d2c1, r2d2c6}`.

The team’s common-membership claim survives. `r2d2c2` is not robust to framing and is drift-contaminated. Present the **per-gram form as a rescaled diagnostic velocity ratio**, not as specific energy absorption. It removes specimen mass from a quantity whose physical “energy” interpretation is already unsupported. If stakeholders require the historical BO plot, show absolute mJ beside it and state that the front changes.

# C. Rulings on proposed presentation claims

## C1. “The batch genuinely improved the Pareto front…”

**Verdict: survives with a required caveat.** The arithmetic is correct for measured means: four of five absolute-front points are round 2; `r2d2c1` is lower than `bpx68c` on both means; and `r2d2c6` lowers the measured absolute floor from 6.10–6.18 to 4.07 mJ.

Use this caveat verbatim:

> **“This is an empirical front of single printed articles on a physically unvalidated rebound proxy. It is not yet a replicated design-level Pareto front; `r2d2c2` is drift-contaminated, and front membership changes under mass normalization.”**

Do not say `r2d2c1` “strictly dominates” `bpx68c` without “on observed means.” With the 0.72% `t180` floor and a provisional 5% rebound floor, the approximate probability that `r2d2c1` is lower on both is only 0.65. By contrast, `r2d2c6`’s low-rebound separation is large: 4.07 versus 6.10–6.18 mJ.

## C2. “The model was systematically optimistic… plausible physics…”

**Verdict: survives with a required caveat for the first clause; does not survive as a causal explanation.**

Use this caveat verbatim:

> **“All nine `t180` outcomes exceeded their frozen predictions, but these data do not identify why. Reprojection-induced stiffness is one hypothesis; noise misspecification, sparse extrapolation, mounting, defects, and the mismatch between base and as-printed coordinates remain confounded.”**

The sentence “the same stiffness that raises `t180` lowers restitution” is consistent with the signs but is a just-so story at present. Scale did not significantly explain residual magnitude, and there is no controlled same-design/different-scale comparison.

## C3. “The uncertainty bands did their job…”

**Verdict: does not survive.** It is selective. A fair slide statement is:

> **“The wide rebound bands covered all nine measurements but were directionally biased: all nine outcomes were below their predicted means. `t180` was miscalibrated, with only 5/9 inside nominal 95% latent-mean bands.”**

## C4. Additional result worth presenting

Say this:

> **“Round 2 proved that the rebound detector can be stable and design-discriminating within short sessions across nine new geometries, but one article per geometry cannot separate design effects from print and mounting realization.”**

Also say that the frozen model did not improve the primary endpoint: best round-2 `t180` was 0.948 (`r2d2c7`), 0.055 above round-1 best `6lhxfy` at 0.893. Only two of nine round-2 articles had `t180<1`.

# D. Data-quality rulings

## D1. `r2d2c3`

The recorded result is internally stable but physically ambiguous:

- Every scored drop was separated from every other article: `r2d2c3` minimum `t180` was 1.303; the maximum among the other eight was 1.200.
- Its linear drift was −0.0145% per drop ($p=0.703$), so the high mean is not a session ramp.
- `t1000/t180=1.860`, versus 0.999–1.450 elsewhere, is a real signal-processing signature, not random scatter.
- `r2d2c3` and `r2d2c6` have the same base $R,H,$ strut, and cable settings and nearly identical as-printed dimensions; twist differs by 40°. Their large outcome difference could therefore be a real twist-controlled broadband mode. It could also be seating/mount coupling because both `t180` and especially `t1000` are mount-sensitive.

The committed metrics cannot discriminate those explanations. **Hold `r2d2c3` out of training pending re-test.** Do not merely deweight a possible structural outlier into a possible mount outlier.

Minimal re-test: remove and reinstall the accelerometer/mount, document seating, then collect two blinded randomized blocks of 10–12 stabilized drops on the same article, interleaved with `r2d2c6` or `bpx68c`. If the 1.33/2.48 signature survives independent reseating, ingest both sessions with a session effect. If it collapses, mark the first session as a mount failure.

## D2. `r2d2c2`

The drift is not subtle: slope +0.2529% per drop, $p=6.0\times10^{-11}$, with first-five versus last-five means 1.023 and 1.059. **Re-test and exclude the current mean from front and GP claims until a clean session exists.** An illustrative uncertainty that adds half the 3.5% excursion in quadrature is 0.020, versus 0.0083 from the 0.72% floor plus drop SEM, but that inflation assumes an arbitrary drift distribution and does not repair a window-dependent estimand.

## D3. Mixed session lengths

Per-drop SEM is not adequate. It addresses uncertainty in an article’s session mean, not print-to-print prediction. In round 1, first-19 versus full-session differences reached 0.00793 in `t180` (0.747%), essentially the entire 0.72% article floor. For rebound they reached 21.1% for `amdjwm`; even excluding that detector failure, `ajhby6` shifted 3.91%.

For the immediate refit, re-window round 1 to the first 19 stabilized drops so both rounds estimate the same early-session mean. Retain full data for diagnostics. The better later model is a hierarchical drop-index/session model rather than discarding data. Use randomized blocks and a reference article so time drift is estimable rather than silently folded into geometry.

# E. Round-3 ruling

## E1. Diagnosis of the proposed pivot

The new batch is not evidence of genuine low-twist learning. Eight of nine points are at minimum twist and seven at maximum cable diameter. Trial 22 violates the envelope limit and trial 26 violates the cable-bridge rule. The proposed `t180` means, 0.998–1.052 with mean 1.021, sit near the mapped round-1 mean 1.008 and all-data mean 1.053. This is compatible with posterior regression toward the data center after the optimistic corner failed. It is not evidence that the model learned an improved attenuator: no proposed mean approaches observed `6lhxfy=0.893`, and no round-2 article beat it.

The low-rebound side is also tracking a single unreplicated observation: trials 20 and 25 are predicted near 4.85 mJ after `r2d2c6=4.07` mJ. Calling this a learned corner would be premature.

## E2. Concrete formulation and allocation

### Model

- **Objective:** minimize `t180` only, interpreted as a CFC-180 peak-ratio screening endpoint.
- **Exposure controls:** restrict test sessions to the demonstrated healthy input-$\Delta v$ band and include centered session-mean `in_dv_ms` as a nuisance covariate. Record `in_180_g`, pulse width, baseline quality, saturation, block, and reference response. Do not optimize exposure.
- **Diagnostics:** raw `out_180_g`, `t1000`, delayed-event timing and amplitude, measured mass, print defects, and modal-fit outputs where valid.
- **Constraints:** printed mass target 20.23 g with a prespecified manufacturing tolerance based on achieved process capability, envelope ≤250 cm³, cable bridge ≥3.0 mm, no invalid captures, and no unresolved drift flag. Do not use the artificial ±0.01 g optimizer slab as if it were physical process capability.
- **`t180` observation SD:**

$$\sigma_{T,i}=\sqrt{(0.0072y_i)^2+\frac{s_{drop,i}^2}{n_i}}.$$

  Across the supplied mapped articles this is about 0.0064–0.0100; for ordinary, unflagged round-2 articles it is about 0.0068–0.0087. Run sensitivity fits at 0.5%, 1%, and 2% relative floors. Handle `r2d2c2` and `r2d2c3` by data-quality rulings, not arbitrary variance inflation.
- **Rebound, if shown in a non-acquisition sensitivity fit only:**

$$\sigma_{E,i}=\sqrt{(0.05E_i)^2+SEM_{drop,E,i}^2}.$$

  This gives approximately 0.20–0.70 mJ over the mapped data. The 5% term is a conservative sensitivity choice from prior session evidence, not an estimated independent-print SD. Do not use rebound in acquisition until validation.
- **Acquisition:** compare corrected single-objective SAASBO with a regularized conventional GP and a space-filling or Thompson-sampling batch over several seeds. A new geometry should print only if its selection is robust to the 0.5–2% noise range and model choice. qNEHVI is not applicable with one objective; noisy expected improvement or Thompson sampling is.

This follows the distinction between replication noise and exploration used in stochastic Gaussian-process design [Binois et al., 2018](https://doi.org/10.1080/10618600.2018.1458625); [Binois et al., 2019](https://doi.org/10.1080/00401706.2018.1469433). qNEHVI accounts only for uncertainty supplied to its model and does not protect against a wrong objective, likelihood, or covariate representation [Daulton et al., 2021](https://doi.org/10.48550/arXiv.2105.08195). SAASBO’s sparse-axis prior does not remove the need for adequate replication or deployment-valid inputs [Eriksson and Jankowiak, 2021](https://doi.org/10.48550/arXiv.2103.00349).

### Search representation

Refit on **as-printed** `R`, `H`, strut diameter, cable diameter, twist, and measured mass. Generate candidates through the same print-projection function first, then evaluate acquisition at their projected coordinates. Treat measured mass as a post-print covariate/constraint, not a freely exploitable design coordinate.

Printed mass alone does not absorb the representation shift. Two objects can have the same mass and different absolute dimensions, strut slenderness, cable section, and material distribution. A model fitted to base coordinates plus mass still asks the GP to infer an unobserved nonlinear projection from 17 articles. A projection-regime indicator cannot be estimated before any outcomes exist under the new regime. The clean bridge is to reproduce known as-printed geometries under controlled manufacture and ingest realized geometry and mass.

### Nine print slots

Print **three independently manufactured articles at each of three geometries**:

1. Three at the as-printed `6lhxfy` geometry, the unreplicated primary-endpoint best.
2. Three at the as-printed `r2d2c6` geometry, the unreplicated low-rebound extreme.
3. Three at one newly regenerated, constraint-valid geometry selected by agreement among corrected fits.

Use 10–12 stabilized drops per article after two warm-ups, randomized in blocks, with the same durable reference article at block start and end. The existing originals should not be counted as exchangeable replicates if process/projection conditions differ.

**Print decision:** regenerate. Print none of trials 19–27 as a BO recommendation. If schedule makes partial use unavoidable before refitting, trials 19, 20, and 24 are the only defensible sentinel subset because they are constraint-valid and span distinct corners; label them “model-diagnostic sentinels,” not optimized round-3 designs. Do not print trials 22 or 26.

## E3. Does the mass parameter fix the shift?

No. It helps condition on one important realized property, but it cannot encode the change from constant-solid-mass scaling to constant-printed-mass manufacture. The corrective action is as-printed geometry for fitting and generation, measured mass as a covariate/constraint, and matched replication bridging the manufacturing regimes. Any prediction under the new projection policy remains an extrapolation until such bridge data exist.
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

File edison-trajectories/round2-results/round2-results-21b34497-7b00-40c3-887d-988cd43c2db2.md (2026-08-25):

Completed the requested self-contained review and committed it under the requested workspace path:

`/workspace/edison-trajectories/round2-results/prior-edison-adversarial-objective-review-followup.md`

Download: [prior-edison-adversarial-objective-review-followup.md](data_entry:prior-edison-adversarial-objective-review-follo-4odm)

Key rulings:

- **Calibration:** all 9 `t180` outcomes were above prediction and all 9 rebound-energy outcomes were below prediction. Both exact two-sided sign tests give $p=0.0039$. Nominal 95% coverage was 5/9 for `t180` and 9/9 for rebound, but the rebound bands were wide and directionally biased.
- **Attribution:** noise misspecification explains false precision, while the base-versus-as-printed representation mismatch could explain directional deployment bias. These data do not identify either as the unique cause. The claimed universal 20–30% shrink is not reproduced by the files.
- **Presentation:** the observed front extension survives only as an empirical, unreplicated result on an unvalidated rebound proxy. The causal stiffness story does not survive. “The uncertainty bands did their job” does not survive.
- **Rebound:** round 2 refutes the claim that the detector is generally unstable across new geometries, but does not validate event identity, energy interpretation, or engineering utility. Keep it diagnostic pending video and second-impact-response validation.
- **Data quality:** hold `r2d2c3` out pending a reseated re-test; re-test and exclude the current drift-contaminated `r2d2c2` mean from front and Gaussian-process claims; re-window round 1 to the first 19 stabilized drops for the immediate refit.
- **Round 3:** regenerate rather than print trials 19–27 as a Bayesian-optimization batch. Use one objective, minimize `t180`, with
  $$\sigma_{T,i}=\sqrt{(0.0072y_i)^2+s_{drop,i}^2/n_i},$$
  fit and generate using as-printed geometry, and treat measured mass as a realized covariate/constraint. Allocate nine slots as three independent prints each of `6lhxfy`, `r2d2c6`, and one corrected-model design.
- **Cheapest high-value measurement:** re-seat and re-test `r2d2c3`; this determines whether the largest anomaly should enter the small round-3 training set.

**Discretionary analytical decisions**

- Treated independently printed articles, rather than drops, as design-level replicates.
- Used two-sided exact sign tests at $\alpha=0.05$ and assessed nominal 68% and 95% coverage against frozen latent-mean posterior standard deviations.
- Used Pearson, Spearman, and Kendall correlations plus leave-one-out sensitivity and a 200,000-resample article bootstrap.
- Used a 0.72% coefficient-of-variation floor for `t180`, with recommended sensitivity fits at 0.5%, 1%, and 2%.
- Used a 5% relative rebound floor only for sensitivity calculations, not as an estimated print variance.
- Matched short-session comparisons at the first 19 stabilized drops.
- Preferred holding contaminated or ambiguous articles out over assigning subjective inflated variances.
- Chose a three-geometry by three-print allocation to estimate article repeatability while retaining one exploration geometry.
- Preferred the per-gram rebound display as a mass-removed diagnostic, while explicitly not interpreting it as specific absorbed energy.

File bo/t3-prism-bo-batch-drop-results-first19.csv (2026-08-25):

specimen | n_valid | dv_health | t180_mean | t180_sd | t1000_mean | t1000_sd | out_180_g_mean | out_180_g_sd | in_180_g_mean | in_180_g_sd | in_dv_ms_mean | in_dv_ms_sd | t_second_ms_mean | t_second_ms_sd | e_rebound_mean | e_rebound_sd | fn_hz_mean | fn_hz_sd | zeta_pct_mean | zeta_pct_sd | H_mm | R_mm | cable_d_mm | mass_g | spec | strut_d_mm | twist_deg
6lhxfy | 19 | healthy | 0.8894518996659133 | 0.004592172450978083 | 0.9126730324377276 | 0.0131563220511432 | 200.0408277395844 | 4.6514371915461785 | 224.01245885825836 | 5.995658100190466 | 5.372048406038164 | 0.0934751567632233 | 55.178585858587184 | 0.8852545005920192 | 0.049476545936448034 | 0.0005147775762654713 | 368.3766929752503 | 17.11345069852911 | 10.146626604741746 | 0.9777540895501612 | 68.08 | 28.72 | 2.55 | 18.5 | 01 | 9.24 | 77.4
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

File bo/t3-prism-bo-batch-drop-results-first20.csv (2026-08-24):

specimen | n_valid | dv_health | t180_mean | t180_sd | t1000_mean | t1000_sd | out_180_g_mean | out_180_g_sd | in_180_g_mean | in_180_g_sd | in_dv_ms_mean | in_dv_ms_sd | t_second_ms_mean | t_second_ms_sd | e_rebound_mean | e_rebound_sd | fn_hz_mean | fn_hz_sd | zeta_pct_mean | zeta_pct_sd | H_mm | R_mm | cable_d_mm | mass_g | spec | strut_d_mm | twist_deg
6lhxfy | 20 | healthy | 0.8896846681209369 | 0.004589310802173398 | 0.9126730324377276 | 0.0131563220511432 | 200.0408277395844 | 4.6514371915461785 | 224.01245885825836 | 5.995658100190466 | 5.372048406038164 | 0.0934751567632233 | 55.178585858587184 | 0.8852545005920192 | 0.04951616963508894 | 0.0005314598267819085 | 368.3766929752503 | 17.11345069852911 | 10.146626604741746 | 0.9777540895501612 | 68.08 | 28.72 | 2.55 | 18.5 | 01 | 9.24 | 77.4
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

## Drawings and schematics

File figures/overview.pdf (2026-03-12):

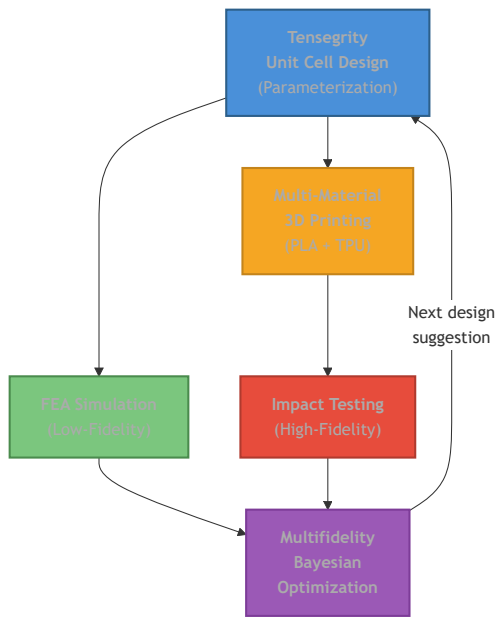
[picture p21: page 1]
Next design suggestion; FEA Simulation (Low-Fidelity); Multi-Material 3D Printing (PLA + TPU); Impact Testing (High-Fidelity); Multifidelity Bayesian Optimization

Tensegrity
Unit Cell Design
(Parameterization)

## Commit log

2026-03-09 Restructure MRG proposal: add cover page, bio sketches, update content for multi-material 3D printing and multifidelity BO
    - Create sections/coverpage.tex with PI/Co-PI, abstract, budget table, external funding
    - Create sections/biosketch.tex with Hill and Baird biographical sketches
    - Restructure proposal.tex to MRG format (motivation, background, student projects, mentoring, outcomes, impact)
    - Update content: multi-material 3D printing (TPU+PLA), multifidelity BO (Mo et al. 2023), named conferences (ASME IDETC, UCUR)
    - Update sections/budget.tex: align categories (undergrad wages, grad wages, supplies, travel, other)
    - Update references.bib: add Mo et al. (2023), fix placeholder entries,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
2026-03-10 Apply review fixes, strengthen mentoring focus, add figure placeholder, de-emphasize grant seeding
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2026-03-10 Replace Lookman citation with AlphaGo, concrete, and dye laser references
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2026-03-12 Shift proposal to experiment-driven approach, disperse mentoring throughout
    - Rewrite Research Motivation to emphasize high-throughput 3D printing over simulation
    - Revise Background to frame BO as operating on experimental data directly
    - Restructure Student Project 1: design/fabrication focus, open to sophomores
    - Restructure Student Project 2: testing and single-fidelity BO on experiments
    - Strengthen Mentoring section: experiment-driven milestones, broader recruitment
    - Weave mentoring language into all project sections (co-mentoring, scaffolding)
    - Simplify Timeline: remove FEA/simulation rows, add print campaigns and testing
    - Update abstract and outcomes to reflect experiment-first st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
2026-04-20 Incorporate Edison PRECEDENT feedback: add 3 new refs (qNEHVI, LogEI, constrained MOBO), tighten claims, commit to qNEHVI, specify feasibility constraints and mixed-variable encoding
    Agent-Logs-Url: https://github.com/vertical-cloud-lab/byu-mentored-research-tensegrity/sessions/59a1bf39-051a-4fe4-b94b-bcd3df228b07
2026-04-20 Incorporate Edison ANALYSIS feedback: tighten interface claim, soften sidesteps/correct/much, drop duplicate cite, scope Khatri to multi-material context
    Agent-Logs-Url: https://github.com/vertical-cloud-lab/byu-mentored-research-tensegrity/sessions/02dc6eeb-b5d4-4fb1-8c4f-cd9ea5852bbd
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2026-08-21 Add T-3_01 Sobol batch print key: as-printed .3mf, ID-to-spec CSV, visual key
    The .3mf uploaded in issue #98 names each plate with its print ID and
    carries one Sobol specimen per plate, recovering the print-to-parameters
    mapping needed for parsing drop data. Includes the batch design table
    from PR #35 (32addaf) and flags the Spec 08 official-print discrepancy
    (dea4ls per .3mf plate label vs bag26v per issue comment).
    [t3-prism-bo-batch-print-key.csv, t3-prism-bo-batch.H2D-MM-PLAstruts-TPUcables.as-printed.3mf, t3-prism-bo-batch.csv]
2026-08-21 Add Honegumi SAASBO campaign script: ingest 8-specimen drop results, suggest round-2 batch
    Multi-objective (t180, e_rebound), fully Bayesian, batch, existing-data
    Honegumi template adapted for the physical campaign: Sobol init step
    dropped (PR #35 batch was the init), results ingested from the PR #86
    campaign_summary.csv snapshot, specs 03/06/07 attached as pending
    trials, amdjwm skipped until its spec mapping is resolved. Records 9
    suggested base-space designs with posterior predictions, the AxClient
    state, and a Pareto + parameter-space figure.
    [t3-prism-bo-batch-drop-results.csv, t3-prism-bo-suggestions-round1.csv]
2026-08-21 Submit BO-objectives claim to Edison for adversarial + Socratic review
    Task 3e398131: Edison derives its own objective set from the per-drop
    campaign data before reading ours, then attacks the three legs of the
    hand-off claim (t180+e_rebound objective pair, the n=8 trade-off/Pareto
    framing, and the per-drop-SEM noise model that ignores the ~2% print floor).
    Bundle: 23 files across three branches (per-drop metrics, series tables,
    analysis doc+script, print-defect floor study, #97 energy review, BO script).
    Follows the d9092c5a precedent from PR #86.
2026-08-21 Account for per-print mass in BO objectives: e_reb_mJ objective, mass_g tracking metric, regenerated round-1 suggestions
    [t3-prism-bo-suggestions-round1.csv]
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2026-08-21 Pareto figure: match hand-made reference style; prototype round-2 predicted-vs-measured view
    Restyles the objective-space panel to the reference posted on PR #102:
    leader-line callouts instead of a legend box, detached left/bottom spines,
    open black circles for tested articles with blue-filled front points,
    larger type, greedy label decluttering in place of hand-tuned offsets.
    Adds --prototype-next-round, which draws the post-round-2 layout: each
    predicted diamond joined by a straight path to where the article actually
    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
    [t3-prism-bo-round2-outcomes-PROTOTYPE-dummy.csv]
2026-08-21 Animate the round-2 predicted-vs-measured prototype (GIF + MP4)
    The prototype figure was asked for as a short clip rather than a still.
    Same visual grammar, played out in time: the suggested batch holds as
    orange diamonds, each prediction then travels its straight path to the
    measurement (staggered and eased) and hands off to an open black circle on
    arrival, and the Pareto front is recomputed while the round-1 front drops
    back to a pale dashed line and the round-2 print IDs fade in. The last
    frame matches the still PNG so the two artifacts agree.
    Round-2 outcomes are still synthetic; nothing has been printed or dropped.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
2026-08-21 Add Ax interpretability diagnostics: SAAS feature importance, LOOCV, signed parameter effects
    Three figures plus their tables, refit from the committed round-1 AxClient
    snapshot:
    - Feature importance from TorchModelBridge.feature_importances (median SAAS
    lengthscale over MCMC draws, inverted, normalized), with an interquartile
    band across the individual draws that the single-number API discards.
    - Leave-one-out via cross_validate(folds=-1) + compute_diagnostics. Passes
    refit_on_cv=True: BoTorchModel defaults it to False in Ax 0.5.0, which
    reconditions on the fold while keeping hyperparameters fitted on all the
    data and flatters the result.
    - Signed parameter effects by model-based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
    [t3-prism-bo-round1-feature-importance.csv, t3-prism-bo-round1-loocv.csv, t3-prism-bo-round1-parameter-net-effects.csv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]
2026-08-21 Constant printed mass: calibrated mass model, mass as a BO parameter, fit_out_of_design
    Round 1 was projected onto constant *solid* mass (PR #35 Route A: uniformly
    re-scale until rho_PLA*V_PLA + rho_TPU*V_TPU = 30.95 g), not constant volume
    and not constant printed grams. All 9 articles sit at that solid mass and
    still weigh 18.50 to 22.29 g, because PLA prints sparse while thin TPU cables
    print near solid and the PLA/TPU split swings with the geometry.
    bo/t3_prism_mass_model.py calibrates the gap in two stages (analytic volumes
    against the 9 rendered designs; rendered solid grams against the 12 weighed
    articles, with a wall-plus-infill term in the as-printed strut diameter) and
    inverts it.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
    [t3-prism-bo-round1-feature-importance.csv, t3-prism-bo-round1-loocv.csv, t3-prism-bo-round1-parameter-net-effects.csv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]
2026-08-21 Animation: fade out the prediction layer and rest on the round-2 figure
    The clip now ends by clearing its own scaffolding. After a beat on
    predicted-versus-measured, the orange diamonds, travel paths, arrowheads,
    round-1 front and the callouts that named them fade out together, so the
    last ~2.4 s is the round-2 Pareto figure alone.
    render_prediction_vs_actual_figure gains show_predictions=False, which
    draws that resting state as a still (t3-prism-bo-round2-front-final-
    PROTOTYPE.png), so the animation's last frame and a committed PNG agree.
    Also moved the 'Pareto front after round N' callout off the front line,
    where it collided with the r2-14 label once the diamonds were gone.
    Co-authored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
2026-08-21 Animation: one idea per beat, and labels that dodge the callouts
    The round-2 prototype clip had too much moving and too much text on screen
    at once (PR #102 review). Re-choreographed so each beat carries one idea:
    the round-1 front is retired before anything moves, the diamonds then travel
    on an otherwise clean panel, and the new front is redrawn as its own step,
    after every article has landed and turned into an open black circle, wiping
    in along the polyline and filling each article as it reaches it.
    Text is thinned to match: the Round-1 front callout is gone, at most one
    callout is lit while anything is in motion, and point labels now dodge the
    callout text, the callout leaders, the front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
2026-08-24 Prototype animation: predicted +/- 1 sd bars and ovals, frozen before travel
    New uncertainty beat between retiring the round-1 front and the travel: each
    suggested point grows a horizontal and a vertical bar spanning one posterior
    sd per objective plus a shaded axis-aligned oval through the same contour,
    in faded suggestion orange, and the panel freezes so they can be read. The
    layer stays at the predictions at ghost opacity through the travel and
    leaves with the clean-up. The sd is the model posterior for the noise-free
    objective (diagonal of TorchModelBridge.predict's covariance); only the
    marginals were recorded, hence axis-aligned ovals. Fourth registered still
    (-uncertainty-PROTOTYPE.pn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
2026-08-24 Round-2 first drop data (r2d2c1-c3) from Box, plus the missing ajhby6 round-1 session
    Data lives in the shared Box folder's Drop Test Data subfolder; fetched with
    PR #86's fetch_box_shared_folder.py (copied here) and analyzed with that
    branch's drop_test_campaign_analysis.py unchanged. Print-ID-to-spec mapping
    for the r2d2c batch is inferred from plate raster order + the mass model and
    flagged as unconfirmed in the key.
    [t3-prism-bo-batch-drop-results-first20.csv, t3-prism-bo-batch-drop-results.csv, t3-prism-bo-round1-drop-results.csv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]
2026-08-24 Mass-normalized rebound objective table; r2d2c ID mapping confirmed by 8/24 photos; RH/defects for c1-c3
    [t3-prism-bo-objectives-mass-normalized.csv, t3-prism-bo-round1-print-key.csv]
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2026-08-24 Full round-2 drop data (r2d2c1-c9): pipeline results, BO ingestion of both rounds, measured predicted-vs-actual mode
    All nine r2d2c sessions from Box through the PR #86 campaign analysis
    unchanged (r2d2c8's export-name quirk fixed at fetch time). Ingestion now
    attaches both batches (18 tested articles); --measured-round2 renders the
    real-data predicted-vs-measured figure set; mass fit bounds widened to
    cover 17.91-23.47 g; objective-figure limits follow the data.
    [t3-prism-bo-objectives-mass-normalized.csv, t3-prism-bo-round1-designs.csv, t3-prism-bo-round1-drop-results.csv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]
2026-08-24 Round-2 measured outcomes + SAASBO refit: round-3 suggested batch, measured predicted-vs-actual figure set
    Refit on all 18 tested articles (specs 03/06 pending); round-3 batch of 9
    at constant 20.23 g printed mass recorded to suggestions-round2.csv with
    AxClient snapshot. Measured figure set: registered stills, MP4, GIF; the
    Measured callout flips sides when its anchor is near the panel edge.
    [t3-prism-bo-suggestions-round2.csv]
2026-08-25 Print key: RH/defects for r2d2c5-c9 from Ronnie's 8/24 print-log entries; README notes on folder rename and as-printed geometry columns
    [t3-prism-bo-round1-print-key.csv]
2026-08-25 Fetch Edison objectives-review artifacts (task 3e398131): full report, locked Section A, notebook
    Verdict: drop e_rebound as objective, single-objective t180, article-level noise (0.72% CV); do not print round-2 as-is (it was already printed; verdict arrived late but is now testable against measured round-2 data)
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2026-08-25 Edison round-2 results review (task 21b34497) complete: report, answer, notebook
    Verdict: front extension survives only as unreplicated empirical claim on unvalidated rebound proxy; stiffness attribution does not survive; regenerate round 3 (single-objective t180, article-level noise, as-printed geometry, 3x3 replication of 6lhxfy / r2d2c6 / one regenerated design); hold r2d2c3 out pending reseated re-test
2026-08-25 LOOCV figure/animation set in the round-2 grammar: 17-article round-2 diagnostics refit, held-out predictions travel to measured outcomes
    [t3-prism-bo-round2-feature-importance.csv, t3-prism-bo-round2-loocv.csv, t3-prism-bo-round2-parameter-net-effects.csv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]
2026-08-25 Parity-evolution figure set: two parity panels (one per objective, +/- 1 sd bars), predictions travel from the plate-generating model to the all-data refit
    --parity-evolution mode in bo/t3_prism_bo_diagnostics.py. Before state is
    commit 7a048ee's AxClient (restored from git history as a committed
    snapshot): frozen suggestions CSV verbatim for the nine r2d2c articles,
    seeded refit for the round-1 articles (fidelity vs frozen CSV: 0.3 sd).
    After state is the round-2 snapshot refit on all 17 articles, in sample.
    Three registered stills + GIF/MP4 in the established grammar; measured
    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
    [t3-prism-bo-round2-parity-evolution.csv]
2026-08-25 LOOCV-evolution figure set: held-out parity per objective, initialization dataset (8 articles) vs all collected data (17), same 6-D model class per fold; rebound rank corr +0.24 to +0.70, t180 round-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
    [t3-prism-bo-loocv-evolution-init.csv, t3-prism-bo-loocv-evolution.csv]
2026-08-25 Session QC comparison, round 1 vs round 2: substitute crew ran the protocol faithfully; rig input today was the most uniform block in the project; three round-2 sessions (c2, c3, c8) exceed round-1's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
    [t3-prism-round-qc-comparison.csv]
2026-08-25 Drop-window reconciliation: round-2 short sessions extrapolated to full-session behavior via round-1 drift ratios; matched first-19 round-1 summary emitted; front membership checked under three windo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
    Answers the 20-vs-100-drops question with committed data: t180 window
    effect is 0.15 percent pooled (cannot explain the +0.04 to +0.42 misses),
    rebound carries a +/- 8 percent band with a +27 percent burst tail
    (amdjwm), calibration verdicts survive extrapolation 9/9 and 9/9, front
    core is window-invariant, and the r2d2c1-dominates-bpx68c claim is
    short-window only.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
    [t3-prism-bo-batch-drop-results-first19.csv, t3-prism-drop-window-extrapolation.csv, t3-prism-drop-window-front-robustness.csv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]
2026-08-26 Print-process design variables and the round-3 batch: strut/TPU infill, both nozzle temperatures and both volumetric speeds join the search space; 9 articles at exactly 20.23 g printed across 3 plates
    Six slicer settings that had been unchosen stock defaults are BO parameters
    from round 3 on (PR #102 request, 2026-08-26): sparse infill density of the
    strut (PLA) and cable (TPU) parts, and nozzle temperature and max volumetric
    speed for each filament. Speed is parameterized as the filament's max
    volumetric speed because that is what binds: the process profile's 200 mm/s
    outer wall is 37 mm^3/s at a 0.62 x 0.30 mm bead, above both materials' caps,
    and Bambu Studio has no per-material mm/s at a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
    [t3-prism-bo-round1.H2D-MM-PLAstruts-TPUcables_manual-supports.3mf, t3-prism-bo-suggestions-round3.csv, t3-prism-slicer-process-settings.csv]
2026-08-31 Round-3 batch reworked to one filament setting everywhere: temps and speeds drawn once by seeded Sobol (formally the best-predicted specimen's print parameters, trial 31 by lowest predicted t180), pe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
    [t3-prism-bo-suggestions-round3.csv]
2026-08-31 Print-process bounds tightened around the proven settings and the round-3 batch regenerated: infill 12-35%, PLA 212-228 C / 20-30 mm3/s, TPU 235-245 C / 2.2-3.6 mm3/s (was 10-60%, 200-235 C / 15-30, 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
    [t3-prism-bo-suggestions-round3.csv]
2026-08-31 Round-3 print files: 18 per-trial STLs and the H2D MM project, rendered at the solved constant-printed-mass geometry. New t3_prism_printed_mass_plate.py renders each article from the canonical t3-pri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
    [t3-prism-bo-round3-designs.csv, t3-prism-bo-round3-t28-cables.stl, t3-prism-bo-round3-t28-struts.stl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]
2026-09-06 Round-3 (drran) drop data ingested: 9 sessions x 20 drops mapped to trials 28-36, measured figure set, first mass-model validation at varied infill
    drran1-9 = the round-3 plate print 1 (ctrhjk print log, issue 98), photo-confirmed
    onto the plate's back-left-to-front-right raster (t35 twist / t29 tallest / t32
    widest / t28-30-33 clone trio signatures). Summary + per-drop numbers snapshotted
    from the PR #86 branch drran-checkin @ 308554e (same pipeline as rounds 1-2).
    Constant-printed-mass projection verdict: batch CV 1.7% (vs 5.9% round 1, 8.6%
    predicted round 2) with a -0.52 g systematic bias vs the 20.23 g target (residual
    sd 0.25 g inside the 0.38 g calibration residual); 2dran second prin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
    [t3-prism-bo-round3-drop-results.csv, t3-prism-bo-round3-per-drop-metrics.csv, t3-prism-bo-round3-predictions.csv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]
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2026-09-08 Round-4 print files: 18 per-trial STLs and the H2D MM project at the solved constant-printed-mass geometry. Rendered from the canonical t3-prism.scad at the round-4 suggestions CSV's scales (trials 3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
    [t3-prism-bo-round4-designs.csv, t3-prism-bo-round4-t37-cables.stl, t3-prism-bo-round4-t37-struts.stl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]
2026-09-08 Recover the round-4 slice-validation fixes from the failed push (job 34173817910): force the identity build-item transform (the CLI assembler auto-arranged the composite, rotating the whole round-4 p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
2026-09-08 Round-4 print files regenerated with the slice-validation fixes: same 18 solids as 6e93e04 (byte-identical geometry, re-measured: printed_g_est 19.92-20.64 g vs the 20.23 g target, worst +0.41 g at t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
    [t3-prism-bo-round4-designs.csv, t3-prism-bo-round4-t37-cables.stl, t3-prism-bo-round4-t37-struts.stl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]
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2026-09-15 Adopt the lab's confirmed corny key (me-madsen's annotated plate photo, PR #86 comment 5673269973): right plate column top-to-bottom = corny1/2/3, center = corny4/5/6, left = corny7/8/9, the unique r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
    [t3-prism-bo-round4-drop-results.csv, t3-prism-bo-round4-print-key.csv]
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2026-09-15 Round-5 print files: 18 per-trial STLs (trials 46-54) + H2D MM slicer project at the constant-printed-mass geometry.
    Rendered by t3_prism_printed_mass_plate.py from t3-prism-bo-suggestions-round5.csv at the solved scales (0.7313-0.9037, no re-solve). Rendered-mass verification: printed_g_est 19.88-19.94 g vs the 20.23 g target, worst |delta| 0.35 g, inside the mass model's 0.38 g analytic-to-rendered residual (all nine on the low side, same one-sided pattern as rounds 3-4). 3mf verified by unzip: PLA 223 C / 24.7 mm3/s, TPU 240 C / 3.0 mm3/s (no preset swap needed), Bambu TPU 85A @BBL H2D preset, all 18 per-part sparse-infill overrides matching the suggestions CSV, struts->extruder 1 / cable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
    [t3-prism-bo-round5-designs.csv, t3-prism-bo-round5-t46-cables.stl, t3-prism-bo-round5-t46-struts.stl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]
2026-09-15 Record the round-5 headless slice check: BambuStudio v02.07.01.62 on the exact committed 3mf, exit 0, all 9 trials on one plate, zero error/conflict/outside lines. 333 layers, model time 13h 24m, 182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
2026-09-15 Ingest the 2dran reprint sessions as nine distinct Ax trials (design-level repeats of trials 28-36)
    The round-3 plate was printed twice (drran 09-02, 2dran 09-05); the nine
    2dran drop sessions (2026-09-05/08/09, 20 drops each) are snapshotted
    from the PR #86 branch's 2dran-checkin (a10d890) into
    t3-prism-bo-round3-reprint-drop-results.csv (+ per-drop metrics, 162
    stabilized rows, same validity filter and 2-drop warmup discard). Each
    2dranN attaches as its own trial at its own weighed mass (19.48-20.32 g,
    round-3 print key), deliberately NOT pooled with drranN: repeated
    designs are how Ax infers the noise floor the per-drop SEM understates
    (print-to-print + seat + rig state; the 2dran session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
    [t3-prism-bo-round3-reprint-drop-results.csv, t3-prism-bo-round3-reprint-per-drop-metrics.csv]
2026-09-15 LOGO-CV mode + drran/2dran pair statistics
    t3_prism_bo_diagnostics.py grows --group-cv (with --cv-only):
    leave-one-DESIGN-out cross-validation where a reprint pair is one fold,
    so neither session of a repeated design leaks into the fold that tests
    the other (plain folds=-1 LOO would leave the twin in training and the
    GP reads it at nearly the same coordinates). Folds via
    ModelBridge.cross_validate on manually grouped observations, refits per
    fold exactly like the LOO path (refit_on_cv=True); writes -logocv
    tagged CSV/JSON/PNG. Label mapping extended to rounds 3-reprint and 4
    (the corny arms were falling back to arm names in a 44-article run).
    t3-prism-bo-round3-repeatability.csv: the nine d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
    [t3-prism-bo-round3-repeatability.csv]
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2026-09-15 Round-5 LOGO-CV: leave-one-design-out over all 44 articles, reprint pairs share a fold
    35 design folds (nine drran/2dran pairs held out together, singletons
    alone), NUTS refit per fold at 64/128 to fit the session (direction-
    stable vs the 128/256 the earlier LOOCVs used; re-run without the
    --cv-* flags for exact comparability). With the leakage closed and the
    repeats in the fit: t180 MAPE 5.0 pct, r +0.22, rank corr +0.08;
    e_reb_mJ MAPE 39.4 pct, r -0.38, rank corr -0.38. The rebound ordering
    flipping negative against the round-4 naive-LOO +0.30 says the earlier
    apparent rebound skill was partly the model predicting print luck,
    which is the model-side view of the 0.38x-2.9x repeat pair rati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
    [t3-prism-bo-round5-logocv.csv]
2026-09-15 Fix the CV parity footnote: the per-panel stats list shadowed the note parameter (the LOGO figure printed a list repr instead of the group-fold explanation); re-render with the note anchored below th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
2026-09-16 Round-5 print files (trials 55-63): 18 per-trial STLs + H2D MM slicer project at the constant-printed-mass geometry
    Rendered by t3_prism_printed_mass_plate.py from the regenerated
    44-article batch (ece35c5) at the CSV's solved scales, no re-solve.
    This is the first render of the 55-63 batch; the superseded 46-54
    print files remain retired (readable at 7ab85d9/e25ebf5). Manifest
    carries the rendered-mass verification against the 20.23 g target;
    3mf verified by unzip (objects Trial 55-63, struts extruder 1 /
    cables extruder 2, PLA 223 C / 24.7 mm3/s, TPU 240 C / 3.0 mm3/s,
    all 18 per-part sparse-infill overrides, identity build transforms,
    H2D dual-nozzle state, wipe tower (287, 110), Auto For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
    [t3-prism-bo-round5-designs.csv, t3-prism-bo-round5-t55-cables.stl, t3-prism-bo-round5-t55-struts.stl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]
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2026-09-23 Replicate study plan (3 designs x 9 articles): proposed picks corny7/corny8/corny2, pre-registered rank-check references (measured, LOGO held-out, frozen round-4), power analysis from the drran/2dran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
    [t3-prism-replicate-study-picks.csv, t3-prism-replicate-study-power.csv]
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2026-10-13 Replicate plates 2 and 3 print the plate-1 gcode: one layout, one file
    The lab prints the plate-1 gcode three times instead of rearranging the
    duplicates on each plate (@achris0520, PR #102, 2026-10-13), so 2sneXY and
    3sneXY sit exactly where 1sneXY does.
    - t3_prism_replicate_plates.py: one fixed Latin-square layout for every
    plate (the plate-1 square of the old cycled layout); only the plate-1
    project is written, and it regenerates byte-identical (sha256_12
    ec1976b6bf8c, the file slice-checked on 2026-09-28). dran3 project and
    the other figures also regenerate byte-identical.
    - Print key: 2sne/3sne rows moved to the plate-1 positions, slicer_project
    points at the plate-1 file for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
